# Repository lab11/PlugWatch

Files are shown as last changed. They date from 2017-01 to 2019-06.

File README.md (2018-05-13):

# PlugWatch



PlugWatch is part of the [GridWatch](http://grid.watch) project.

Unlike GridWatch, PlugWatch is not designed to run on everyday phones, rather it uses dedicated
smartphones as a sensor platform. PlugWatch is designed to be deployed as a semi-permanent installation,
with the phone constantly plugged into the power grid. PlugWatch also integrates with Bluetooth-enabled
commercial power meters, such as the [Wit Energy](http://www.wittech.net/WiTenergy.html), to collect
analytics such as line voltage not available to the phone alone.

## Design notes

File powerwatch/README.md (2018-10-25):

PowerWatch
==========

A custom PCB for identifying and distinguishing power outages. Acts as a source
of ground truth data for GridWatch.

Organized into different folders
./hardware - holds both board designs and case designs split by revision
./firmware - holds particle and nrf firmware split by revision
./cloud - holds the newest cloud backend infrastructure
./deployment-tools - holds all the software to support the deployment of physical devices and provision devices

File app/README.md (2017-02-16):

PlugWatch Application
=====================

This document describes the general behavoir of PlugWatch.

PlugWatch Operation
-------------------

PlugWatch runs the GridWatch service, which monitors the charging state of the phone and reports
a [GridWatch event](#gridwatch-event) whenever the charging state changes (note: unlike GridWatch,
PlugWatch reports every charge state event change, even if it was determined that this outage was
not due to a power outage).

PlugWatch also runs the WitCollect (**?? Name**) service, which connects to a nearby
[WiTenergy](http://www.wittech.net/WiTenergy.html) power meter to collect additional data. PlugWatch
samples Wit data every second (** DOUBLE CHECK **) and generates a [WitData](#witdata) entry for every sample (**and transmits every sample to the server in real time?? **).

**XXX is this right?**
GridWatch and Wit data are stored in a local database. PlugWatch creates a new database every 24
hours. Every 24 hours, PlugWatch performs a [BatchUpload](#batchupload) of yesterday's database.

In addition to its primary faculites, includes two diagnostics mechanism. First, every 24h the app
generates a [Heartbeat Ping](#heartbeat-ping) that simply sends a message to the server indicating
this phone is alive. Additionally, PlugWatch tracks [Internal Analytics](#internal-analytics),
which are used to diagnose the app and the deployment. These analytics leverage the Firebase tool
to automatically synchronize data **XXX often via an alaram / via FB on phone service?**

### GridWatch event

TODO: 

### WitData

TODO

### BatchUpload

TODO

### Heartbeat Ping

TODO

### Internal Analytics

These metrics are collected to diagnose the health of the PlugWatch app and deployment, and to help
diagnose issues that may arise.

Internal analytics are reported to Firebase via **XXX**, they are sent periodically via **XXX** or
on the following set of events **XXX (app restart, others?)**. **TODO:** Analytics reporting is throttled
to at most 1 report per hour.

**TODO: Update with actual names used in Firebase / data format**

_Reported as of 2017-02-14:_

  - All commands recevied
    - via SMS
    - via Firebase
  - Number of GridWatch events
  - App Version
  - IMEI
  - Phone Location
  - Phone Experimental ID
  - Phone Experimental Group ID
  - Number of databases
  - All crashes

_To add:_

  - Analytics ID counter
  - Packet counts
    - Bluetooth received
    - Cellular sent/received
  - Wakeup counts
    - Counter for each wakeup path in the app (each callback essentially)
  - Disk usage
  - App memory usage
  - Phone battery level
  - Current charging current
  - Estiamted app battery usage / imapact (w/e the OS gives)
  - Time phone last rebooted
  - Time app last rebooted
  - Time last analytics report sent (before this one)

Wishlist
--------

  - Nearby WiFi SSIDs
  - Compression for database sends. 
  - Periodic "Wit still not reachable" message transmissions - don't rely (solely) on watchdogs killing-and-restarting app to cause these to be generated only on re-start. As reliability increases may wish to have less aggressive watchdog that lets app running longer to increase chances of capturing exactly when power returns.
  - Option for "near" real-time bulk upload of Wit readings - e.g. N minutes worth at a time. Maybe only do bulk/trigger bulk send if voltage within a "normal" range.

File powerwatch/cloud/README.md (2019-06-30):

PowerWatch Cloud Services
=========================

The powerwatch cloud is a set of services that consume data from sensors,
store that data, visualize the data, manage the sensor deployment, send
feedback about performance to the field team, and pay our participants.

This is broken down in to a set of discrete services that run in K8s.

Some of these services (like timescale and grafana) are pre-existing and
we just write manifests for them. Some of them we write ourselves and 
build Docker containers for.

A picture of the current architecture is outlined below.



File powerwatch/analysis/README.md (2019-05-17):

Running PowerWatch Analysis
===========================

This folder is setup to execute pyspark scripts on a cloud dataproc cluster

These should work on any gcloud project with the dataproc enabled and billing enabled.

I usually use the powerwatch-backend gcloud project.

## Executing scripts

If you want to run one script you can simply 

```
$ ./execute.py my_analysis_folder/my_analysis_script.py
```

This script will in order
 - Check if a cluster exists, create a cluster if it does not. Cluster shuts down after 30 minutes of inactivity.
 - Setup the cluster environment to run the script (including drivers and such)
 - Execute the analysis script and pass in the results location
 - Copy the resulting csv(s) into the folder with the script
 - Hang until done and print output from the job

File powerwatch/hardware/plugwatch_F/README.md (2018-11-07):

# Plugwatch F
This sensor board is part of the [GridWatch](http://grid.watch) project.

Small fixes for at scale production of plugwatch.

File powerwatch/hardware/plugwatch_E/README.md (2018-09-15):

# Electron Sensor Board Rev 5
This sensor board is part of the [GridWatch](http://grid.watch) project.

Mostly a set of small fixes to the rev 4 board

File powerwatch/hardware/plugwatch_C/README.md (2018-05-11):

# Electron Sensor Board Rev 3
This sensor board is part of the [GridWatch](http://grid.watch) project.

The goal of this board is to test data collection in Accra. It contains 
an IMU with accel/mag and temp, two different microphones (one analog and
one digial), some memory, and a ultra-low power timer for future low-power 
optimizations. 

This directory will host development for all electron software and firmware.

Getting Started
---------------

Install the `particle-cli`, ideally just:

    npm install -g particle-cli

But I had to then also:

    npm i -g node-gyp
    ls ~/.particle     # note node version, mine was v5.4.1
    nvm use 5.4.1
    cd ~/.particle/node_modules/serialport
    node-gyp rebuild

Then blow out that terminal becase you don't really want that `nvm use` to persist.
If everything's hunky dory, you can now run `particle --version` or some such.

#### Installing dfu-util For Flashing Firmware

In order to use "particle flash" to locally re-flash the Electron firmware over USB, you will need dfu-util installed. On MacOS this should be sufficient:

    brew install dfu-util
    
Particle docs have more details for getting them on Windows or with MacPorts: https://docs.particle.io/faq/particle-tools/installing-dfu-util/core/

### Compiling

    particle compile electron
    
#### Using the Particle IDE

Particle has extended the Atom IDE to make a "Particle Dev" app: https://docs.particle.io/guide/tools-and-features/dev/

It's really not that different that the web IDE, including actually sending compilation to their cloud, but it allows you to work with local git-controlled files (like these!), and also importantly doesn't have the horrible mouse scrolling behavior of the web IDE that often leads to accidental "browser back" commands that lose your edits.

Install Particle Dev from the link above, run it, and:

* File->Open-> navigate to the `software/firmware/` directory of this code and select "open" (do not choose any individual file in it).
* Choose `Electron` as the target device in the bottom bar icon (may default to `Photon`). NOTE: you may have to do this regularly (e.g. every time you restart the IDE or re-open your project).
* Log in to your particle account if it doesn't show you already logged in (left side of bottom bar or Particle-> menu).
* Compile using the Cloud+Checkmark icon in the left bar.
    
If all goes well you should see `Compiling in the cloud...` in the bottom bar and then a `Success!` message, and the firmware binary should appear in the `firmware/` directory with a name that looks like `electron_0.7.0_firmware_XXXXXXXX.bin`.

Note: if you hit the compile button and it instantly reports `Success!` without delay, and doesn't actually produce a firmware image, it probably means that despite showing you aslogged in that you need to logout and re-login.

#### Compiling Locally

The paricle CLI and IDE will use the cloud still, which is annoyingly slow IMHO.
While there's theoretically a path to _actual_ local compilation, down that road
lies madness. Your best bet is their [Atom plugin](https://atom.io/packages/particle-dev-local-compiler).
You'll need to install and run Docker first, then in Particle Dev go to Settings->Install, search for 
"Particle Dev Local Compiler" and click install. Compiles are still slower than I'd like,
but only a few seconds at least. 

#### Cryptic error / error you didn't have before?

For example `error: 'LOW_BAT_UC' was not declared in this scope`

Make sure that you're building for the right device (an `electron`).
The IDE in particular tends to like to forget what you're building for,
especially across open/closing.

### Claim the particle (must do once)

  0. Plug in particle via USB
  1. Enter 'listening mode': Hold `MODE` button for three seconds, until the
     LED starts blinking blue.
  2. `particle identify`
  3. `particle device add <device id from last step>`

### Flashing

  1. Enter 'dfu mode': Reset and then hold `MODE` button for three seconds,
     until the LED starts blinking yellow.
  2. `particle flash --usb <filename>.bin`
  
#### Flashing made easier

`stty -f /dev/tty.usbmodem14321 14400 && particle flash --usb $(ls -t | grep firmware | head -1)`

The first part puts the particle into DFU mode. Note that you'll need to replace the `14321` in the above with whatever ID the USB Particle shows up on your machine (just use tab-completion).  The last part chooses the most
recent file based on filesystem timestamp.
  
### Listening to Serial

I recommend `particle serial monitor --follow`

Annoyingly, every time the particle resets, the modem disappears and reappears.
The `--follow` flag will automatically reconnect, but there's a bit of a delay,
so you're gonna lose the first few messages. I've never solved this puzzle.

### Listening to the Event Stream

The `Particle.publish()` command allows electron-initiated events to be published to the Particle Cloud; webhooks can then be used to do something with these events. However webhooks need to be specified per event name (or event name's starting prefix), which is somewhat obnoxious for development. 

Thankfully the entire event-stream for a Particle "product" is available as an HTML5 Server Side Event; the stream is accessible per-product via a URL like https://api.particle.io/v1/products/PRODUCT_SLUG/events?access_token=TOKENVALUE

where `PRODUCT_SLUG` (Particle terminology) is the short alpha-numeric name of the product (to get this click on a specific product in the Particle web console https://console.particle.io/products and pull the "slug" from the resulting URL, e.g. https://console.particle.io/PRODUCT_SLUG/devices).

#### Generating an API Token

As you see above the API requires an access token; this can be generated from the Web UI but the following code is useful for generating one with no expiration (which can be useful to avoid a situation like where your curl script for dumping the event stream doesn't check for API access errors and thus you get email from Particle complaining about hammering their API with failed authentication attempts):

`curl https://api.particle.io/oauth/token -u particle:particle -d grant_type=password -d 'username=YOUR_PARTICLE_ACCOUNT_EMAIL_ADDRESS' -d 'password=YOUR_PARTICLE_ACCOUNT_PASSWORD’ -d 'expires_in=0'`

The particle account should be one with access to the product(s) whose event streams you want to listen to. `particle:particle` is *NOT* a placeholder; it's ignored so you can leave it as is. The `-d 'expires_in=0'` is the key to creating the infinite-life token. If successful you should see curl return something like:

`{"token_type":"bearer","access_token":"0123456789abcdef0123456789abcdef01234567",
{"token":"0123456789abcdef0123456789abcdef01234567","expires_at":null,"client":"__PASSWORD_ONLY__"}`

You can then paste the `access_token` value into the `TOKENVALUE` part of the API URL above.

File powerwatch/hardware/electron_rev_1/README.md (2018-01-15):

# Electron Sensor Board Rev 1
This sensor board is part of the [GridWatch](http://grid.watch) project.

The goal of this board is to test data collection in Accra. It contains 
an IMU with accel/mag and temp, two different microphones (one analog and
one digial), some memory, and a ultra-low power timer for future low-power 
optimizations. 

The current version is built to be deployed inside. Eventually, this platform
will be both indoors and solar powered. Right now, the peripherals are not
selected for low power... Instead, they are selected because I've used them before. 

Eventually, there will only be a single type of microphone. I believe this will be
the digital mic, but I don't have the I2S driver written yet, so I'm including the 
analog mic as a backup. 

We will likely be building 10 of these and then redesigning.

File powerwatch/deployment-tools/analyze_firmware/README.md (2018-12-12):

Analyze Firmware
==========================

Prints product ID and version of firmware.

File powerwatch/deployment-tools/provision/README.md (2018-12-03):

Particle provisioning script
===========================

The script performs several functions:

1) Updates the core firmware on each particle to 0.7.0
2) Flashes the pre-deploy firmware which waits for a firmware update
3) Gets the device ID of the particle and appends it to a google spreadsheet for tracking
4) Gets the board ID of a particle to associate it with a specific plugwatch board
4) prints labels with the board ID and device ID for the plugwatch cases

## Usage

### Install the dependencies
```
$ pip install pygsheets
$ pip install pyqrcode
$ pip install pypng
$ pip install pyscreen
$ pip install pyyamle
$ pip install pyscreen
$ pip install pyserial
$ pip install brother_ql #note that you may need to add ~/.local/bin to your path
$
$ npm install -g particle-cli
```

You need to install dfu util - this is system dependent, but on mac
```
$ brew install dfu-util
```

Note that you may need to install brother_ql with sudo -H to be able to access
it when you run the claim script as sudo.

### Setup keys

https://pygsheets.readthedocs.io/en/latest/authorization.html

At a high level you need to enable the google drive and google sheets APIs,
the create a consent form and a client oauth crediential.

You must also put a valid particle auth token in the particle-config.json file

### Run the script

Connect the particle and the printer to run the script.

```
$ sudo ./claim.py -p PRODUCT_ID
```

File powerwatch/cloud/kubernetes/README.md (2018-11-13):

Deploying a Powerwatch Backend
==============================

## Requirements

To deploy a powerwatch backend instance you need to have google cloud installed
and logged into a google account which has been granted an admin role on the 
powerwatch-backend project.

To check:
```
gcloud config set project powerwatch-backend
```

## Start a new powerwatch backend

To startup a new powerwatch backend you should 
run the provisioning script with the deployment name and particle product IDs
```
$ ./powerwatch_provision.py --name venezuela --product 7300 --product 7301
```

This will perform the following steps

1) Create a default cluster in gcloud under the powerwatch-backend project
2) Generate, substitute and print passwords for the following individual services:
timescale (admin user, poster user, grafana user)
influxdb (admin user, poster user, grafana user)
grafana (admin user)
3) Generate and substitute a particle auth token for those products
4) Packages up all the deployment files and 
save them to a deployment folder
5) Deploy a new timescale, influx, grafana, and the powerwatch poster services
to the target cluster
6) Print the IP address of the grafana ingress so that you can configure a new
subdomain for this deployment's grafana

## Update a powerwatch backend
The powerwatch-data-poster and powerwatch-visualization pods are custom pods
running images hosted by the lab11 docker hub. They are currently set to pull
the production branch of this repository. To update these images:

1) Push your changes to the production branch (probably just merge production with master or test).
2) Wait for docker hub to build the images
3) Pull the images - copy down their sha256 hash
```
$ docker pull lab11/container-name:production
```
4) Point your kubectl at the cloud cluster you are updating (copy the 'connect' command text from the gcloud web UI)
5) Update the images to the sha256 hash. For instance to update the influx poster run the following command:
```
$ kubectl set image deployment powerwatch-data-poster powerwatch-influx-poster=lab11/powerwatch-influx-poster@sha256:HASH
```

You can also update multiple images at once. This will perform a no-downtime rolling update of the containers that you specified.

Pointing to a commit hash is better than a branch because it enables easier rollback and it is easier to identify exactly
which version of a container you are running (if you just pull the 'production' container 
docker hub's production tag will get out of sync with the tag running in the cluster as more commits are pushed).

## Future Work

There are several clear things that need updating moving forward:

 - The internal cluster communications should use SSL
 - We need to get the powerwatch visualization up and running and get its SSL working
 - Make a splash page for the each deployment
 - Potential hooks to lastpass for password storage for the group

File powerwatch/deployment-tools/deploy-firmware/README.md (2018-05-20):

Firmware Deployment Script
==========================

The firmware deployment script takes a product binary, uploads it,
releases it to a product, then locks all devices in that product
to the firmware release.

The locking step seems to help devices better upgrade. I don't really understand
why that is the case.

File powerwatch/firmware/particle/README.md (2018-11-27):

Plugwatch sensor firmware
=========================

This folder holds all firmware running on plugwatch sensors. Currently
the two active sub-folders are plugwatch_C and plugwatch_F. 
Other folders hold testing revisions.

Firmware versioning is a 6 digit decimal number. 
Plugwatch C firmware starts at 000000 and plugwatch F firmware starts at 000100.

##Revision list
 - 000026 - Currently deployed on Ghana and Venezuela
 - 0000100 - The most recent version of the new firmware. Still in development, not deployed.

##To deploy firmware

 1) Commit your changes with the new version number.
 2) Build the versions for all of the product IDs and APNs - a script to do this will be coming soon.
 3) Push your builds to the particle cloud using the firmware deployment script - soon to be modified to take a folder of builds
 4) Commit the most recent firmware build folder

Getting Started with Firmware Development
-----------------------------------------

Install the `particle-cli`, ideally just:

    npm install -g particle-cli

But I had to then also:

    npm i -g node-gyp
    ls ~/.particle     # note node version, mine was v5.4.1
    nvm use 5.4.1
    cd ~/.particle/node_modules/serialport
    node-gyp rebuild

Then blow out that terminal becase you don't really want that `nvm use` to persist.
If everything's hunky dory, you can now run `particle --version` or some such.

### Compiling

    particle compile electron
    
#### Compiling Locally

The paricle CLI will use the cloud still, which is annoyingly slow IMHO.
While there's theoretically a path to _actual_ local compilation, down that road
lies madness. Your best bet is their [Atom plugin](https://atom.io/packages/particle-dev-local-compiler).
You'll need to install Docker first. Compiles are still slower than I'd like,
but only a few seconds at least.

#### Cryptic error / error you didn't have before?

For example `error: 'LOW_BAT_UC' was not declared in this scope`

Make sure that you're building for the right device (an `electron`).
The IDE in particular tends to like to forget what you're building for,
especially across open/closing.

### Claim the particle (must do once)

  0. Plug in particle via USB
  1. Enter 'listening mode': Hold `MODE` button for three seconds, until the
     LED starts blinking blue.
  2. `particle identify`
  3. `particle device add <device id from last step>`

### Flashing

  1. Enter 'dfu mode': Reset and then hold `MODE` button for three seconds,
     until the LED starts blinking yellow.
  2. `particle flash --usb <filename>.bin`
  
#### Flashing made easier

`stty -f /dev/tty.usbmodem14321 14400 && particle flash --usb $(ls -t | grep firmware | head -1)`

The first part puts the particle into DFU mode. The last part chooses the most
recent file based on filesystem timestamp.
  
### Listening to Serial

I recommend `particle serial monitor --follow`

Annoyingly, every time the particle resets, the modem disappears and reappears.
The `--follow` flag will automatically reconnect, but there's a bit of a delay,
so you're gonna lose the first few messages. I've never solved this puzzle.

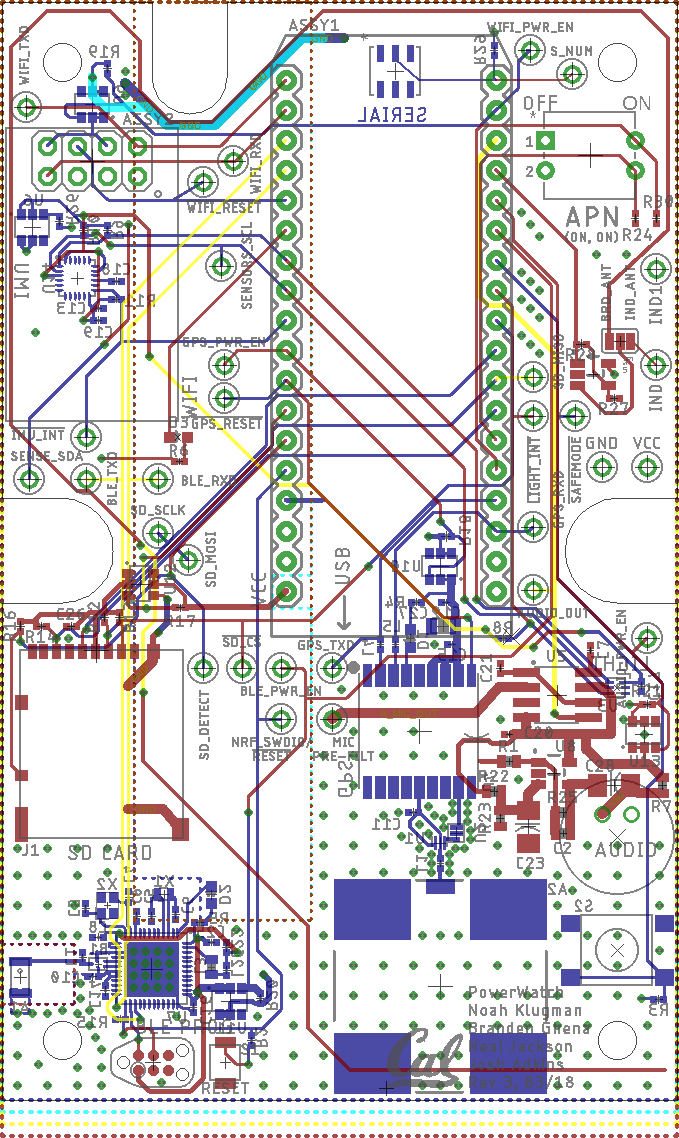
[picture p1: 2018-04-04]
powerwatch/hardware/plugwatch_C/board/plugwatch_pcb.png

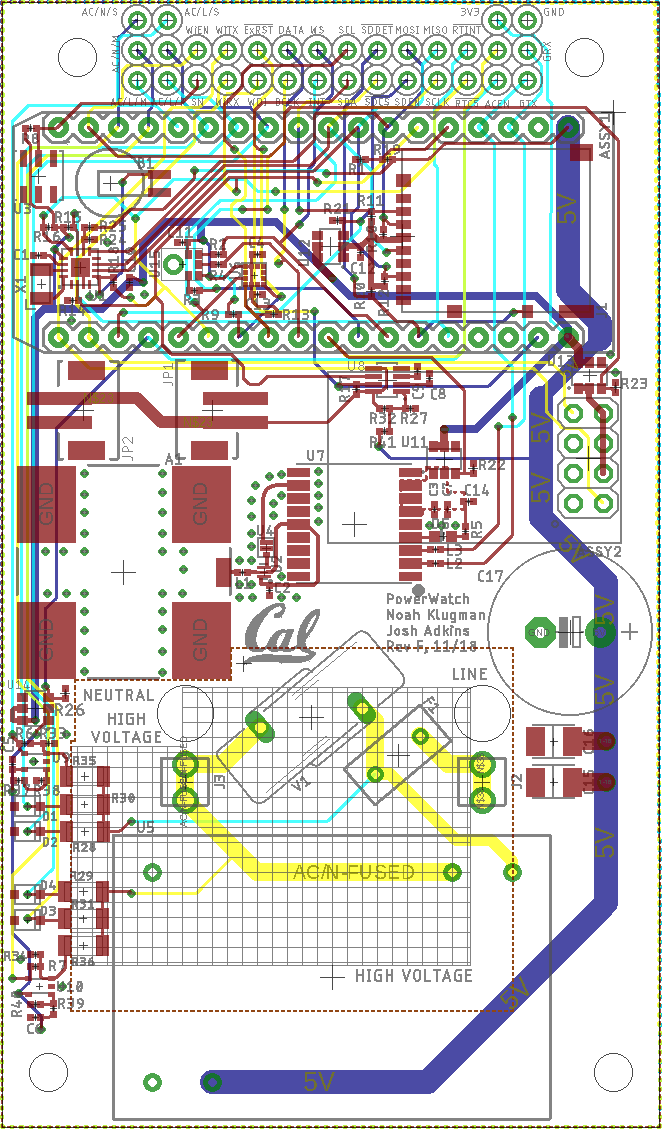
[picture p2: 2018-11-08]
powerwatch/hardware/plugwatch_F/board/plugwatch_pcb.png

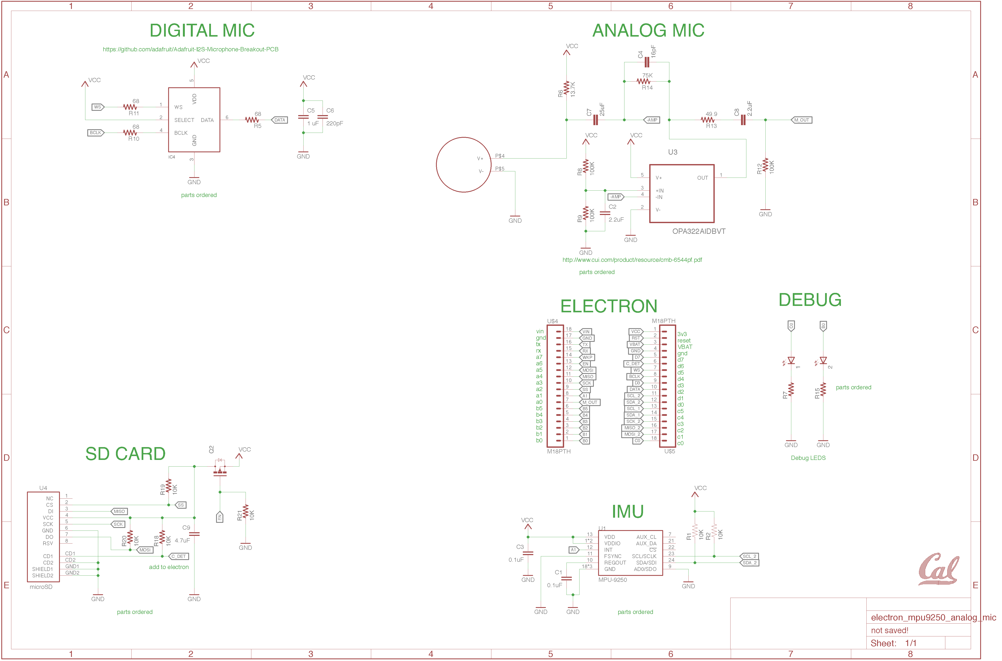
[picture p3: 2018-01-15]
powerwatch/hardware/electron_rev_1/schematic_image.png

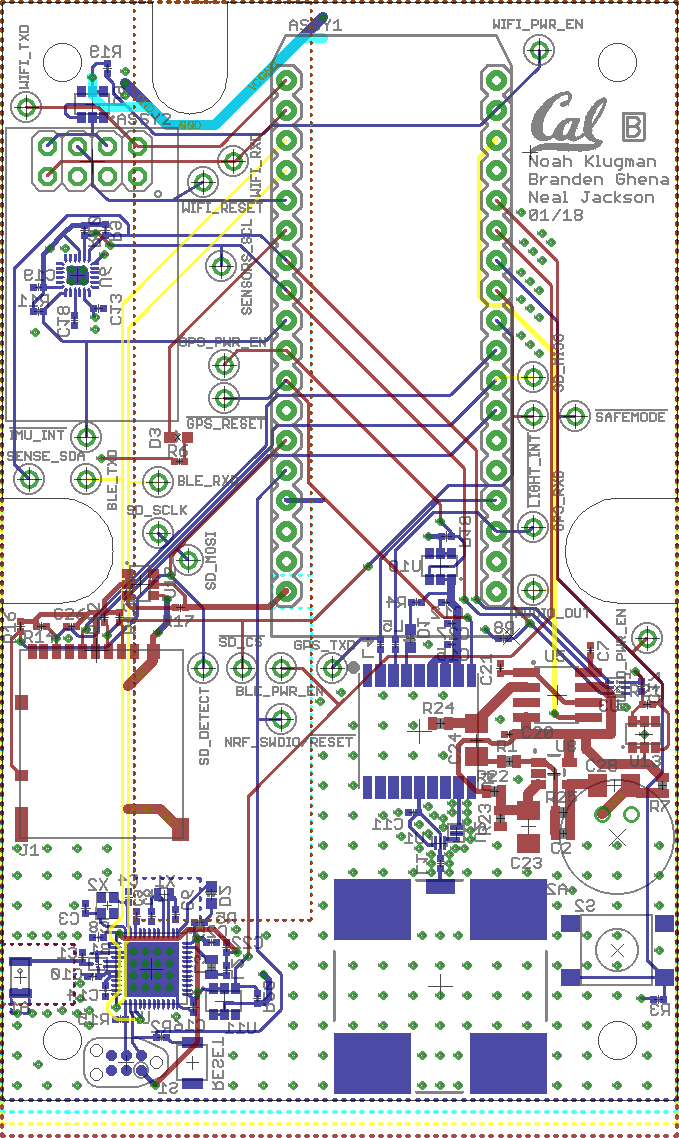
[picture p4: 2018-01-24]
powerwatch/hardware/plugwatch_B/board/plugwatch_pcb.png

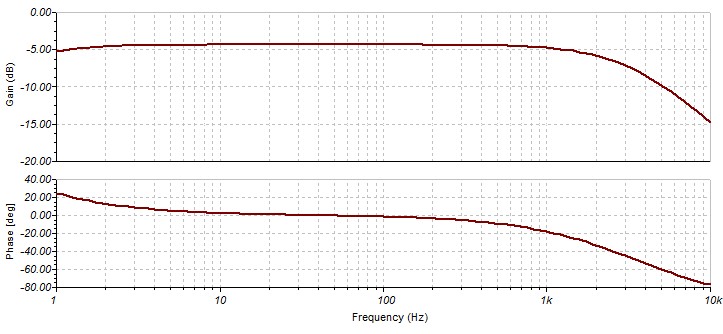
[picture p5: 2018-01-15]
powerwatch/hardware/plugwatch_B/board/simulation/transfer_function.jpg

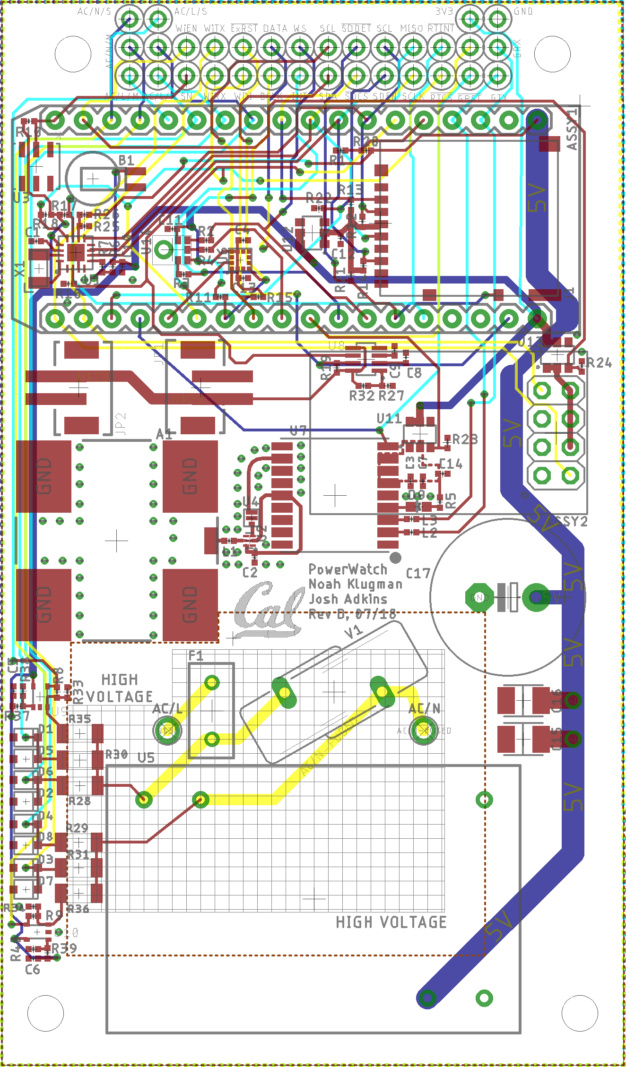
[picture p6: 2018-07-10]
powerwatch/hardware/plugwatch_D/board/plugwatch_pcb.png

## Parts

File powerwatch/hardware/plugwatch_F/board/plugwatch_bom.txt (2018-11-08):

# Bill of Materials
# Converted from plugwatch_bom.xlsx
# Generated by bom_to_text.py
#
# # Bill of Materials                                                                                                                                                                                                                                                                                                                                             
# # Converted from {}                                                                                                                                                                                                                                                                                                                                             
# # Generated by bom_to_text.py                                                                                                                                                                                                                                                                                                                                   
# #                                                                                                                                                                                                                                                                                                                                                               
#                                                                                                                                                                                                                                                                                                                                                                 
# Qty                            Value                  Device                           Package                  Parts                                   Description                                                      DESCRIPTION                       DIGIKEY                  MANUFACTURER                      MOUSER             MPN                    SPICEPREFIX
4                                                       DIODE_ZENERSOT323                SOD323                   D1,D2,D3,D4                                                                                              DIODE ZENER 3.3V 200MW SOD323F    MM3Z3V3BCT-ND            ON Semiconductor                                     MM3Z3V3B               
2                                                       M024UCON-15767                   JST-2-SMD-VERT           JP1,JP2                                 Header 2                                                         CONN HEADER PH TOP 2POS 2MM SMD   455-1734-1-ND            JST Sales America Inc.                               B2B-PH-SM4-TB(LF)(SN)  
1                                                       MS518SE                          MS518SE-FL35E            B1                                      A small, low leakage rechargeable battery for RTC backup                                           728-1054-ND              Seiko                                                MS518SE-FL35E          
1                                                       SPH0645LM4H-B                    SPH0465                  U15                                     An I2S microphone down to 20hz                                                                     423-1405-1-ND            Knowles                           721-SPH0645LM4H-B  SPH0645LM4H-B          
4                                0.1uF                  CAPACITOR0402_CAP                0402_CAP                 C4,C5,C6,C7                             SMD Capacitor                                                    CAP CER 0.1UF 10V X5R 0402        311-1336-1-ND            Yageo                                                CC0402KRX5R6BB104      
1                                0.82uF                 CAPACITOR0402_CAP                0402_CAP                 C9                                      SMD Capacitor                                                                                      490-10440-1-ND           Murata Electronics North America                     GRM155C80J824KE15D     
7                                100k                   RESISTOR0402_RES                 0402_RES                 R20,R21,R22,R23,R24,R25,R26             Resistor                                                         RES SMD 100K OHM 1% 1/16W 0402    311-100KLRCT-ND          Yageo                                                RC0402FR-07100KL       
2                                100uF                  CAPACITOR1210_CAP                1210_CAP                 C15,C16                                 SMD Capacitor                                                    CAP CER 100UF 10V X5R 1210        490-9969-6-ND            Murata Electronics North America                     GRM32ER61A107ME20L     
10                               10k                    RESISTOR0402_RES                 0402_RES                 R9,R10,R11,R12,R13,R14,R15,R16,R17,R18  Resistor                                                         RES SMD 10K OHM 1% 1/16W 0402     311-10.0KLRCT-ND         Yageo                                                RC0402FR-0710KL        
2                                10nF                   CAPACITOR0402_CAP                0402_CAP                 C2,C3                                   SMD Capacitor                                                    CAP CER 10000PF 16V X7R 0402      490-4762-1-ND            Murata Electronics North America                     GCM155R71H103KA55D     
2                                10uF                   CAPACITOR0402_CAP                0402_CAP                 C13,C14                                 SMD Capacitor                                                    CAP CER 10UF 6.3V X5R 0402        490-13211-1-ND           Murata Electronics North America                     GRJ155R60J106ME11D     
4                                1M                     RESISTOR0402_RES                 0402_RES                 R37,R38,R39,R40, R41                    Resistor                                                         RES 1M OHM 1% 1/16W 0402          311-1.00MLRCT-ND         Yageo                                                RC0402FR-071ML         
2                                1k                     FERRITE_BEAD0402                 0402_CAP                 L2,L3                                                                                                    FERRITE BEAD 1 KOHM 0402 1LN      490-4003-1-ND            Murata                                               BLM15HD102SN1D         
1                                1k                     RESISTOR0402_RES                 0402_RES                 R5                                      Resistor                                                         RES SMD 1K OHM 1% 1/16W 0402      311-1.00KLRCT-ND         Yageo                                                RC0402FR-071KL         
2                                1uF                    CAPACITOR0402_CAP                0402_CAP                 C10,C11                                 SMD Capacitor                                                    CAP CER 1UF 10V X7S 0402          490-13409-1-ND           Murata Electronics North America                     GCM155C71A105KE38D     
1                                2.2uF                  CAPACITOR0402_CAP                0402_CAP                 C8                                      SMD Capacitor                                                                                      490-10448-1-ND           Murata Electronics North America                     GRM155D71A225ME15D     
1                                2000uF                 CPOL-USE5-13                     E5-13                    C17                                     POLARIZED CAPACITOR, American symbol                             CAP ALUM 2000UF 20% 6.3V T/H      P122284TB-ND             Panasonic Electronic Components                      EEU-FS0J202B           C
1                                300VAC - 500ma         MICRO_FUSE500MA_350VAC           MIRCRO_FUSE_5MM          F1                                      A 5mm AC micro fuse package                                      FUSE BRD MNT 500MA 350VAC 100VDC  507-1903-ND              Bel Fuse Inc                                         0697H0500-01           
1                                34k                    RESISTOR0402_RES                 0402_RES                 R19                                     Resistor                                                         RES SMD 34K OHM 1% 1/10W 0402     P34.0KLCT-ND             Panasonic Electronic Components                      ERJ-2RKF3402X          
1                                4.7uF                  CAPACITOR0402_CAP                0402_CAP                 C12                                     SMD Capacitor                                                    CAP CER 4.7UF 6.3V X5R 0402       490-5408-1-ND            Murata Electronics North America                     GRM155R60J475ME87D     
2                                4.99k                  RESISTOR0402_RES                 0402_RES                 R6,R7                                   Resistor                                                         RES SMD 4.99K OHM 1% 1/10W 0402   P4.99KLCT-ND             Panasonic Electronic Components                      ERJ-2RKF4991X          
1                                47pF                   CAPACITOR0402_CAP                0402_CAP                 C1                                      SMD Capacitor                                                    CAP CER 47PF 100V C0G/NP0 0402    490-7307-1-ND            Murata Electronics North America                     GRM1555C2A470JA01D     
1                                499k                   RESISTOR0402_RES                 0402_RES                 R27                                     Resistor                                                         RES SMD 499K OHM 1% 1/10W 0402    P499KLCT-ND              Panasonic Electronic Components                      ERJ-2RKF4993X          
1                                5.1k                   RESISTOR0402_RES                 0402_RES                 R8                                      Resistor                                                         RES SMD 5.1K OHM 1% 1/10W 0402    P5.10KLCT-ND             Panasonic Electronic Components                      ERJ-2RKF5101X          
1                                5.6nH                  INDUCTOR0402                     0402_CAP                 L1                                      A very specific inductor                                         FIXED IND 5.6NH 1.77A 40 MOHM     490-11766-1-ND           Murata                                               LQW15AN5N6B80D         
1                                66.5                   RESISTOR0402_RES                 0402_RES                 R1                                      Resistor                                                         RES SMD 66.5 OHM 1% 1/16W 0402    YAG3210CT-ND             Yageo                                                RC0402FR-0766R5L       
3                                68                     RESISTOR0402_RES                 0402_RES                 R2,R3,R4                                Resistor                                                         RES SMD 68 OHM 1% 1/16W 0402      P68.0LCT-ND              Panasonic Electronic Components                      ERJ-2RKF68R0X          
4                                750k                   RESISTOR1206_RES_HIGH_CLEARANCE  1206_RES_HIGH_CLEARANCE  R28,R29,R30,R31                         Resistor                                                         RES SMD 750K OHM 1% 1/4W 1206     311-750KFRCT-ND          Yageo                                                RC1206FR-07750KL       
1                                825k                   RESISTOR0402_RES                 0402_RES                 R32                                     Resistor                                                         RES SMD 825K OHM 1% 1/10W 0402    P825KLCT-ND              Panasonic Electronic Components                      ERJ-2RKF8253X          
2                                953k                   RESISTOR0402_RES                 0402_RES                 R33,R34                                 Resistor                                                         RES SMD 953K OHM 1% 1/16W 0402    YAG3262CT-ND             Yageo                                                RC0402FR-07953KL       
2                                953k                   RESISTOR1206_RES_HIGH_CLEARANCE  1206_RES_HIGH_CLEARANCE  R35,R36                                 Resistor                                                                                           P953KBCCT-ND             Panasonic Electronic Components                      ERA-8AEB9533V          
1                                AB1815-T3              AB1815-T3                        QFN-16-3MM               U1                                      Ultra-low current RTC. 55nA quiescent @ 3V. 1.5-3.6V input.                                        535-11936-1-ND           Abracon                                              AB1815-T3              
1                                ABS07-32.768KHZ-7-T    ABS07-32.768KHZ-7-T              2-SMD                    X1                                      32.768kHz Crystal                                                                                  535-9543-1-ND            ABRACON                                              ABS07-32.768KHZ-7-T    
1                                BGA725L6-ALT           BGA725L6-ALT                     LNA-TSLP-6-2-ALT         U2                                                                                                       IC AMP MMIC RF LNA 20DB TSLP-6    BGA725L6E6327FTSA1CT-ND  Infineon                                             BGA725L6E6327FTSA1     
1                                BLUE                   LED0603                          LED-0603                 D5                                      LED                                                              LED BLUE CLEAR SMD                160-1837-6-ND            Lite-On Inc.                                         LTST-C194TBKT          
1                                DM3AT-SF-PEJM5         DM3AT-SF-PEJM5                   DM3AT-SF-PEJM5           J1                                      CONN MICRO SD R/A PUSH-PUSH SMD                                  CONN MICRO SD CARD PUSH-PUSH R/A  HR1964CT-ND              Hirose Electric Co Ltd                               DM3AT-SF-PEJM5         
1                                DS2401P+               DS2401P+                         21-0382                  U3                                      A one wire serial number chip.                                                                     DS2401P+-ND              Maxim Integrated                                     DS2401P+               X
1                                ELECTRON               ELECTRON                         ELECTRON_SINGLE-ROW      ASSY1                                                                                                    18 Position header                S7051-ND,S7051-ND        Sullins                                              PPPC181LFBN-RC         
1                                GPS-ANTENNA            GPS-ANTENNA                      ANT1818B00BT1516S        A1                                                                                                       PATCH ANT GPS/GLO CP SMD          311-1531-ND              Yageo                                                ANT1818B00BT1516S      
1                                IRM-03-5V              IRM-03-5V                        IRM-03                   U5                                      A 5V 3W board mount power supply                                                                   1866-3020-ND             Mean Well USA                                        IRM-03-5               
1                                LIS2DH12               LIS2DW12                         LGA-12                   U6                                      ultra low power 3 axis accelerometer                                                               497-14851-1-ND           STMicroelectronics                511-LIS2DH12TR     LIS2DH12TR             
1                                MAX-M8                 MAX-M8                           MAX-M8                   U7                                                                                                       IC RECEIVER GPS/GNSS 18LCC        672-1003-1-ND            u-blox                                               MAX-M8Q-0              
1                                MAX67XXMAX6749MAX67XX  MAX67XXMAX6749MAX67XX            SOT-23-8                 U8                                      A simple watchdog timer with adjustable timeouts and reset time                                    MAX6749KA+TCT-ND         Maxim Integrated                                     MAX6749KA+T            
2                                OPA369                 OPA369                           SC70-5                   U9,U10                                                                                                                                     296-25252-1-ND           Texas Instruments                                    OPA369AIDCKR           
1                                S14K385                S14K385                          S14K385                  V1                                      VARISTOR                                                         VARISTOR 620V 5KA DISC 14MM       495-5945-ND              EPCOS (TDK)                                          B72214S2381K101        
1                                SAFFB1G56KB0F0A        FILTERS                          QCS5I                    U4                                                                                                       FILTER SAW 1.582GHZ 5SMD          587-3990-1-ND            Taiyo Yuden                                          F6QA1G582H2JM-J        
2                                SCREW_TERMNIAL_1       SCREW_TERMNIAL_1                 360272-TERMINAL-BLOCK    J2,J3                                   A small, single terminal block                                                                     1849-1246-ND             METZ CONNECT USA Inc.                                360272                 
4                                SIP32510               SIP32510                         TSOT23-6                 U11,U12,U13,U14                         Load switch, slew rate controlled. By Vishay                                                       SIP32510DT-T1-GE3CT-ND   Vishay                                               SIP32510DT-T1-GE3      
1                                WRL-13678              WRL-13678                        WRL-13678                ASSY2                                   ESP8266 WiFi Module                                                                                1568-1235-ND

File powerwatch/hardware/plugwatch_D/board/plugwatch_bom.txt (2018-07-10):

# Bill of Materials
# Converted from plugwatch_bom.xlsx
# Generated by bom_to_text.py
#
# # Bill of Materials                                                                                                                                                                                                                                                                                                                                                                                                                                                             
# # Converted from {}                                                                                                                                                                                                                                                                                                                                                                                                                                                             
# # Generated by bom_to_text.py                                                                                                                                                                                                                                                                                                                                                                                                                                                   
# #                                                                                                                                                                                                                                                                                                                                                                                                                                                                               
#                                                                                                                                                                                                                                                                                                                                                                                                                                                                                 
# Qty                            Value                  Device                           Package                  Parts                                                                                                                                                   Description                                                      DESCRIPTION                       DIGIKEY                  MANUFACTURER                      MOUSER             MPN                    SPICEPREFIX
4                                                       DIODE_SCHOTTKYSOD323             SOD323                   D1,D2,D3,D4                                                                                                                                                                                                                                                CUS10S30H3FCT-ND         toshiba                                              CUS10S30,H3F           
4                                                       DIODE_ZENERSOT323                SOD323                   D5,D6,D7,D8                                                                                                                                                                                                              DIODE ZENER 3.3V 200MW SOD323F    MM3Z3V3BCT-ND            ON Semiconductor                                     MM3Z3V3B               
2                                                       M024UCON-15767                   JST-2-SMD-VERT           JP1,JP2                                                                                                                                                 Header 2                                                         CONN HEADER PH TOP 2POS 2MM SMD   455-1734-1-ND            JST Sales America Inc.                               B2B-PH-SM4-TB(LF)(SN)  
1                                                       MS518SE                          MS518SE-FL35E            B1                                                                                                                                                      A small, low leakage rechargeable battery for RTC backup                                           728-1054-ND              Seiko                                                MS518SE-FL35E          
1                                                       SPH0645LM4H-B                    SPH0465                  U14                                                                                                                                                     An I2S microphone down to 20hz                                                                                              Knowles                           721-SPH0645LM4H-B  SPH0645LM4H-B          
4                                0.1uF                  CAPACITOR0402_CAP                0402_CAP                 C4,C5,C6,C7                                                                                                                                             SMD Capacitor                                                    CAP CER 0.1UF 10V X5R 0402        311-1336-1-ND            Yageo                                                CC0402KRX5R6BB104      
1                                0.82uF                 CAPACITOR0402_CAP                0402_CAP                 C9                                                                                                                                                      SMD Capacitor                                                                                      490-10440-1-ND           Murata Electronics North America                     GRM155C80J824KE15D     
2                                1.5k                   RESISTOR0402_RES                 0402_RES                 R6,R7                                                                                                                                                   Resistor                                                         RES SMD 1.5K OHM 0.1% 1/16W 0402  P1.5KDCCT-ND             Panasonic Electronic Components                      ERA-2AEB152X           
6                                100k                   RESISTOR0402_RES                 0402_RES                 R21,R22,R23,R24,R25,R26                                                                                                                                 Resistor                                                         RES SMD 100K OHM 1% 1/16W 0402    541-100KLCT-ND           Vishay Dale                                          CRCW0402100KFKED       
2                                100uF                  CAPACITOR1210_CAP                1210_CAP                 C15,C16                                                                                                                                                 SMD Capacitor                                                    CAP CER 100UF 6.3V X7S 1210       490-10530-1-ND           Murata Electronics North America                     GRM32EC70J107ME15L     
9                                10k                    RESISTOR0402_RES                 0402_RES                 R11,R12,R13,R14,R15,R16,R17,R18,R19                                                                                                                     Resistor                                                         RES SMD 10K OHM 1% 1/16W 0402     RMCF0402FT10K0CT-ND      Stackpole Electronics Inc.                           RMCF0402FT10K0         
2                                10nF                   CAPACITOR0402_CAP                0402_CAP                 C2,C3                                                                                                                                                   SMD Capacitor                                                    CAP CER 10000PF 16V X7R 0402      490-1313-1-ND            Murata Electronics North America                     GRM155R71C103KA01D     
2                                10uF                   CAPACITOR0402_CAP                0402_CAP                 C13,C14                                                                                                                                                 SMD Capacitor                                                    CAP CER 10UF 6.3V X5R 0402        490-13211-1-ND           Murata Electronics North America                     GRJ155R60J106ME11D     
4                                1M                     RESISTOR0402_RES                 0402_RES                 R37,R38,R39,R40                                                                                                                                         Resistor                                                         RES 1M OHM 1% 1/16W 0402          RMCF0402FT1M00CT-ND      Stackpole Electronics Inc.                           RMCF0402FT1M00         
2                                1k                     FERRITE_BEAD0402                 0402_CAP                 L2,L3                                                                                                                                                                                                                    FERRITE BEAD 1 KOHM 0402 1LN      490-4003-1-ND            Murata                                               BLM15HD102SN1D         
1                                1k                     RESISTOR0402_RES                 0402_RES                 R5                                                                                                                                                      Resistor                                                         RES SMD 1K OHM 1% 1/16W 0402      RMCF0402FT1K00CT-ND      Stackpole Electronics                                RMCF0402FT1K00         
2                                1uF                    CAPACITOR0402_CAP                0402_CAP                 C10,C11                                                                                                                                                 SMD Capacitor                                                    CAP CER 1UF 10V X7S 0402          490-13409-1-ND           Murata Electronics North America                     GCM155C71A105KE38D     
1                                2.2uF                  CAPACITOR0402_CAP                0402_CAP                 C8                                                                                                                                                      SMD Capacitor                                                                                      490-12696-1-ND           Murata Electronics North America                     GRM155C70J225KE11D     
1                                2000uF                 CPOL-USE5-13                     E5-13                    C17                                                                                                                                                     POLARIZED CAPACITOR, American symbol                             CAP ALUM 2000UF 20% 6.3V T/H      P122284TB-ND             Panasonic Electronic Components                      EEU-FS0J202B           C
1                                300VAC - 500ma         MICRO_FUSE500MA_350VAC           MIRCRO_FUSE_5MM          F1                                                                                                                                                      A 5mm AC micro fuse package                                      FUSE BRD MNT 500MA 350VAC 100VDC  507-1903-ND              Bel Fuse Inc                                         0697H0500-01           
1                                34k                    RESISTOR0402_RES                 0402_RES                 R20                                                                                                                                                     Resistor                                                         RES SMD 34K OHM 1% 1/10W 0402     P34.0KLCT-ND             Panasonic Electronic Components                      ERJ-2RKF3402X          
1                                4.7uF                  CAPACITOR0402_CAP                0402_CAP                 C12                                                                                                                                                     SMD Capacitor                                                    CAP CER 4.7UF 6.3V X5R 0402       445-5947-1-ND            TDK                                                  C1005X5R0J475K050BC    
2                                4.99k                  RESISTOR0402_RES                 0402_RES                 R8,R9                                                                                                                                                   Resistor                                                         RES SMD 4.99K OHM 1% 1/10W 0402   P4.99KLCT-ND             Panasonic Electronic Components                      ERJ-2RKF4991X          
1                                47pF                   CAPACITOR0402_CAP                0402_CAP                 C1                                                                                                                                                      SMD Capacitor                                                    CAP CER 47PF 100V C0G/NP0 0402    490-7307-1-ND            Murata Electronics North America                     GRM1555C2A470JA01D     
1                                499k                   RESISTOR0402_RES                 0402_RES                 R27                                                                                                                                                     Resistor                                                         RES SMD 499K OHM 1% 1/10W 0402    P499KLCT-ND              Panasonic Electronic Components                      ERJ-2RKF4993X          
1                                5.1k                   RESISTOR0402_RES                 0402_RES                 R10                                                                                                                                                     Resistor                                                         RES SMD 5.1K OHM 1% 1/10W 0402    P5.10KLCT-ND             Panasonic Electronic Components                      ERJ-2RKF5101X          
1                                5.6nH                  INDUCTOR0402                     0402_CAP                 L1                                                                                                                                                      A very specific inductor                                         FIXED IND 5.6NH 1.77A 40 MOHM     490-11766-1-ND           Murata                                               LQW15AN5N6B80D         
1                                66.5                   RESISTOR0402_RES                 0402_RES                 R1                                                                                                                                                      Resistor                                                         RES SMD 66.5 OHM 1% 1/16W 0402    YAG3210CT-ND             Yageo                                                RC0402FR-0766R5L       
3                                68                     RESISTOR0402_RES                 0402_RES                 R2,R3,R4                                                                                                                                                Resistor                                                         RES SMD 68 OHM 1% 1/16W 0402      311-68.0LRCT-ND          Yageo                                                RC0402FR-0768RL        
4                                750k                   RESISTOR1206_RES_HIGH_CLEARANCE  1206_RES_HIGH_CLEARANCE  R28,R29,R30,R31                                                                                                                                         Resistor                                                         RES SMD 750K OHM 1% 1/4W 1206     311-750KFRCT-ND          Yageo                                                RC1206FR-07750KL       
1                                825k                   RESISTOR0402_RES                 0402_RES                 R32                                                                                                                                                     Resistor                                                         RES SMD 825K OHM 1% 1/10W 0402    P825KLCT-ND              Panasonic Electronic Components                      ERJ-2RKF8253X          
2                                953k                   RESISTOR0402_RES                 0402_RES                 R33,R34                                                                                                                                                 Resistor                                                         RES SMD 953K OHM 1% 1/16W 0402    YAG3262CT-ND             Yageo                                                RC0402FR-07953KL       
2                                953k                   RESISTOR1206_RES_HIGH_CLEARANCE  1206_RES_HIGH_CLEARANCE  R35,R36                                                                                                                                                 Resistor                                                                                           P953KBCCT-ND             Panasonic Electronic Components                      ERA-8AEB9533V          
1                                AB1815-T3              AB1815-T3                        QFN-16-3MM               U1                                                                                                                                                      Ultra-low current RTC. 55nA quiescent @ 3V. 1.5-3.6V input.                                        535-11936-1-ND           Abracon                                              AB1815-T3              
1                                ABS07-32.768KHZ-7-T    ABS07-32.768KHZ-7-T              2-SMD                    X1                                                                                                                                                      32.768kHz Crystal                                                                                  535-9543-1-ND            ABRACON                                              ABS07-32.768KHZ-7-T    
1                                BGA725L6-ALT           BGA725L6-ALT                     LNA-TSLP-6-2-ALT         U2                                                                                                                                                                                                                       IC AMP MMIC RF LNA 20DB TSLP-6    BGA725L6E6327FTSA1CT-ND  Infineon                                             BGA725L6E6327FTSA1     
1                                BLUE                   LED0603                          LED-0603                 D9                                                                                                                                                      LED                                                              LED BLUE CLEAR SMD                160-1837-6-ND            Lite-On Inc.                                         LTST-C194TBKT          
1                                DM3AT-SF-PEJM5         DM3AT-SF-PEJM5                   DM3AT-SF-PEJM5           J1                                                                                                                                                      CONN MICRO SD R/A PUSH-PUSH SMD                                  CONN MICRO SD CARD PUSH-PUSH R/A  HR1964CT-ND              Hirose Electric Co Ltd                               DM3AT-SF-PEJM5         
1                                DS2401P+               DS2401P+                         21-0382                  U3                                                                                                                                                      A one wire serial number chip.                                                                     DS2401P+-ND              Maxim Integrated                                     DS2401P+               X
1                                ELECTRON               ELECTRON                         ELECTRON_SINGLE-ROW      ASSY1                                                                                                                                                                                                                    18 Position header                S7051-ND,S7051-ND        Sullins                                              PPPC181LFBN-RC         
1                                GPS-ANTENNA            GPS-ANTENNA                      ANT1818B00BT1516S        A1                                                                                                                                                                                                                       PATCH ANT GPS/GLO CP SMD          311-1531-ND              Yageo                                                ANT1818B00BT1516S      
1                                IRM-03-5V              IRM-03-5V                        IRM-03                   U5                                                                                                                                                      A 5V 3W board mount power supply                                                                   1866-3020-ND             Mean Well USA                                        IRM-03-5               
1                                LIS2DW12               LIS2DW12                         LGA-12                   U6                                                                                                                                                      ultra low power 3 axis accelerometer                                                               497-17718-6-ND           STMicroelectronics                511-LIS2DW12TR     LIS2DW12TR             
1                                MAX-M8                 MAX-M8                           MAX-M8                   U7                                                                                                                                                                                                                       IC RECEIVER GPS/GNSS 18LCC        672-1003-1-ND            u-blox                                               MAX-M8Q-0              
1                                MAX67XXMAX6749MAX67XX  MAX67XXMAX6749MAX67XX            SOT-23-8                 U8                                                                                                                                                      A simple watchdog timer with adjustable timeouts and reset time                                    MAX6749KA                Maxim Integrated                                     MAX6749KA+T            
2                                OPA369                 OPA369                           SC70-5                   U9,U10                                                                                                                                                                                                                                                     296-25252-1-ND           Texas Instruments                                    OPA369AIDCKR           
1                                S14K385                S14K385                          S14K385                  V1                                                                                                                                                      VARISTOR                                                         VARISTOR 620V 5KA DISC 14MM       495-5945-ND              EPCOS (TDK)                                          B72214S2381K101        
1                                SAFFB1G56KB0F0A        FILTERS                          QCS5I                    U4                                                                                                                                                                                                                       FILTER SAW 1.582GHZ 5SMD          587-3990-1-ND            Taiyo Yuden                                          F6QA1G582H2JM-J        
3                                SIP32510               SIP32510                         TSOT23-6                 U11,U12,U13                                                                                                                                             Load switch, slew rate controlled. By Vishay                                                       SIP32510DT-T1-GE3CT-ND   Vishay                                               SIP32510DT-T1-GE3      
32                               TEST_POINT_0.040IN     TEST_POINT_0.040IN               TESTPOINT_0.040IN        TP1,TP2,TP3,TP4,TP5,TP6,TP7,TP8,TP9,TP10,TP11,TP12,TP13,TP14,TP15,TP16,TP17,TP18,TP19,TP20,TP21,TP22,TP23,TP24,TP25,TP26,TP27,TP28,TP29,TP30,TP31,TP32  0.040in Test Point                                                                                 5001K-ND                                                                                             
2                                TEST_POINT_0.060IN     TEST_POINT_0.060IN               TESTPOINT_0.060IN        AC/L,AC/N                                                                                                                                               A 60mil Testpoint                                                                                                                                                                                       
1                                WRL-13678              WRL-13678                        WRL-13678                ASSY2                                                                                                                                                   ESP8266 WiFi Module                                                                                1568-1235-ND

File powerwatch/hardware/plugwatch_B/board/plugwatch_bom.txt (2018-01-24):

# Bill of Materials
# Converted from plugwatch_bom.xlsx
# Generated by bom_to_text.py
#
# # Bill of Materials                                                                                                                                                                                                                                                                                                                                                                                                                            
# # Converted from {}
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

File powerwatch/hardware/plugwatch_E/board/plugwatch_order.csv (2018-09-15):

Qty | Order_QTY | Value | Device | Package | Parts | Description | DESCRIPTION | DIGIKEY | MANUFACTURER | MOUSER | MPN | SPICEPREFIX
4 | 80 |  | DIODE_SCHOTTKYSOD323 | SOD323 | D1,D2,D3,D4 |  |  | CUS10S30H3FCT-ND | toshiba |  | CUS10S30,H3F
4 | 80 |  | DIODE_ZENERSOT323 | SOD323 | D5,D6,D7,D8 |  | DIODE ZENER 3.3V 200MW SOD323F | MM3Z3V3BCT-ND | ON Semiconductor |  | MM3Z3V3B
2 | 40 |  | M024UCON-15767 | JST-2-SMD-VERT | JP1,JP2 | Header 2 | CONN HEADER PH TOP 2POS 2MM SMD | 455-1734-1-ND | JST Sales America Inc. |  | B2B-PH-SM4-TB(LF)(SN)
1 | 10 |  | MS518SE | MS518SE-FL35E | B1 | A small, low leakage rechargeable battery for RTC backup |  | 728-1054-ND | Seiko |  | MS518SE-FL35E
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

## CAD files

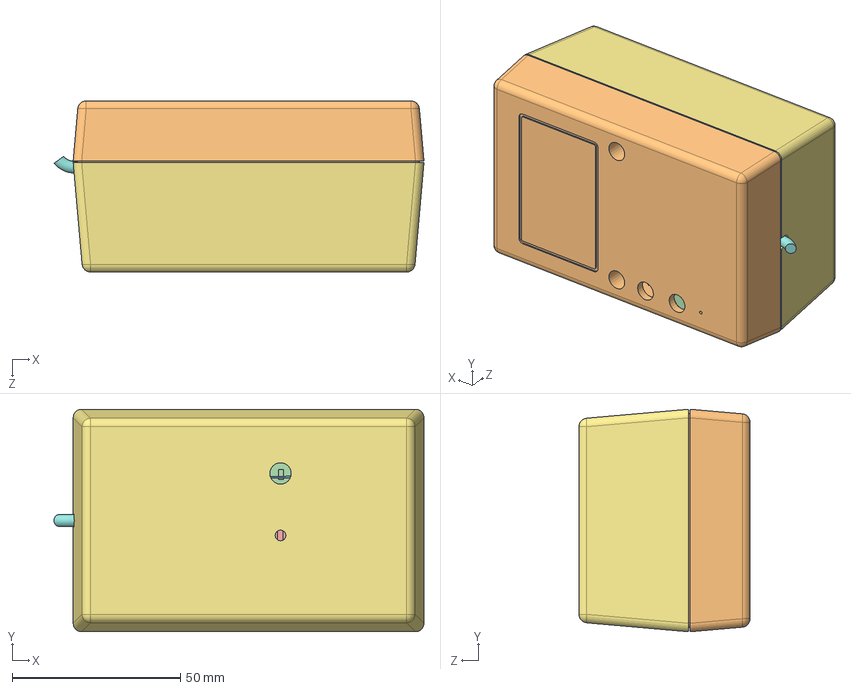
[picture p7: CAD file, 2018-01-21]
powerwatch/hardware/plugwatch_B/case/case_assembly.SLDASM
109.8 x 66.0 x 50.8 mm
6013-6005_Pan head tapping screw_4(6005-SCREW) x 2
s-series-02-12(12)
antenna
sensor_board
particle base
battery
S-series-2X-Top(2-2)-1
usb_cable

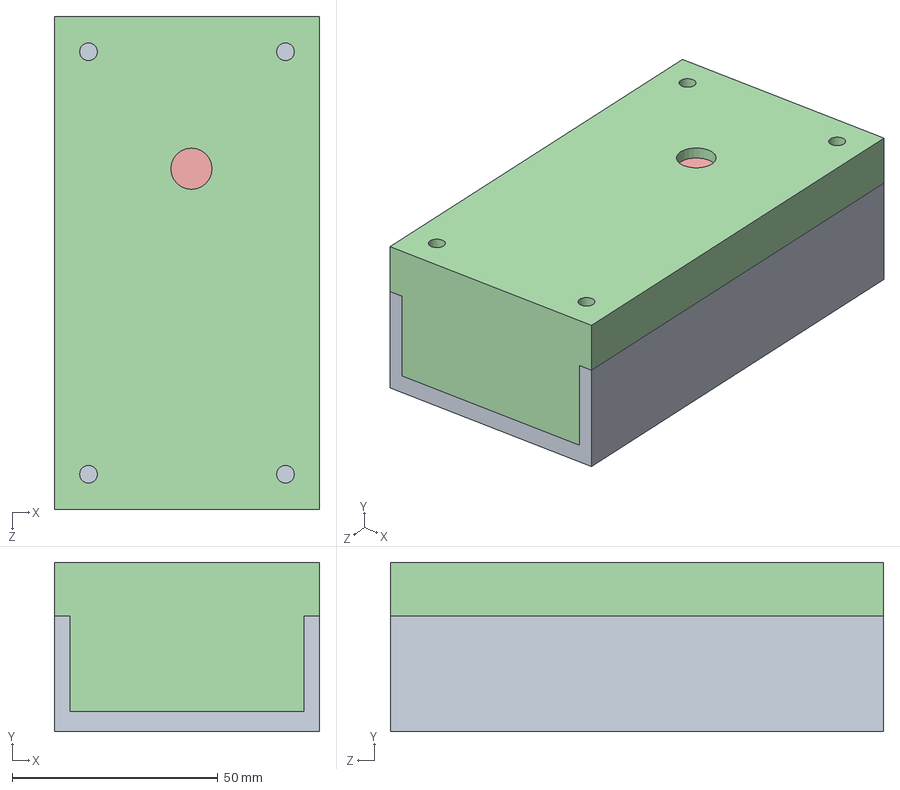
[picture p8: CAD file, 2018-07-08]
powerwatch/hardware/plugwatch_D/case/case_assembly.SLDASM
64.5 x 41.1 x 119.9 mm
top_case
antenna
battery
bottom_case
pcb
power_supply
particle_base

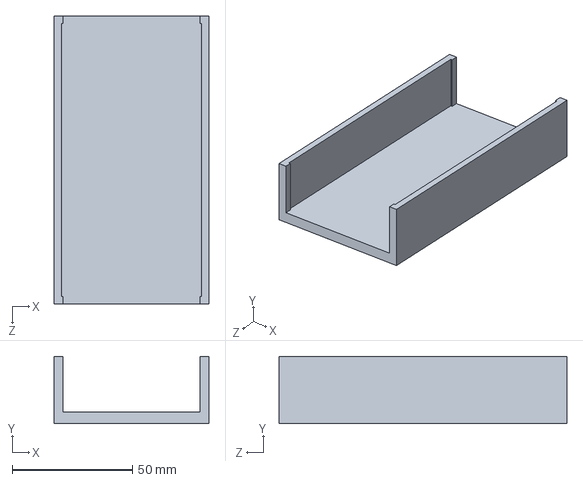
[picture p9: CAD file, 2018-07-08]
powerwatch/hardware/plugwatch_E/case/top_case.SLDPRT
64.5 x 28.1 x 119.9 mm

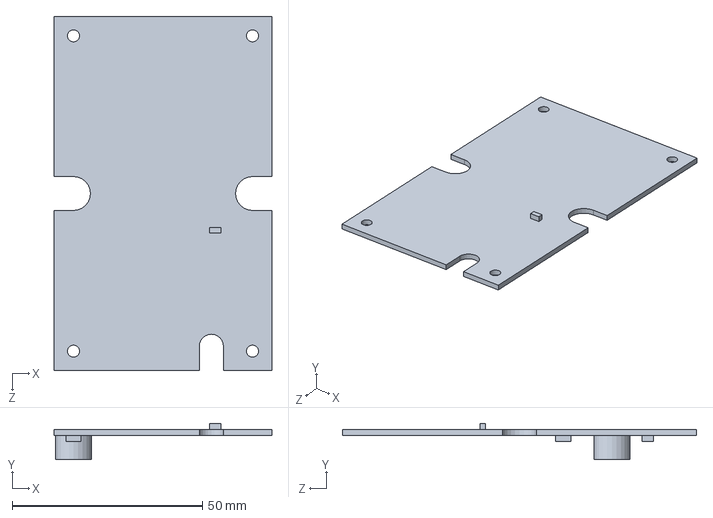
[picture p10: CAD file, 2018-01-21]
powerwatch/hardware/plugwatch_B/case/sensor_board.SLDPRT
57.1 x 9.52 x 93.0 mm

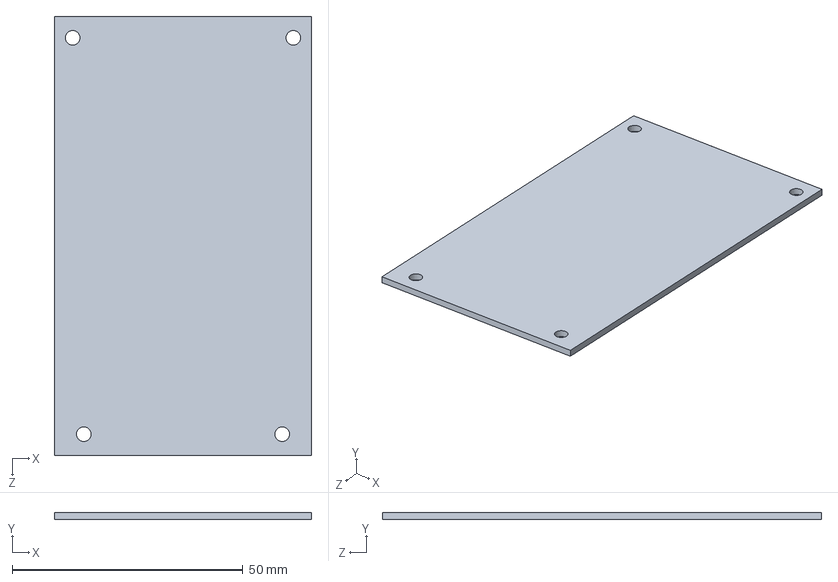
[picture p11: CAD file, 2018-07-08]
powerwatch/hardware/plugwatch_D/case/pcb.SLDPRT
55.7 x 1.59 x 95.2 mm

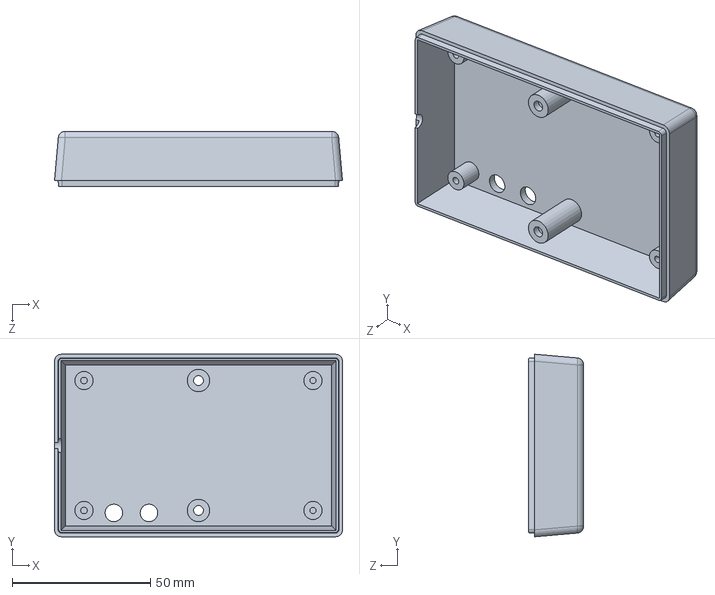
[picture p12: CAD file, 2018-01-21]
powerwatch/hardware/plugwatch_B/case/s-series-02-12(12).sldprt
104.1 x 66.0 x 20.1 mm

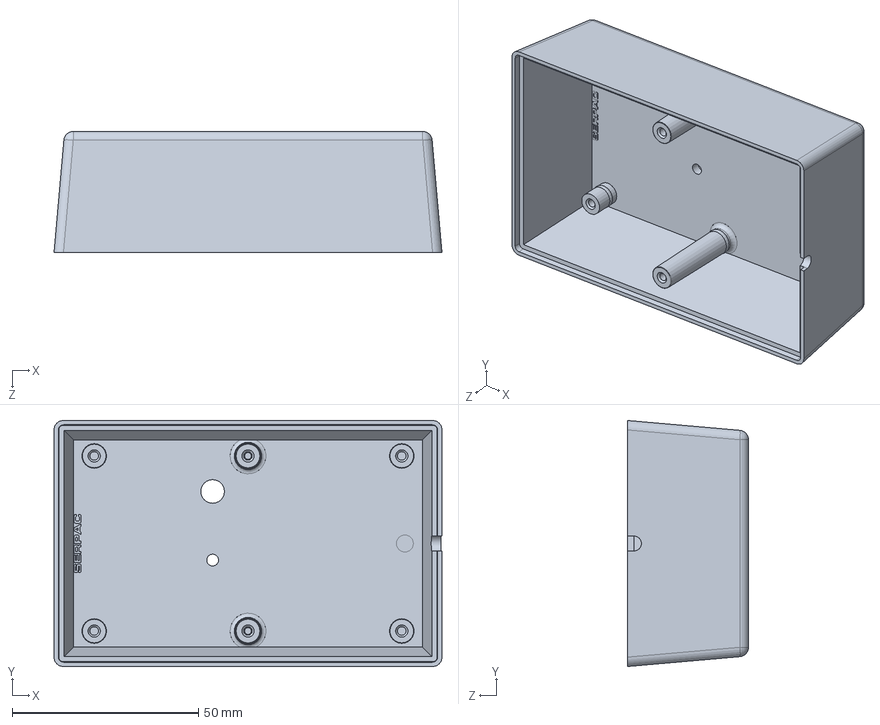
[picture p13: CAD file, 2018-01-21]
powerwatch/hardware/plugwatch_B/case/S-series-2X-Top(2-2)-1.SLDPRT
104.1 x 66.0 x 32.5 mm

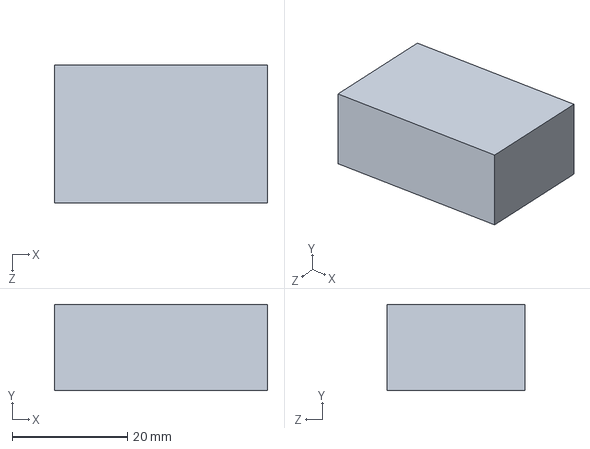
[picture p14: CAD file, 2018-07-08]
powerwatch/hardware/plugwatch_D/case/power_supply.SLDPRT
37.0 x 15.0 x 24.0 mm

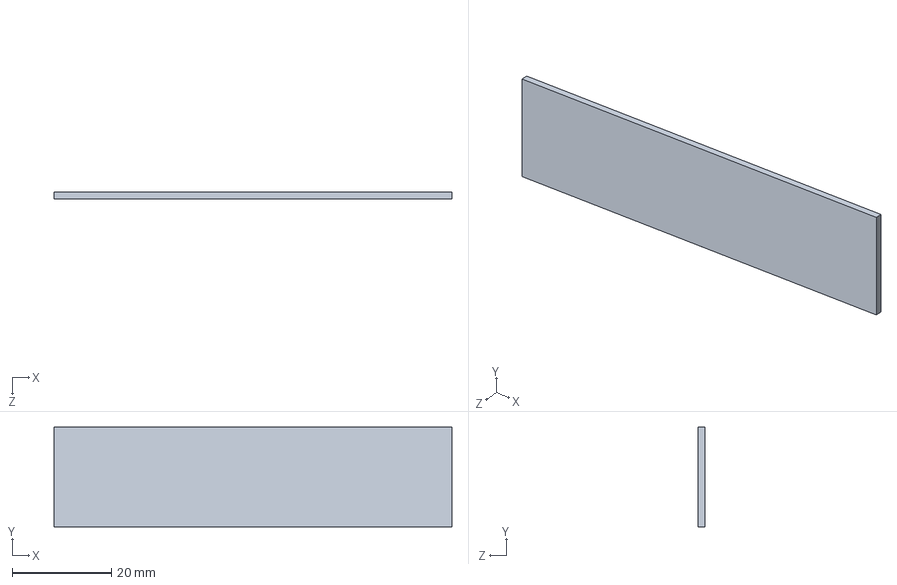
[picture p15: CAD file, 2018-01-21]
powerwatch/hardware/plugwatch_B/case/antenna.SLDPRT
80.1 x 20.1 x 1.35 mm

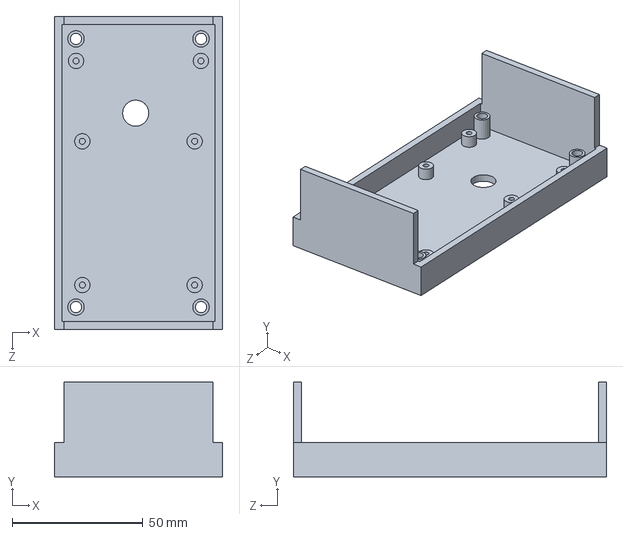
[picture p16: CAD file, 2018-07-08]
powerwatch/hardware/plugwatch_D/case/bottom_case.SLDPRT
64.5 x 36.3 x 119.9 mm

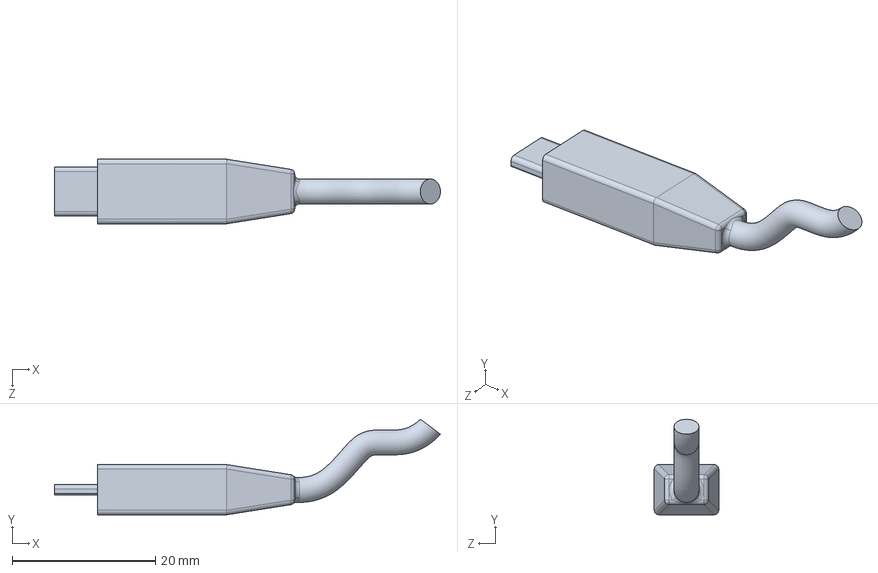
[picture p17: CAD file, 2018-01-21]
powerwatch/hardware/plugwatch_B/case/usb_cable.SLDPRT
53.8 x 13.3 x 9.00 mm

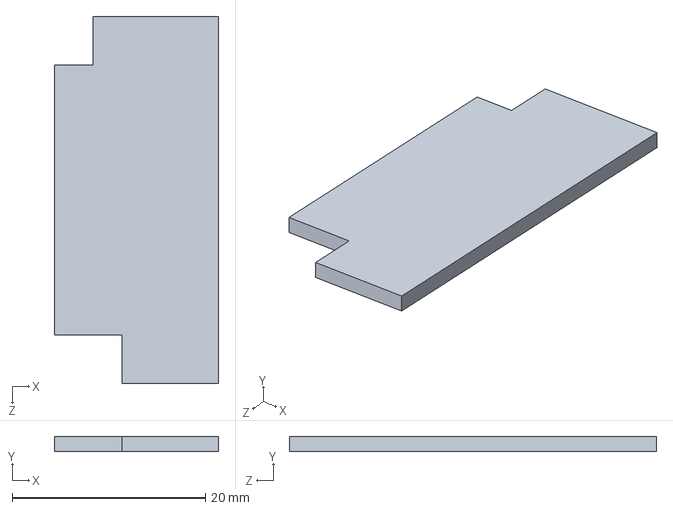
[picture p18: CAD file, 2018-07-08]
powerwatch/hardware/plugwatch_D/case/antenna.SLDPRT
17.0 x 1.59 x 38.0 mm

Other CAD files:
powerwatch/hardware/plugwatch_B/case/S-series-2X-Top(2-2)-1.SLDDRW
powerwatch/hardware/plugwatch_B/case/battery.SLDPRT
powerwatch/hardware/plugwatch_B/case/particle_base.SLDPRT
powerwatch/hardware/plugwatch_B/case/s-series-02-12(12).SLDDRW

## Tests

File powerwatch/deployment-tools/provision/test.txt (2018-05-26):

48001a000951343334363138,BDB59F1A0000,03:11PM on May 25, 2018

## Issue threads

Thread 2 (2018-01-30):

Rev A Issues

brghena, 2018-01-30:
- [ ] U6 doesn't have a pin 1 indicator

brghena, 2018-01-30:
- [ ] C27 is either the wrong part or the wrong pads
- [ ] Some silkscreen reference designators are the wrong direction by the nRF

brghena, 2018-01-30:
- [ ] C23, C24, and C28 need orientation markers on the PCB

brghena, 2018-01-30:
- [ ] Need to purchase headers for the Electron too (should be added as an attribute for the part)

brghena, 2018-01-30:
- [ ] Need power and ground probe points on the board
- [ ] It would be nice to label the individual sensing types on the silkscreen (i.e. the Audio, Light Sensor, BLE, etc.)

nealjack, 2018-01-31:
- [ ] SD_MOSI, SD_SCLK testpoints need to be flipped onto back of board. (their silk circles are on the wrong side)

nealjack, 2018-01-31:
- [ ] Testpoints/labels for 3v3 and GND

brghena, 2018-01-31:
- [ ] Think about moving most of the passives to a single side of the board

adkinsjd, 2018-02-15:
- [ ] Connect SD_ENABLE signal to the electron

nklugman, 2018-02-15:
breakout remaining gpios

nklugman, 2018-02-15:
if possible route prefilter audio to a free adc pin

nklugman, 2018-02-15:
if possible make gps fix led visible after box is closed

nklugman, 2018-02-15:
add prefilter audio test point

nklugman, 2018-02-15:
add at least some electron pin labels for orientation

nklugman, 2018-02-15:
make sure that temp is included in the mpu driver

brghena, 2018-02-16:
- [ ] 60 Hz antenna with non-inverting amplifier

brghena, 2018-02-16:
- [ ] Power cutoff on sensors

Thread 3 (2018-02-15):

Software Issues

brghena, 2018-02-15:
- [ ] Use main LED to indicate GPS status
- [ ] Make sure that temperature is included in the MPU driver

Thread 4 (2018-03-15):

Rev B Issues

nklugman, 2018-03-15:

nklugman, 2018-03-15:
flip jtag to top and move so that bottom left screw does not obstruct

nklugman, 2018-03-15:
sign off on audio front end

nklugman, 2018-03-15:
inductor and inductor lead placement... right now the leads are hard to keep from shorting and the inductor is free floating.

nklugman, 2018-03-15:
add serial number chip

nklugman, 2018-03-15:
purchase paper clips that fit reset hole to include with pw unit

nklugman, 2018-03-22:
remove the rc filter post amp pre filter

nklugman, 2018-03-29:
add apn switch on bottom of board

nklugman, 2018-03-29:
**done** remove RC filter from audio

ppannuto, 2018-04-04:
Add headers that break out particle signals for debugging

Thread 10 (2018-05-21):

Rev 3 Changes

adkinsjd, 2018-05-21:
- [ ] Battery backed RTC on the shield
 - [ ] Route VIN directly to an external interrupt pin (with some kind of voltage step/protection)

nklugman, 2018-05-28:
- [ ] potentially TPL5000 or some other external wakeup timer to WKP pin
- [ ] make it more difficult to plug in particles offset on the headers
- [ ] add temp sensor
- [ ] low voltage interrupt? something to tell the particle to stay asleep that is more of a hardware trigger?
- [ ] new sd card sockets
- [ ] ye-sheng 60hz detector (likely for rev 5 or something)
- [ ] lower cost imu?

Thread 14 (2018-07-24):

Plugwatch_Rev_4 Changes

adkinsjd, 2018-07-24:
- [ ] Fix the direction of the AC/DC converter block
 - [ ] The JST connectors are hard to use - try a different part

adkinsjd, 2018-09-15:
- [ ] Fix the battery holder part
 - [ ] Fix the interaction between voltage sensing and perturb/observe timing

adkinsjd, 2018-09-15:
- [ ] change solder wires to screw terminals

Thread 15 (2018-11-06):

Powerwatch Rev E Changes

adkinsjd, 2018-11-06:
- [ ] Make screw terminal parts hole slightly larger
 - [ ] Make it so that when 5V is present the voltage monitor doesn't put particle into reset (simple resistor divider should do - will test)

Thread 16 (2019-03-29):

PowerWatch Rev F changes

adkinsjd, 2019-03-29:
- [ ] Fix R1 to be 66.5K
 - [ ] Fix voltage monitor/watchdog resistor divider

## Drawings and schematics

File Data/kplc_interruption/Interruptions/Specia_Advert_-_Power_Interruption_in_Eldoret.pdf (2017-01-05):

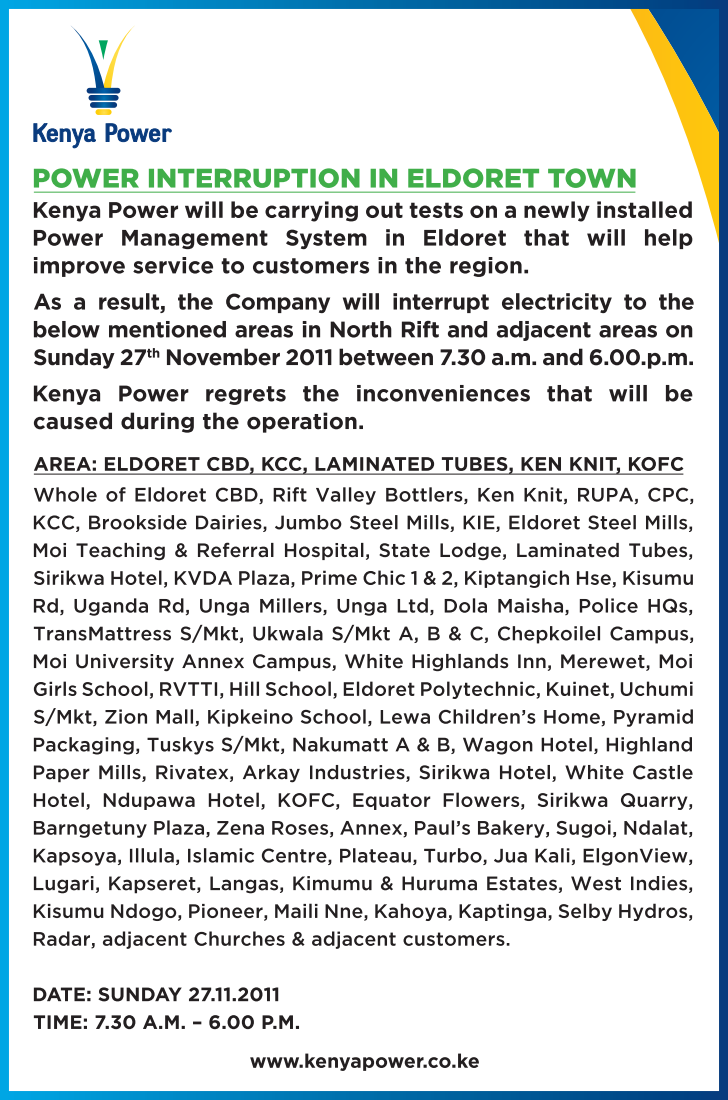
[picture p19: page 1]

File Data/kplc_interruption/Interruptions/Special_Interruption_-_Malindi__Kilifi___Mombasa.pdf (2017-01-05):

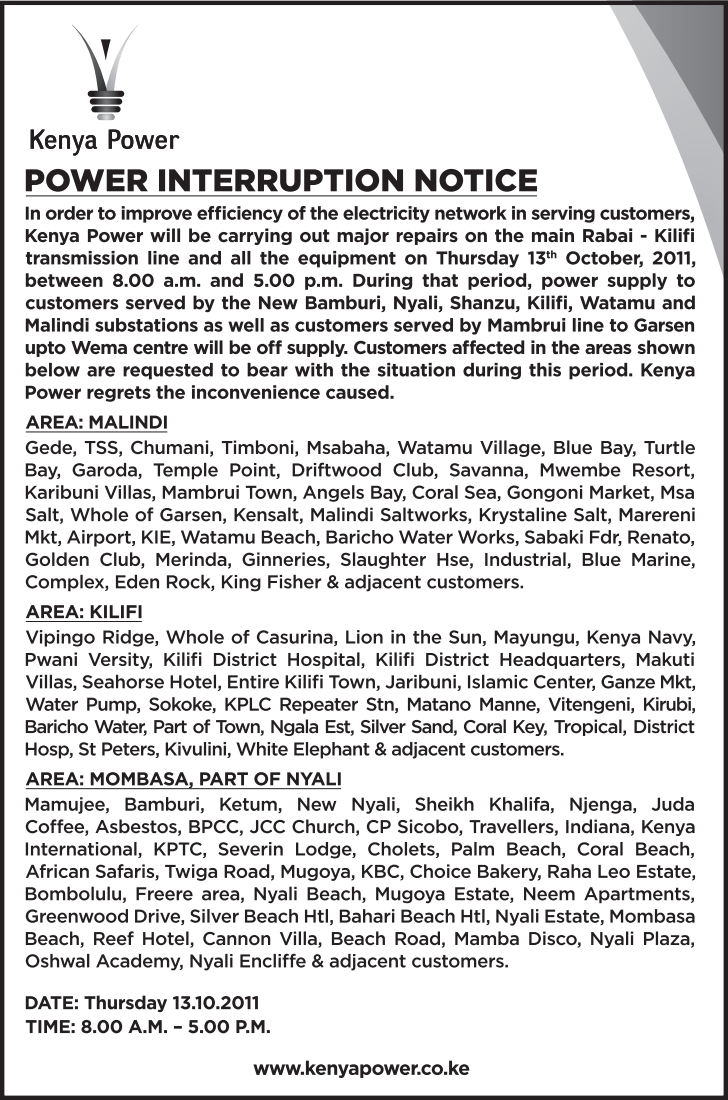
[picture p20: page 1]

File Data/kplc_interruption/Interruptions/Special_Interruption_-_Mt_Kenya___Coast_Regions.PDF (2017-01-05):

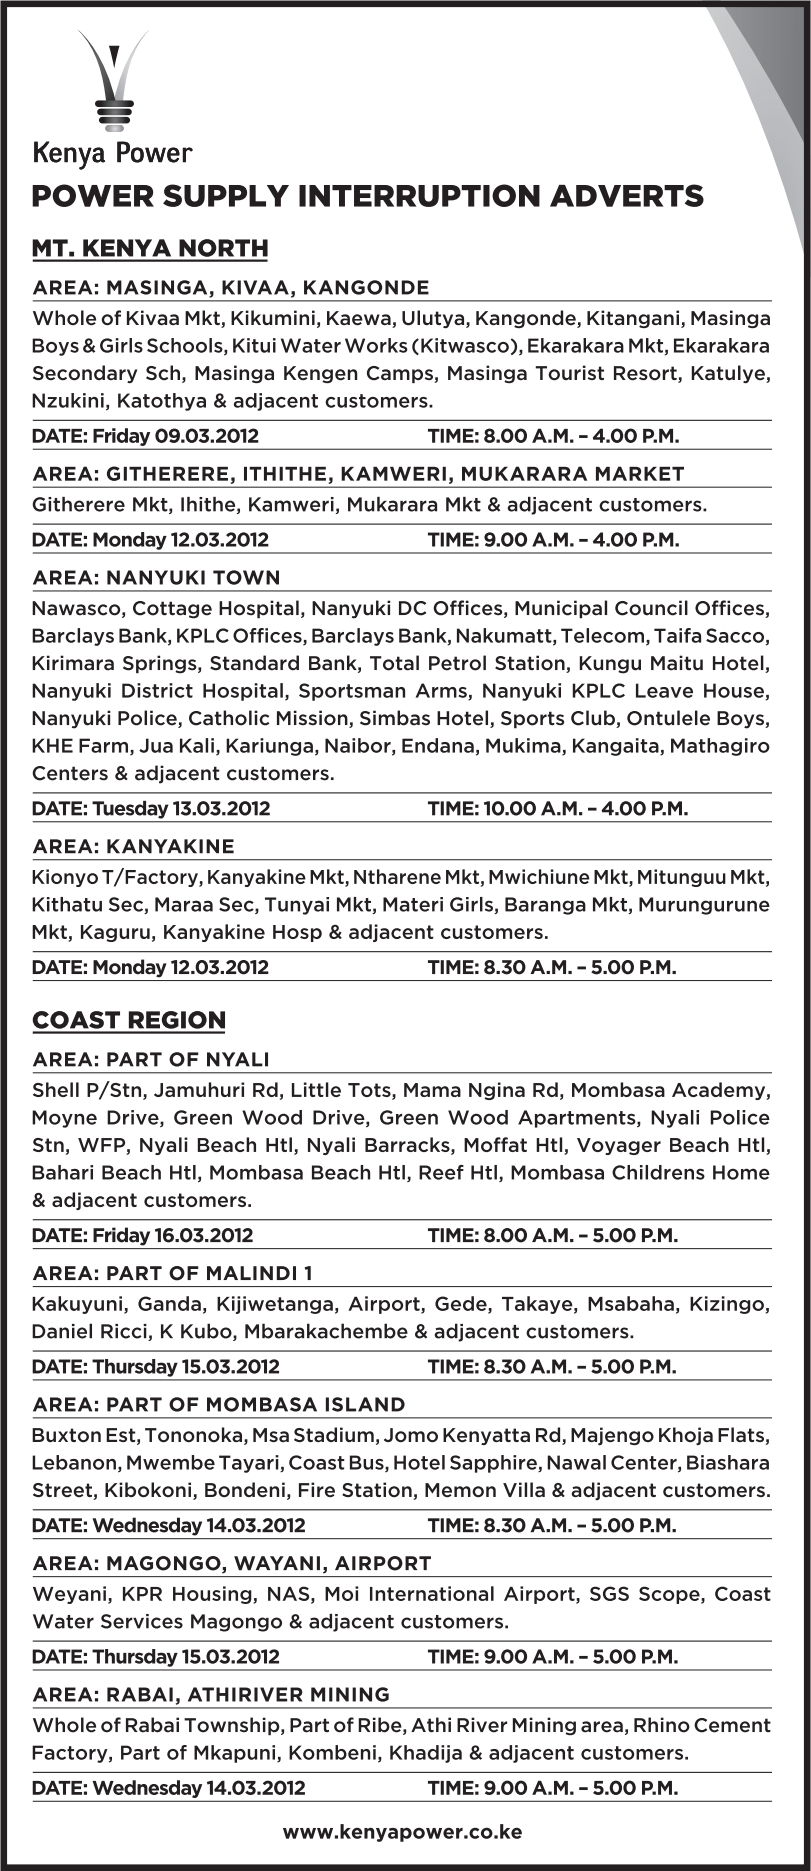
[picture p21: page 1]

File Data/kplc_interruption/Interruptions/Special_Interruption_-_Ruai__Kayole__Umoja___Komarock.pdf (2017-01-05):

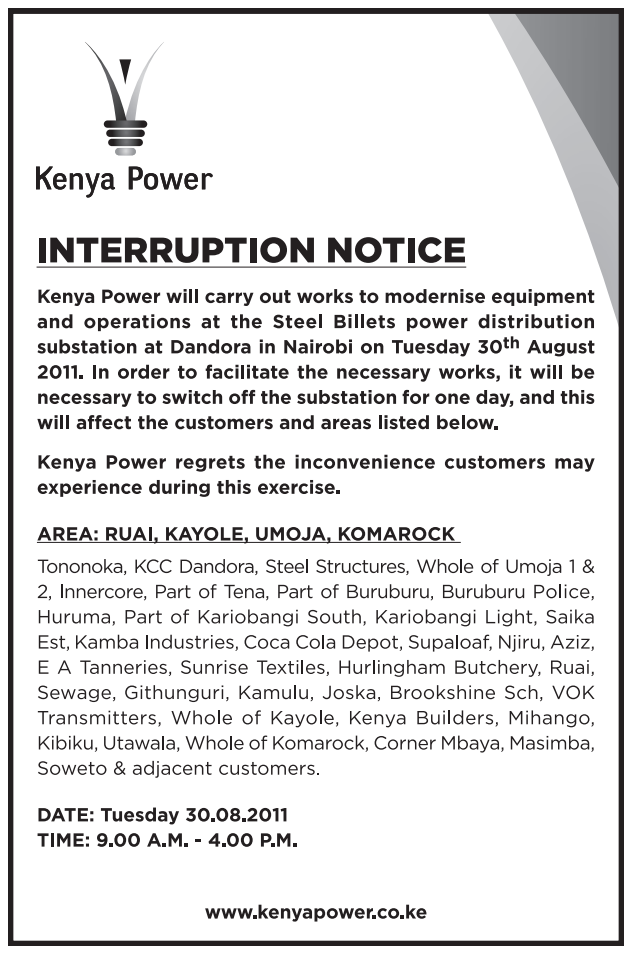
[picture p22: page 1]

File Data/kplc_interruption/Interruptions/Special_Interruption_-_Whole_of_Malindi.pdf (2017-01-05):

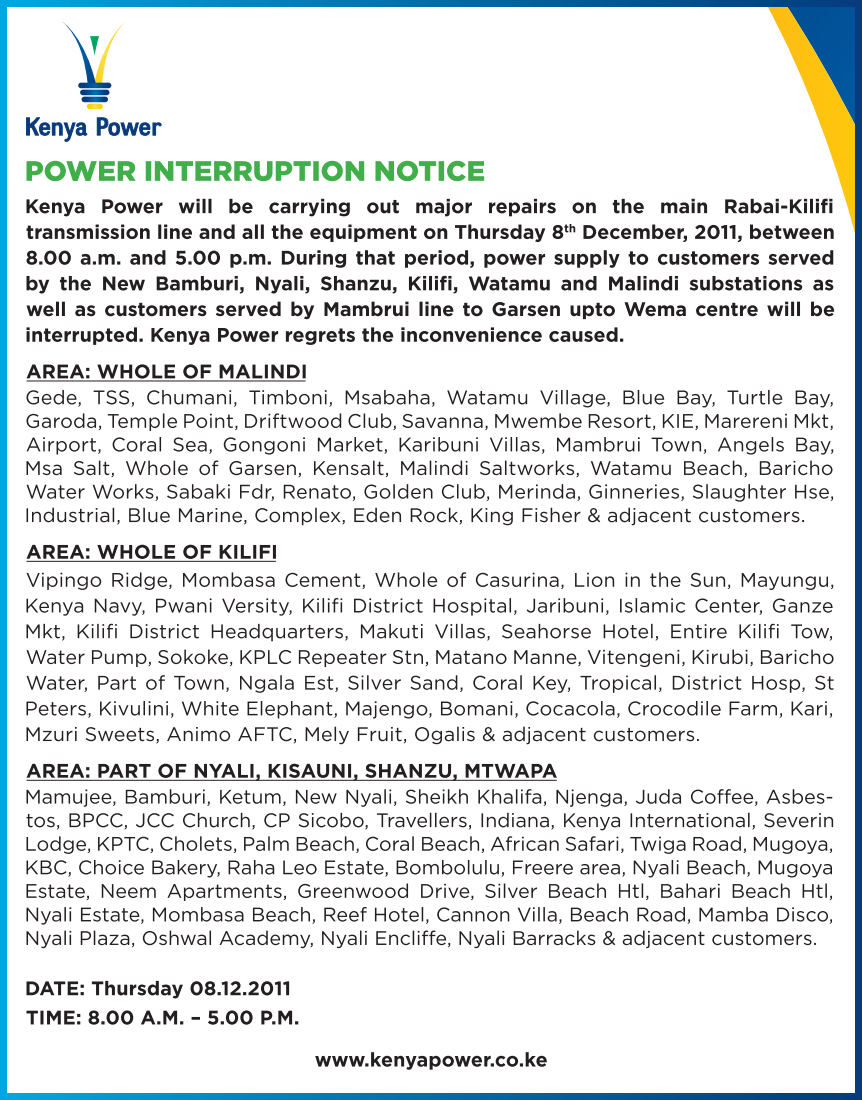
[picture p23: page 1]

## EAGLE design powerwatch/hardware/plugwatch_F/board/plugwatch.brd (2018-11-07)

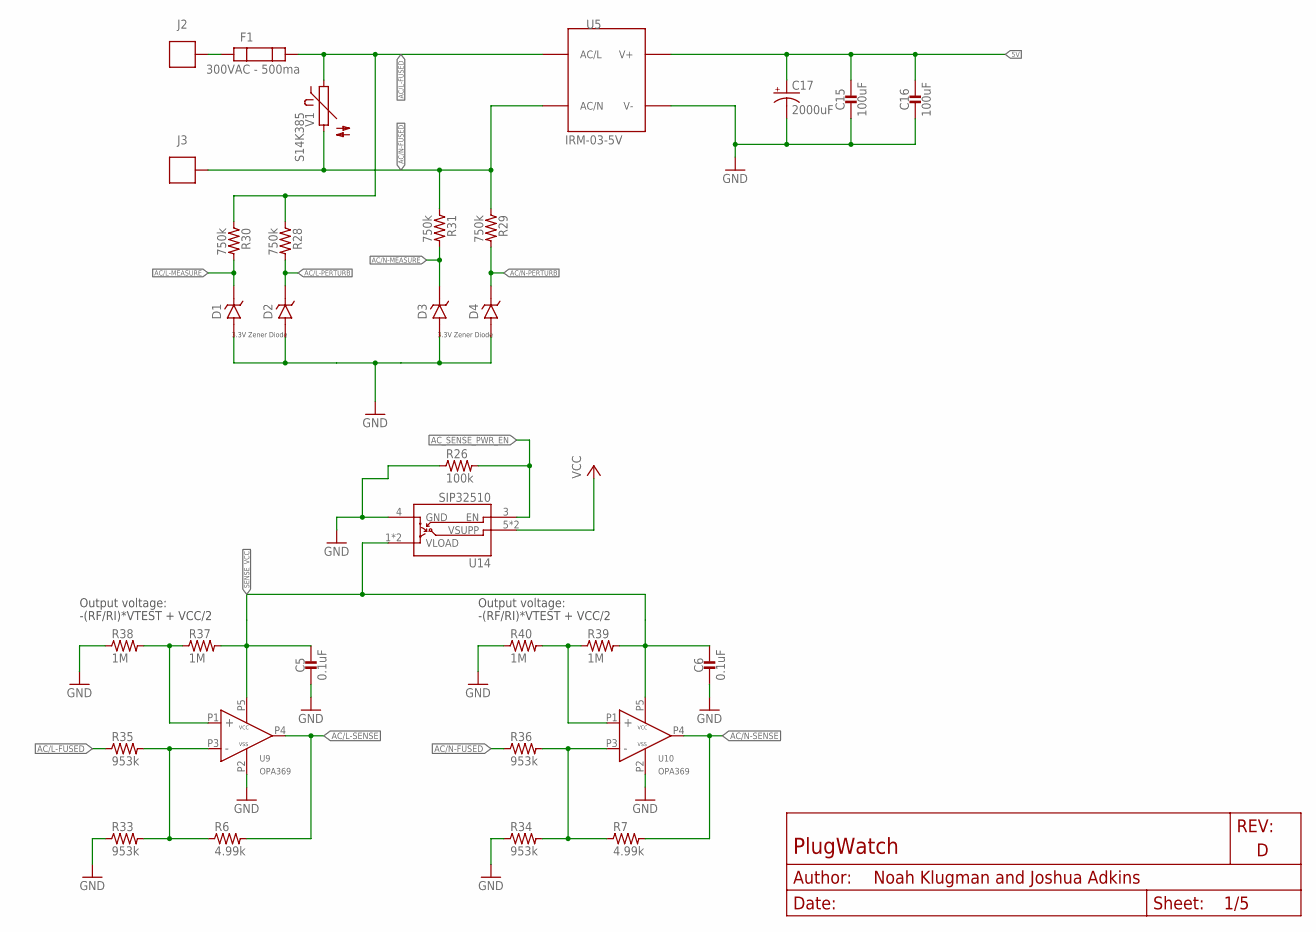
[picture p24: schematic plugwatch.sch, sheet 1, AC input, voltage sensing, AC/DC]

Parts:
C5, C6: 0.1uF; 0402_CAP; MPN CC0402KRX5R6BB104; DIGIKEY 311-1336-1-ND
C15, C16: 100uF; 1210_CAP; MPN GRM32EC70J107ME15L; DIGIKEY 490-10530-1-ND
C17: 2000uF; E5-13; MPN EEU-FS0J202B; DIGIKEY P122284TB-ND
D1, D2, D3, D4: DIODE_ZENERSOT323; SOD323; MPN MM3Z3V3B; DIGIKEY MM3Z3V3BCT-ND
F1: 300VAC - 500ma; MIRCRO_FUSE_5MM
J2, J3: SCREW_TERMNIAL_1; 360272-TERMINAL-BLOCK
R6, R7: 4.99k; 0402_RES; MPN ERJ-2RKF4991X; DIGIKEY P4.99KLCT-ND
R26: 100k; 0402_RES; MPN CRCW0402100KFKED; DIGIKEY 541-100KLCT-ND
R28, R29, R30, R31: 750k; 1206_RES_HIGH_CLEARANCE; MPN RC1206FR-07750KL; DIGIKEY 311-750KFRCT-ND
R33, R34: 953k; 0402_RES; MPN RC0402FR-07953KL; DIGIKEY YAG3262CT-ND
R35, R36: 953k; 1206_RES_HIGH_CLEARANCE; MPN ERA-8AEB9533V; DIGIKEY P953KBCCT-ND
R37, R38, R39, R40: 1M; 0402_RES; MPN RMCF0402FT1M00; DIGIKEY RMCF0402FT1M00CT-ND
U5: IRM-03-5V; IRM-03
U9, U10: OPA369; SC70-5; DIGIKEY 296-25252-1-ND
U14: SIP32510; TSOT23-6
V1: S14K385; MPN B72214S2381K101; DIGIKEY 495-5945-ND

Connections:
5V: C15.1, C16.1, C17.+, U5.V+; also elsewhere on the board
AC/L-FUSED: F1.P$2, R28.1, R30.1, R35.1, U5.AC/L, V1.1
AC/L-MEASURE: D1.P$1 (CATHODE), R30.2; also elsewhere on the board
AC/L-PERTURB: D2.P$1 (CATHODE), R28.2; also elsewhere on the board
AC/L-SENSE: R6.2, U9.P4 (OUT); also elsewhere on the board
AC/N-FUSED: J3.P$1, J3.P$2, R29.1, R31.1, R36.1, U5.AC/N, V1.2
AC/N-MEASURE: D3.P$1 (CATHODE), R31.2; also elsewhere on the board
AC/N-PERTURB: D4.P$1 (CATHODE), R29.2; also elsewhere on the board
AC/N-SENSE: R7.2, U10.P4 (OUT); also elsewhere on the board
AC_SENSE_PWR_EN: R26.2, U14.3 (EN); also elsewhere on the board
GND: C5.2, C6.2, C15.2, C16.2, C17.-, D1.P$2 (ANODE), D2.P$2 (ANODE), D3.P$2 (ANODE), D4.P$2 (ANODE), R26.1, R33.1, R34.1, R38.1, R40.1, U5.V-, U9.P2 (VSS), U10.P2 (VSS), U14.4 (GND); also elsewhere on the board
unnamed: F1.P$1, J2.P$1, J2.P$2
unnamed: R37.1, R38.2, U9.P1 (IN+)
unnamed: R6.1, R33.2, R35.2, U9.P3 (IN-)
unnamed: R39.1, R40.2, U10.P1 (IN+)
unnamed: R7.1, R34.2, R36.2, U10.P3 (IN-)
SENSE_VCC: C5.1, C6.1, R37.2, R39.2, U9.P5 (VCC), U10.P5 (VCC), U14.1 (VLOAD), U14.2 (VLOAD)
VCC: U14.5 (VSUPP), U14.6 (VSUPP); also elsewhere on the board

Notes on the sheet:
Output voltage:
-(RF/RI)*VTEST + VCC/2
3.3V Zener Diode

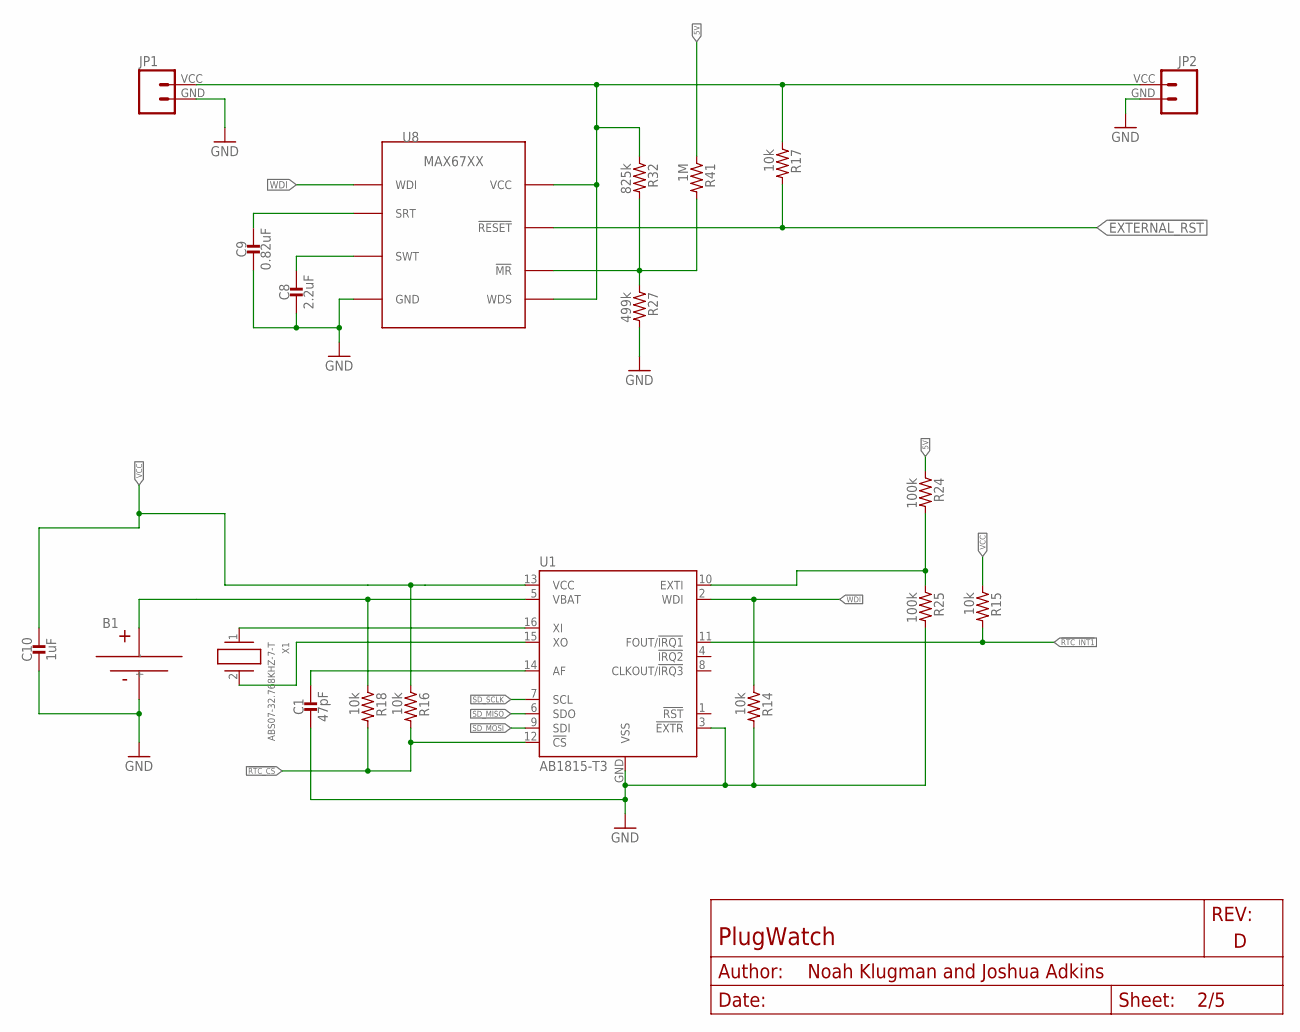
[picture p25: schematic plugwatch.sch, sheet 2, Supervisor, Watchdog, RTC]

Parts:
B1: MS518SE; MS518SE-FL35E
C1: 47pF; 0402_CAP; MPN GRM1555C2A470JA01D; DIGIKEY 490-7307-1-ND
C8: 2.2uF; 0402_CAP; MPN GRM155C70J225KE11D; DIGIKEY 490-12696-1-ND
C9: 0.82uF; 0402_CAP; MPN GRM155C80J824KE15D; DIGIKEY 490-10440-1-ND
C10: 1uF; 0402_CAP; MPN GCM155C71A105KE38D; DIGIKEY 490-13409-1-ND
JP1, JP2: M024UCON-15767; JST-2-SMD-VERT; MPN B2B-PH-SM4-TB(LF)(SN); DIGIKEY 455-1734-1-ND
R14, R15, R16, R17, R18: 10k; 0402_RES; MPN RMCF0402FT10K0; DIGIKEY RMCF0402FT10K0CT-ND
R24, R25: 100k; 0402_RES; MPN CRCW0402100KFKED; DIGIKEY 541-100KLCT-ND
R27: 499k; 0402_RES; MPN ERJ-2RKF4993X; DIGIKEY P499KLCT-ND
R32: 825k; 0402_RES; MPN ERJ-2RKF8253X; DIGIKEY P825KLCT-ND
R41: 1M; 0402_RES; MPN RMCF0402FT1M00; DIGIKEY RMCF0402FT1M00CT-ND
U1: AB1815-T3; QFN-16-3MM
U8: MAX67XXMAX6749MAX67XX; SOT-23-8
X1: ABS07-32.768KHZ-7-T; 2-SMD

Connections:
5V: R24.1, R41.1; also elsewhere on the board
!EXTERNAL_RST: R17.2, U8.7 (!RESET); also elsewhere on the board
!RTC_CS: R16.2, R18.2, U1.12 (!CS); also elsewhere on the board
!RTC_INT1: R15.2, U1.11 (FOUT/!IRQ1); also elsewhere on the board
GND: B1.-, C1.2, C8.2, C9.2, C10.2, JP1.GND (1), JP2.GND (1), R14.2, R25.2, R27.2, U1.3 (!EXTR), U1.GND (VSS), U8.4 (GND); also elsewhere on the board
unnamed: B1.+, R18.1, U1.5 (VBAT)
unnamed: C1.1, U1.14 (AF)
unnamed: U1.15 (XO), X1.2
unnamed: U1.16 (XI), X1.1
unnamed: JP1.VCC (2), JP2.VCC (2), R17.1, R32.1, U8.5 (WDS), U8.8 (VCC)
unnamed: R24.2, R25.1, U1.10 (EXTI)
unnamed: R27.1, R32.2, R41.2, U8.1 (!MR)
unnamed: C9.1, U8.3 (SRT)
unnamed: C8.1, U8.2 (SWT)
SD_MISO: U1.6 (SDO); also elsewhere on the board
SD_MOSI: U1.9 (SDI); also elsewhere on the board
SD_SCLK: U1.7 (SCL); also elsewhere on the board
VCC: C10.1, R15.1, R16.1, U1.13 (VCC); also elsewhere on the board
WDI: R14.1, U1.2 (WDI), U8.6 (WDI); also elsewhere on the board

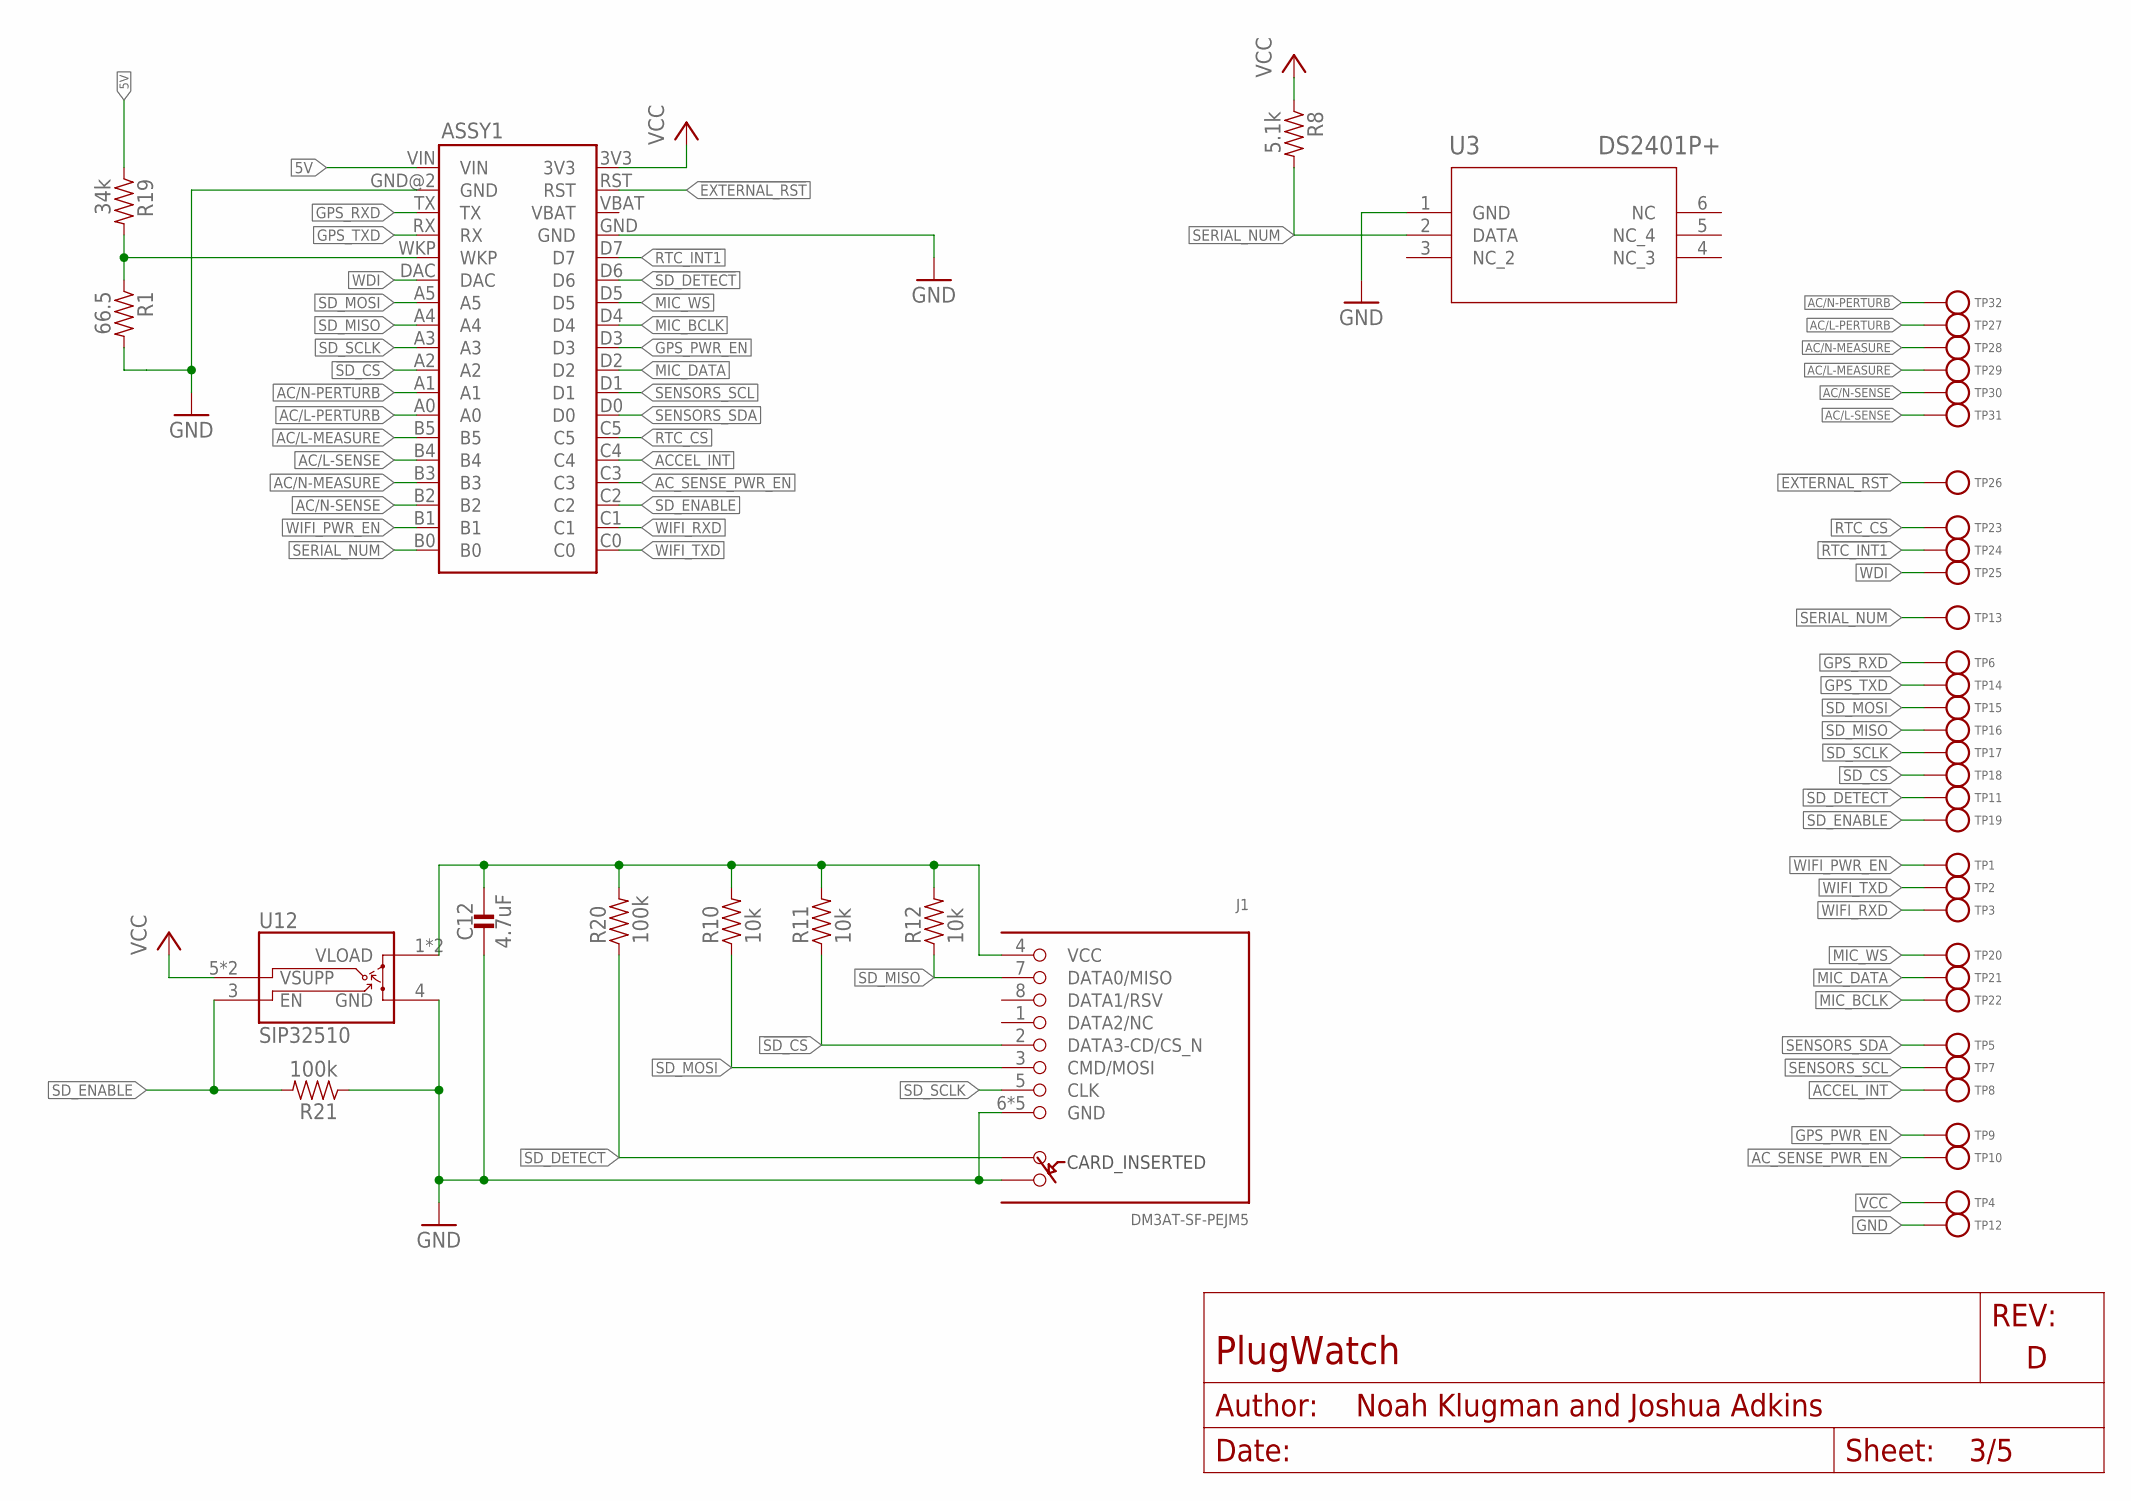
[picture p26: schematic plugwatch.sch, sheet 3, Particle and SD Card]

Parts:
ASSY1: ELECTRON; ELECTRON_SINGLE-ROW; MPN PPPC181LFBN-RC; DIGIKEY S7051-ND,S7051-ND
C12: 4.7uF; 0402_CAP; MPN C1005X5R0J475K050BC; DIGIKEY 445-5947-1-ND
J1: DM3AT-SF-PEJM5
R1: 66.5; 0402_RES; MPN RC0402FR-0766R5L; DIGIKEY YAG3210CT-ND
R8: 5.1k; 0402_RES; MPN ERJ-2RKF5101X; DIGIKEY P5.10KLCT-ND
R10, R11, R12: 10k; 0402_RES; MPN RMCF0402FT10K0; DIGIKEY RMCF0402FT10K0CT-ND
R19: 34k; 0402_RES; MPN ERJ-2RKF3402X; DIGIKEY P34.0KLCT-ND
R20, R21: 100k; 0402_RES; MPN CRCW0402100KFKED; DIGIKEY 541-100KLCT-ND
TP1, TP2, TP3, TP4, TP5, TP6, TP7, TP8, TP9, TP10, TP11, TP12, TP13, TP14, TP15, TP16, TP17, TP18, TP19, TP20, TP21, TP22, TP23, TP24, TP25, TP26, TP27, TP28, TP29, TP30, TP31, TP32: TEST_POINT_0.040IN; TESTPOINT_0.040IN
U3: DS2401P+; 21-0382
U12: SIP32510; TSOT23-6

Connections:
5V: ASSY1.VIN, R19.1; also elsewhere on the board
!EXTERNAL_RST: ASSY1.RST, TP26.TESTPOINT; also elsewhere on the board
!RTC_CS: ASSY1.C5, TP23.TESTPOINT; also elsewhere on the board
!RTC_INT1: ASSY1.D7, TP24.TESTPOINT; also elsewhere on the board
!SD_CS: ASSY1.A2, J1.2 (DATA3-CD/CS_N), R11.1, TP18.TESTPOINT
!SD_DETECT: ASSY1.D6, J1.A, R20.1, TP11.TESTPOINT
AC/L-MEASURE: ASSY1.B5, TP29.TESTPOINT; also elsewhere on the board
AC/L-PERTURB: ASSY1.A0, TP27.TESTPOINT; also elsewhere on the board
AC/L-SENSE: ASSY1.B4, TP31.TESTPOINT; also elsewhere on the board
AC/N-MEASURE: ASSY1.B3, TP28.TESTPOINT; also elsewhere on the board
AC/N-PERTURB: ASSY1.A1, TP32.TESTPOINT; also elsewhere on the board
AC/N-SENSE: ASSY1.B2, TP30.TESTPOINT; also elsewhere on the board
ACCEL_INT: ASSY1.C4, TP8.TESTPOINT; also elsewhere on the board
AC_SENSE_PWR_EN: ASSY1.C3, TP10.TESTPOINT; also elsewhere on the board
GND: ASSY1.GND, ASSY1.GND@2 (GND), C12.2, J1.6 (GND), J1.B, J1.MOUNT0 (GND), J1.MOUNT1 (GND), J1.MOUNT2 (GND), J1.MOUNT3 (GND), R1.2, R21.1, TP12.TESTPOINT, U3.1 (GND), U12.4 (GND); also elsewhere on the board
GPS_PWR_EN: ASSY1.D3, TP9.TESTPOINT; also elsewhere on the board
GPS_RXD: ASSY1.TX, TP6.TESTPOINT; also elsewhere on the board
GPS_TXD: ASSY1.RX, TP14.TESTPOINT; also elsewhere on the board
MIC_BCLK: ASSY1.D4, TP22.TESTPOINT; also elsewhere on the board
MIC_DATA: ASSY1.D2, TP21.TESTPOINT; also elsewhere on the board
MIC_WS: ASSY1.D5, TP20.TESTPOINT; also elsewhere on the board
unnamed: ASSY1.WKP, R1.1, R19.2
unnamed: C12.1, J1.4 (VCC), R10.2, R11.2, R12.2, R20.2, U12.1 (VLOAD), U12.2 (VLOAD)
SD_ENABLE: ASSY1.C2, R21.2, TP19.TESTPOINT, U12.3 (EN)
SD_MISO: ASSY1.A4, J1.7 (DATA0/MISO), R12.1, TP16.TESTPOINT; also elsewhere on the board
SD_MOSI: ASSY1.A5, J1.3 (CMD/MOSI), R10.1, TP15.TESTPOINT; also elsewhere on the board
SD_SCLK: ASSY1.A3, J1.5 (CLK), TP17.TESTPOINT; also elsewhere on the board
SENSORS_SCL: ASSY1.D1, TP7.TESTPOINT; also elsewhere on the board
SENSORS_SDA: ASSY1.D0, TP5.TESTPOINT; also elsewhere on the board
SERIAL_NUM: ASSY1.B0, R8.2, TP13.TESTPOINT, U3.2 (DATA)
VCC: ASSY1.3V3, R8.1, TP4.TESTPOINT, U12.5 (VSUPP), U12.6 (VSUPP); also elsewhere on the board
WDI: ASSY1.DAC, TP25.TESTPOINT; also elsewhere on the board
WIFI_PWR_EN: ASSY1.B1, TP1.TESTPOINT; also elsewhere on the board
WIFI_RXD: ASSY1.C1, TP3.TESTPOINT; also elsewhere on the board
WIFI_TXD: ASSY1.C0, TP2.TESTPOINT; also elsewhere on the board

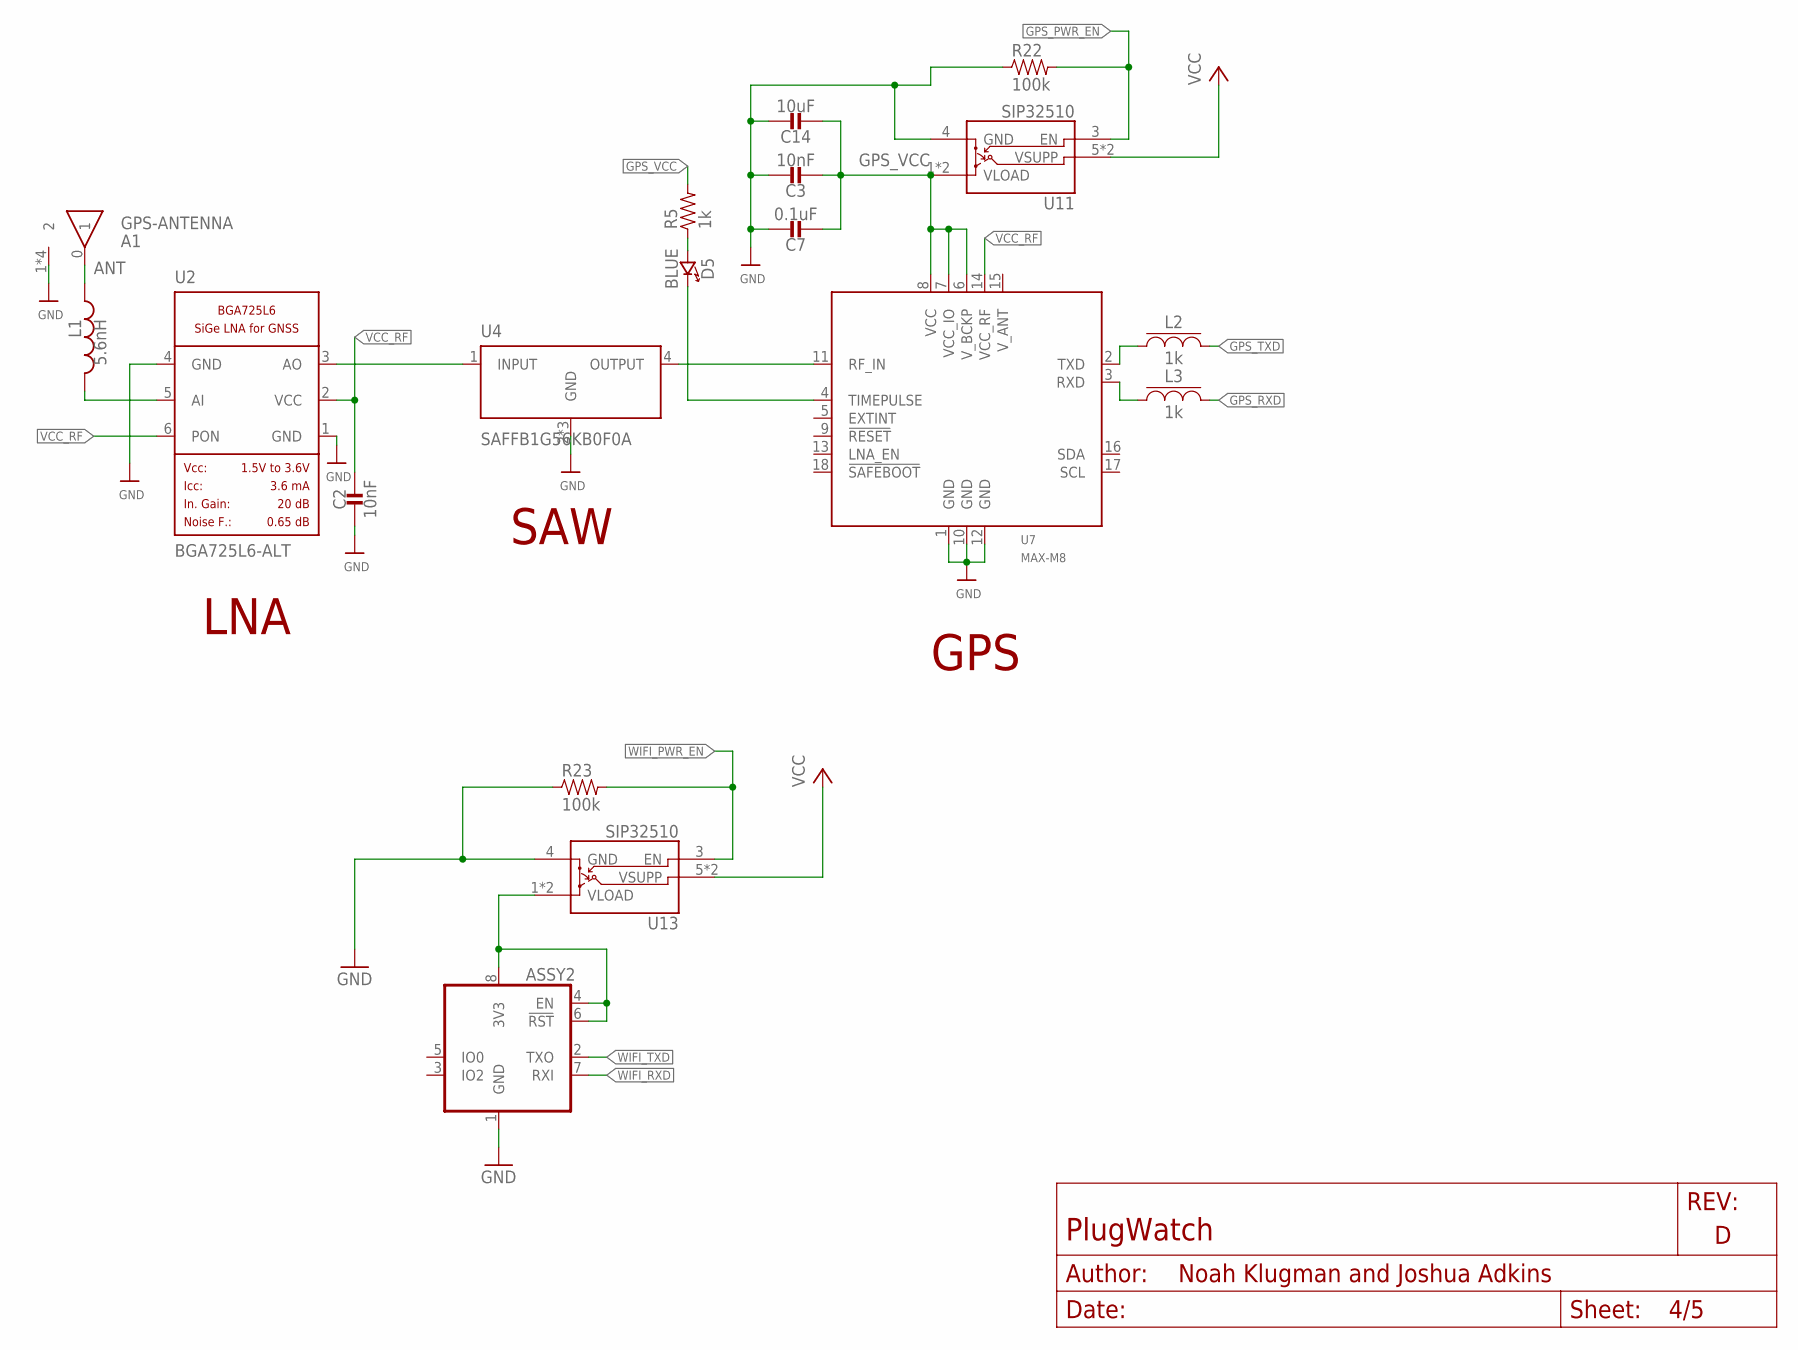
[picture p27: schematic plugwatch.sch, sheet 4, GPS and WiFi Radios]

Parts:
A1: GPS-ANTENNA; ANT1818B00BT1516S; MPN ANT1818B00BT1516S; DIGIKEY 311-1531-ND
ASSY2: WRL-13678
C2, C3: 10nF; 0402_CAP; MPN GRM155R71C103KA01D; DIGIKEY 490-1313-1-ND
C7: 0.1uF; 0402_CAP; MPN CC0402KRX5R6BB104; DIGIKEY 311-1336-1-ND
C14: 10uF; 0402_CAP; MPN GRJ155R60J106ME11D; DIGIKEY 490-13211-1-ND
D5: BLUE; LED-0603; MPN LTST-C194TBKT; DIGIKEY 160-1837-6-ND
L1: 5.6nH; 0402_CAP; MPN LQW15AN5N6B80D; DIGIKEY 490-11766-1-ND
L2, L3: 1k; 0402_CAP; MPN BLM15HD102SN1D; DIGIKEY 490-4003-1-ND
R5: 1k; 0402_RES; MPN RMCF0402FT1K00; DIGIKEY RMCF0402FT1K00CT-ND
R22, R23: 100k; 0402_RES; MPN CRCW0402100KFKED; DIGIKEY 541-100KLCT-ND
U2: BGA725L6-ALT; LNA-TSLP-6-2-ALT; MPN BGA725L6E6327FTSA1; DIGIKEY BGA725L6E6327FTSA1CT-ND
U4: SAFFB1G56KB0F0A; QCS5I; MPN F6QA1G582H2JM-J; DIGIKEY 587-3990-1-ND
U7: MAX-M8; MPN MAX-M8Q-0; DIGIKEY 672-1003-1-ND
U11, U13: SIP32510; TSOT23-6

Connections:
ANT: A1.0 (1), L1.2
GND: A1.1 (2), A1.2, A1.3 (2), A1.4 (2), ASSY2.1 (GND), C2.1, C3.1, C7.1, C14.1, R22.1, R23.1, U2.1 (GND), U2.4 (GND), U4.2 (GND), U4.3 (GND), U4.5 (GND), U7.1 (GND), U7.10 (GND), U7.12 (GND), U11.4 (GND), U13.4 (GND); also elsewhere on the board
GPS_PWR_EN: R22.2, U11.3 (EN); also elsewhere on the board
GPS_RF_IN: U4.4 (OUTPUT), U7.11 (RF_IN)
GPS_RXD: L3.2; also elsewhere on the board
GPS_TXD: L2.2; also elsewhere on the board
GPS_VCC: C3.2, C7.2, C14.2, R5.2, U7.6 (V_BCKP), U7.7 (VCC_IO), U7.8 (VCC), U11.1 (VLOAD), U11.2 (VLOAD)
LNA_IN: L1.1, U2.5 (AI)
LNA_OUT: U2.3 (AO), U4.1 (INPUT)
unnamed: D5.A (ANODE), R5.1
unnamed: D5.C (CATHODE), U7.4 (TIMEPULSE)
unnamed: ASSY2.4 (EN), ASSY2.6 (!RST), ASSY2.8 (3V3), U13.1 (VLOAD), U13.2 (VLOAD)
unnamed: L2.1, U7.2 (TXD)
unnamed: L3.1, U7.3 (RXD)
VCC: U11.5 (VSUPP), U11.6 (VSUPP), U13.5 (VSUPP), U13.6 (VSUPP); also elsewhere on the board
VCC_RF: C2.2, U2.2 (VCC), U2.6 (PON), U7.14 (VCC_RF)
WIFI_PWR_EN: R23.2, U13.3 (EN); also elsewhere on the board
WIFI_RXD: ASSY2.7 (RXI); also elsewhere on the board
WIFI_TXD: ASSY2.2 (TXO); also elsewhere on the board

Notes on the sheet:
GPS
LNA
SAW

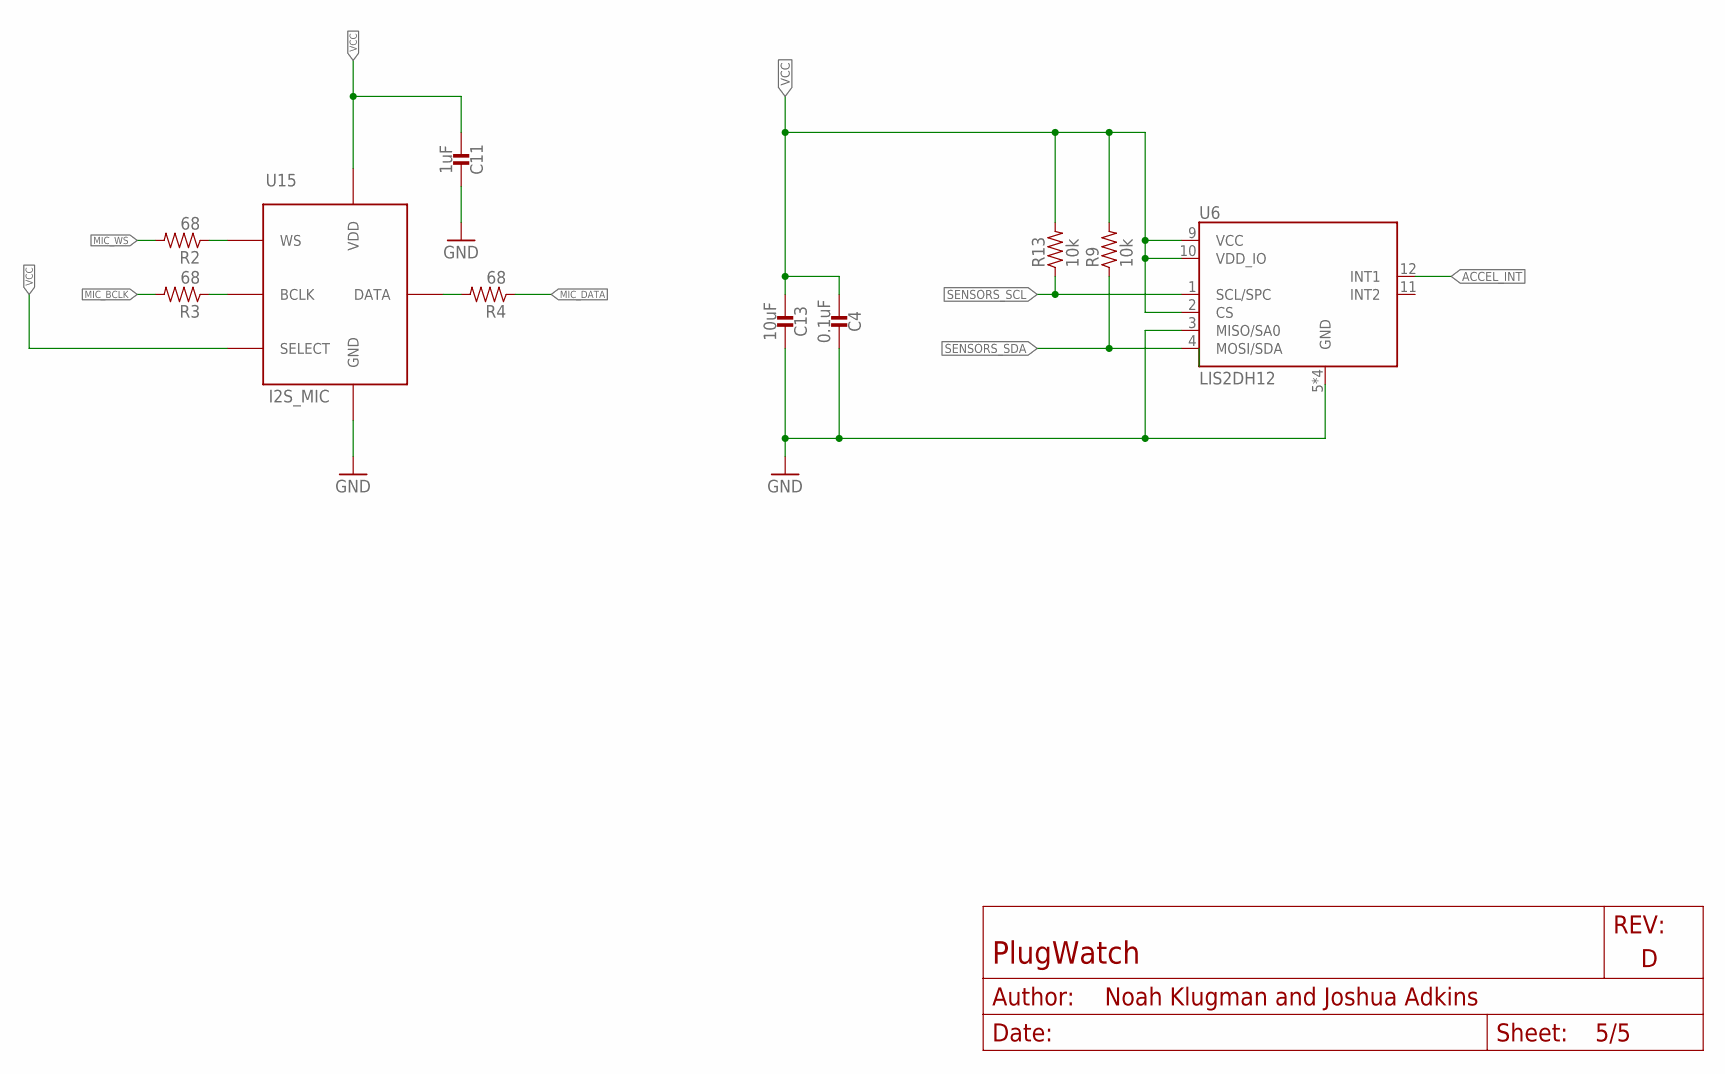
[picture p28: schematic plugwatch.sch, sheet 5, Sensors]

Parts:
C4: 0.1uF; 0402_CAP; MPN CC0402KRX5R6BB104; DIGIKEY 311-1336-1-ND
C11: 1uF; 0402_CAP; MPN GCM155C71A105KE38D; DIGIKEY 490-13409-1-ND
C13: 10uF; 0402_CAP; MPN GRJ155R60J106ME11D; DIGIKEY 490-13211-1-ND
R2, R3, R4: 68; 0402_RES; MPN RC0402FR-0768RL; DIGIKEY 311-68.0LRCT-ND
R9, R13: 10k; 0402_RES; MPN RMCF0402FT10K0; DIGIKEY RMCF0402FT10K0CT-ND
U6: LIS2DH12; LGA-12; MPN LIS2DH12TR; DIGIKEY 497-14851-1-ND
U15: SPH0645LM4H-B; SPH0465; DIGIKEY 423-1405-1-ND

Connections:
ACCEL_INT: U6.12 (INT1); also elsewhere on the board
GND: C4.2, C11.2, C13.2, U6.3 (MISO/SA0), U6.5 (GND), U6.6 (GND), U6.7 (GND), U6.8 (GND), U15.3 (GND); also elsewhere on the board
MIC_BCLK: R3.2; also elsewhere on the board
MIC_DATA: R4.1; also elsewhere on the board
MIC_WS: R2.2; also elsewhere on the board
unnamed: R2.1, U15.1 (WS)
unnamed: R3.1, U15.4 (BCLK)
unnamed: R4.2, U15.6 (DATA)
SENSORS_SCL: R13.1, U6.1 (SCL/SPC); also elsewhere on the board
SENSORS_SDA: R9.1, U6.4 (MOSI/SDA); also elsewhere on the board
VCC: C4.1, C11.1, C13.1, R9.2, R13.2, U6.2 (CS), U6.9 (VCC), U6.10 (VDD_IO), U15.2 (SELECT), U15.5 (VDD); also elsewhere on the board

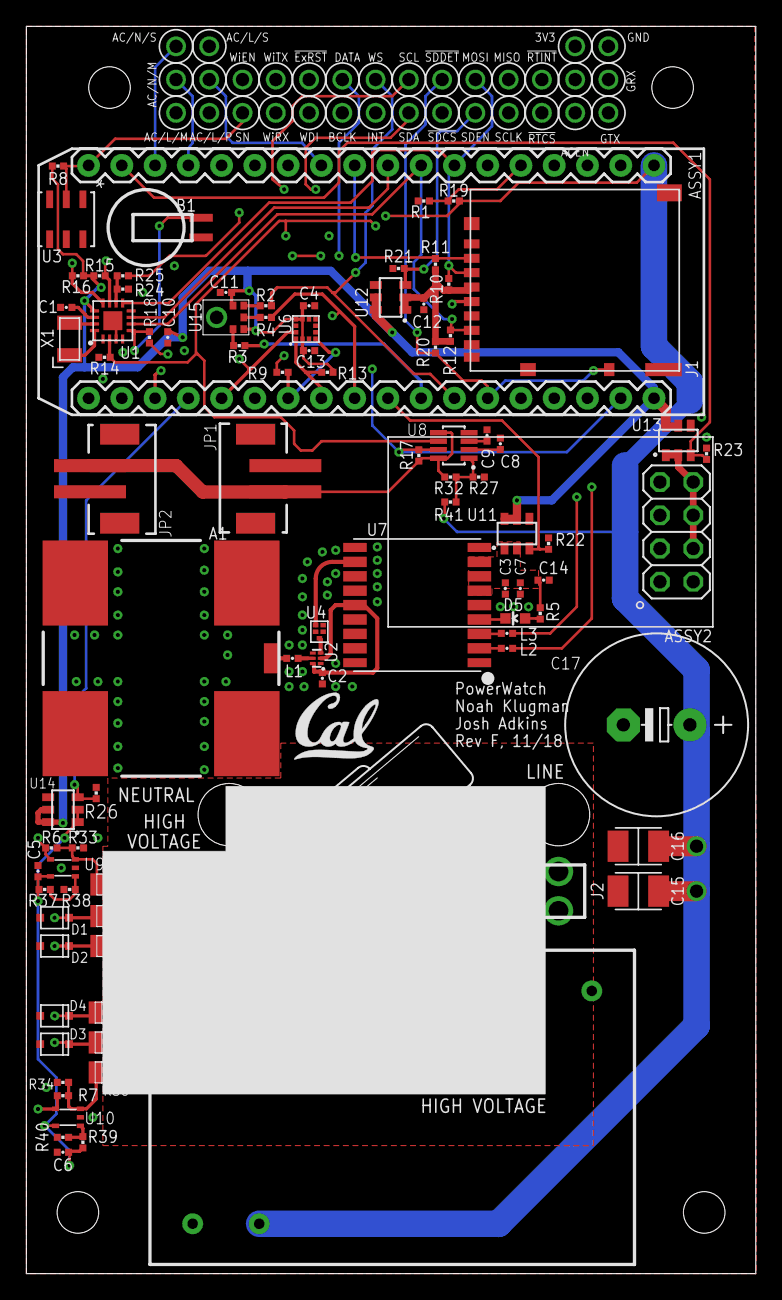
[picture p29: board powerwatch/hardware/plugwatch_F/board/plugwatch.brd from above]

Board: 4 copper layers, 55.7 x 95.2 mm, 126 parts (0 on the bottom side), 66 nets.

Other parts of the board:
U$3: UCB_CAL_200MIL

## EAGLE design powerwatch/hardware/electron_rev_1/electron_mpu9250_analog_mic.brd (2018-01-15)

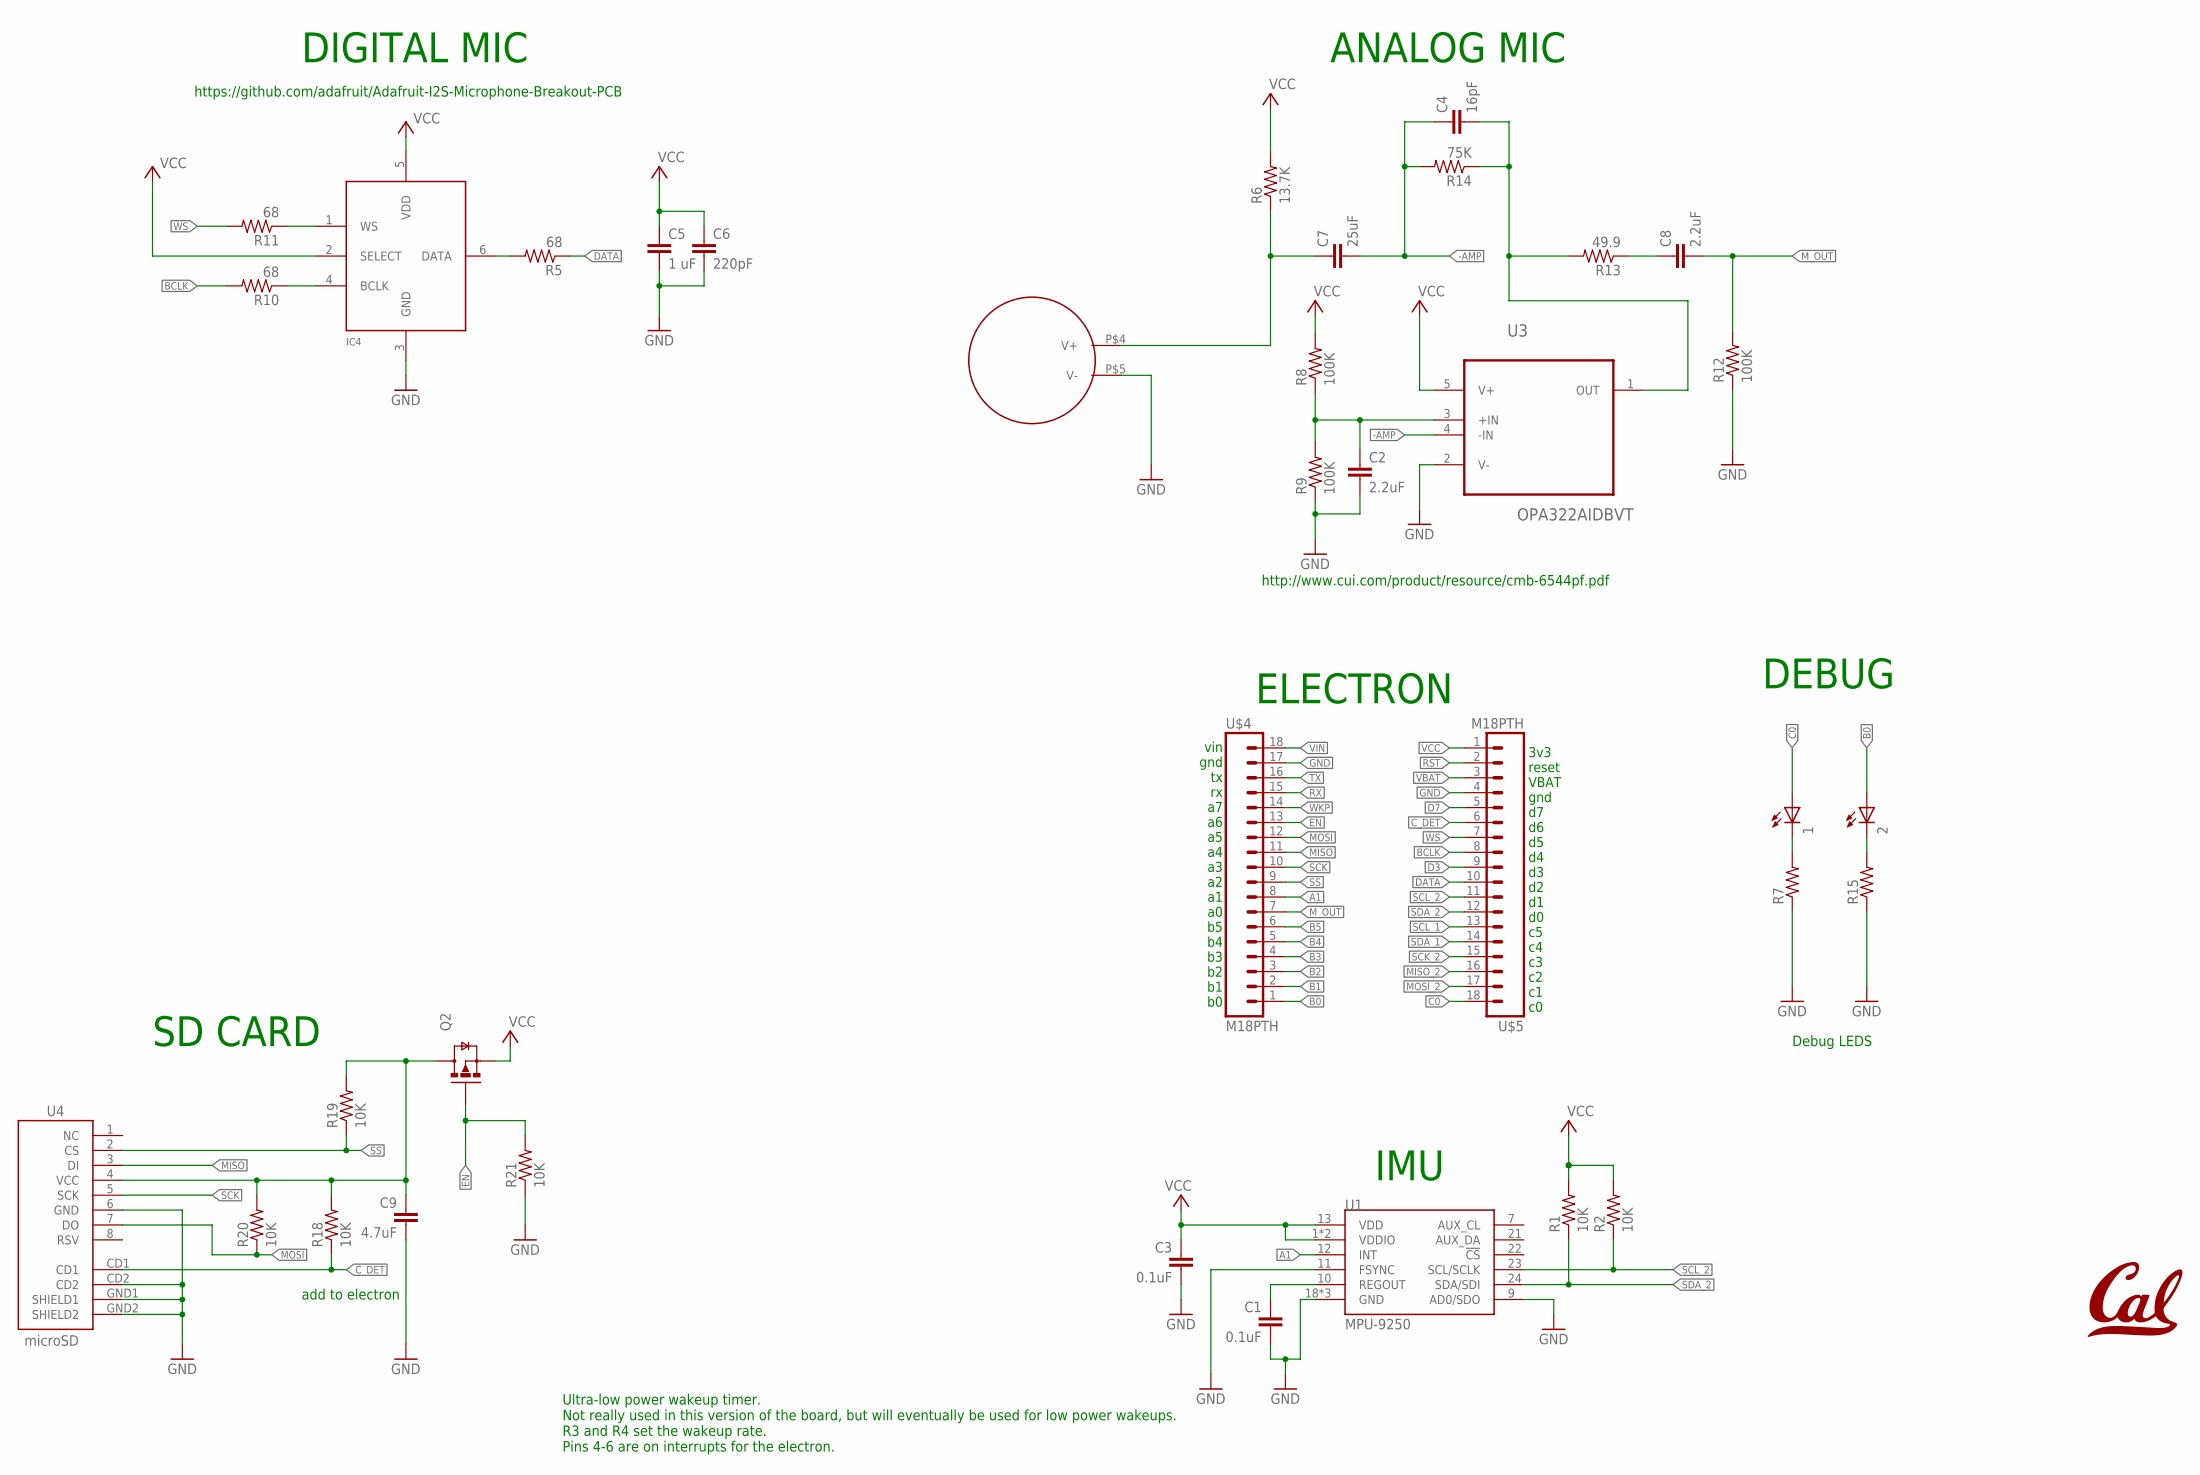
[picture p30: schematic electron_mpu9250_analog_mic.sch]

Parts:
1, 2: LEDCHIP-LED0603; CHIP-LED0603
C1, C3: 0.1uF; 0603-CAP
C2, C8: 2.2uF; C0603
C4: 16pF; C0603
C5: 1 uF; C0603
C6: 220pF; C0603
C7: 25uF; C0603
C9: 4.7uF; 0603-CAP
IC4: MIC_I2S_SPH0645; SPH0645LM4H
L1: UCB_CAL100MIL; UCB_CAL_100MIL
Q2: NX3008PBK; SOT23-3
R1, R2: 10K; 0603-RES
R5, R10, R11: 68; R0603
R6: 13.7K; R0603
R7, R15: R-US_R0603; R0603
R8, R9, R12: 100K; R0603
R13: 49.9; R0603
R14: 75K; R0603
R18, R19, R20, R21: 10K; R0603
U1: MPU-9250; QFN24_PAD
U3: OPA322AIDBVT; SOT95P280X145-5N
U4: microSD; MICRO-SD-SOCKET-PP
U$1: CMB-6544PF
U$4, U$5: M18PTH; 1X18-SMALL-PADS

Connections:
-AMP: C4.1, C7.2, R14.2, U3.4 (-IN)
A1: U1.12 (INT), U$4.8
B0: 2.A, U$4.1
B1: U$4.2
B2: U$4.3
B3: U$4.4
B4: U$4.5
B5: U$4.6
BCLK: R10.2, U$5.8
C0: 1.A, U$5.18
C_DET: R18.1, U4.CD1, U$5.6
D3: U$5.9
D7: U$5.5
DATA: R5.1, U$5.10
EN: Q2.1 (G), R21.2, U$4.13
GND: C1.2, C2.2, C3.2, C5.2, C6.2, C9.2, IC4.3 (GND), R7.1, R9.1, R12.1, R15.1, R21.1, U1.9 (AD0/SDO), U1.11 (FSYNC), U1.18 (GND), U1.20 (GND), U1.CENTER (GND), U3.2 (V-), U4.6 (GND), U4.CD2, U4.GND1 (SHIELD1), U4.GND2 (SHIELD2), U$1.P$5 (V-), U$4.17, U$5.4
MISO: U4.3 (DI), U$4.11
MISO_2: U$5.16
MOSI: R20.1, U4.7 (DO), U$4.12
MOSI_2: U$5.17
M_OUT: C8.2, R12.2, U$4.7
unnamed: C7.1, R6.1, U$1.P$4 (V+)
unnamed: IC4.1 (WS), R11.1
unnamed: C4.2, R13.2, R14.1, U3.1 (OUT)
unnamed: IC4.4 (BCLK), R10.1
unnamed: 1.C, R7.2
unnamed: IC4.6 (DATA), R5.2
unnamed: C8.1, R13.1
unnamed: 2.C, R15.2
unnamed: C2.1, R8.1, R9.2, U3.3 (+IN)
unnamed: C9.1, Q2.3 (D), R18.2, R19.2, R20.2, U4.4 (VCC)
REGOUT: C1.1, U1.10 (REGOUT)
RST: U$5.2
RX: U$4.15
SCK: U4.5 (SCK), U$4.10
SCK_2: U$5.15
SCL_1: U$5.13
SCL_2: R2.1, U1.23 (SCL/SCLK), U$5.11
SDA_1: U$5.14
SDA_2: R1.1, U1.24 (SDA/SDI), U$5.12
SS: R19.1, U4.2 (CS), U$4.9
TX: U$4.16
VBAT: U$5.3
VCC: C3.1, C5.1, C6.1, IC4.2 (SELECT), IC4.5 (VDD), Q2.2 (S), R1.2, R2.2, R6.2, R8.2, U1.1 (VDDIO), U1.8 (VDDIO), U1.13 (VDD), U3.5 (V+), U$5.1
VIN: U$4.18
WKP: U$4.14
WS: R11.2, U$5.7

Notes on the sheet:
https://github.com/adafruit/Adafruit-I2S-Microphone-Breakout-PCB
http://www.cui.com/product/resource/cmb-6544pf.pdf
Ultra-low power wakeup timer. Not really used in this version of the board, but will eventually be used for low power wakeups. R3 and R4 set the wakeup rate. Pins 4-6 are on interrupts for the electron.
Debug LEDS
ANALOG MIC
DIGITAL MIC
SD CARD
IMU
ELECTRON
DEBUG
add to electron
3v3 reset VBAT gnd d7 d6 d5 d4 d3 d2 d1 d0 c5 c4 c3 c2 c1 c0
vin gnd tx rx a7 a6 a5 a4 a3 a2 a1 a0 b5 b4 b3 b2 b1 b0

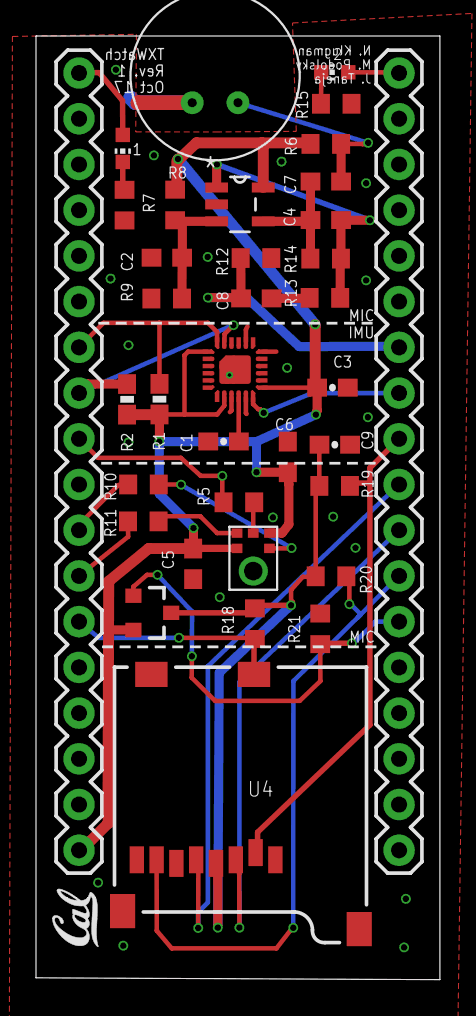
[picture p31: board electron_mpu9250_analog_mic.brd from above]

Board: 2 copper layers, 22.4 x 52.4 mm, 37 parts (0 on the bottom side), 29 nets.

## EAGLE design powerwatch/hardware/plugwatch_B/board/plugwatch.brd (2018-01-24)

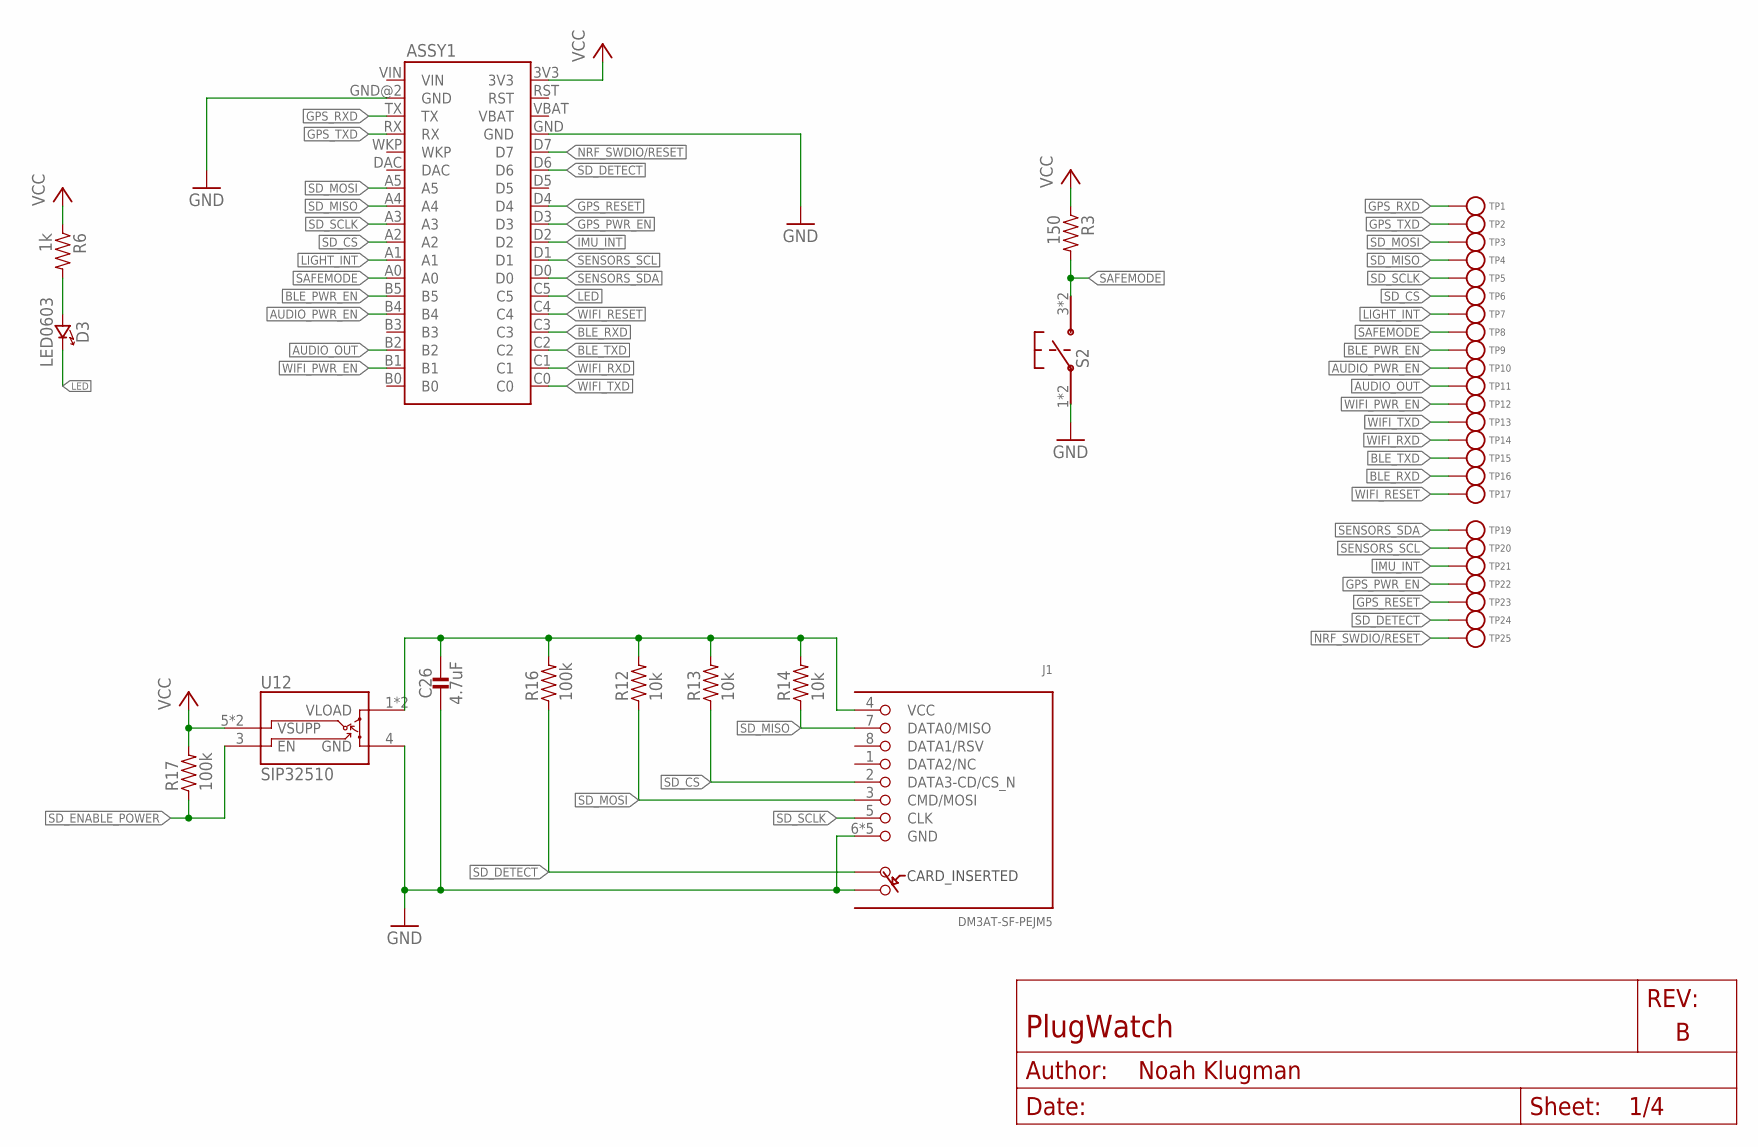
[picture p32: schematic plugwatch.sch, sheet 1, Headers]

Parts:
ASSY1: ELECTRON; ELECTRON_SINGLE-ROW; DIGIKEY S7051-ND,S7051-ND
C26: 4.7uF; 0402_CAP; DIGIKEY 445-5947-1-ND
D3: LED0603; LED-0603; DIGIKEY 160-1837-6-ND
J1: DM3AT-SF-PEJM5
R3: 150; 0402_RES; DIGIKEY RMCF0402FT150RCT-ND
R6: 1k; 0402_RES; DIGIKEY RMCF0402FT1K00CT-ND
R12, R13, R14: 10k; 0402_RES; DIGIKEY RMCF0402FT10K0CT-ND
R16, R17: 100k; 0402_RES; DIGIKEY 1276-3432-1-ND
S2: PTS645SM43SMTR92; PTS645
TP1, TP2, TP3, TP4, TP5, TP6, TP7, TP8, TP9, TP10, TP11, TP12, TP13, TP14, TP15, TP16, TP17, TP19, TP20, TP21, TP22, TP23, TP24, TP25: TEST_POINT_0.040IN; TESTPOINT_0.040IN
U12: SIP32510; TSOT23-6

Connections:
!GPS_RESET: ASSY1.D4, TP23.TESTPOINT; also elsewhere on the board
!IMU_INT: ASSY1.D2, TP21.TESTPOINT; also elsewhere on the board
!LIGHT_INT: ASSY1.A1, TP7.TESTPOINT; also elsewhere on the board
!SAFEMODE: ASSY1.A0, R3.2, S2.3, S2.4, TP8.TESTPOINT
!SD_CS: ASSY1.A2, J1.2 (DATA3-CD/CS_N), R13.1, TP6.TESTPOINT
!SD_DETECT: ASSY1.D6, J1.A, R16.1, TP24.TESTPOINT
!WIFI_RESET: ASSY1.C4, TP17.TESTPOINT; also elsewhere on the board
AUDIO_OUT: ASSY1.B2, TP11.TESTPOINT; also elsewhere on the board
AUDIO_PWR_EN: ASSY1.B4, TP10.TESTPOINT; also elsewhere on the board
BLE_PWR_EN: ASSY1.B5, TP9.TESTPOINT; also elsewhere on the board
BLE_RXD: ASSY1.C3, TP16.TESTPOINT; also elsewhere on the board
BLE_TXD: ASSY1.C2, TP15.TESTPOINT; also elsewhere on the board
GND: ASSY1.GND, ASSY1.GND@2 (GND), C26.2, J1.6 (GND), J1.B, J1.MOUNT0 (GND), J1.MOUNT1 (GND), J1.MOUNT2 (GND), J1.MOUNT3 (GND), S2.1, S2.2, U12.4 (GND); also elsewhere on the board
GPS_PWR_EN: ASSY1.D3, TP22.TESTPOINT; also elsewhere on the board
GPS_RXD: ASSY1.TX, TP1.TESTPOINT; also elsewhere on the board
GPS_TXD: ASSY1.RX, TP2.TESTPOINT; also elsewhere on the board
LED: ASSY1.C5, D3.C (CATHODE)
unnamed: D3.A (ANODE), R6.2
unnamed: C26.1, J1.4 (VCC), R12.2, R13.2, R14.2, R16.2, U12.1 (VLOAD), U12.2 (VLOAD)
NRF_SWDIO/!RESET: ASSY1.D7, TP25.TESTPOINT; also elsewhere on the board
SD_ENABLE_POWER: R17.1, U12.3 (EN)
SD_MISO: ASSY1.A4, J1.7 (DATA0/MISO), R14.1, TP4.TESTPOINT
SD_MOSI: ASSY1.A5, J1.3 (CMD/MOSI), R12.1, TP3.TESTPOINT
SD_SCLK: ASSY1.A3, J1.5 (CLK), TP5.TESTPOINT
SENSORS_SCL: ASSY1.D1, TP20.TESTPOINT; also elsewhere on the board
SENSORS_SDA: ASSY1.D0, TP19.TESTPOINT; also elsewhere on the board
VCC: ASSY1.3V3, R3.1, R6.1, R17.2, U12.5 (VSUPP), U12.6 (VSUPP); also elsewhere on the board
VIN: ASSY1.VIN
WIFI_PWR_EN: ASSY1.B1, TP12.TESTPOINT; also elsewhere on the board
WIFI_RXD: ASSY1.C1, TP14.TESTPOINT; also elsewhere on the board
WIFI_TXD: ASSY1.C0, TP13.TESTPOINT; also elsewhere on the board

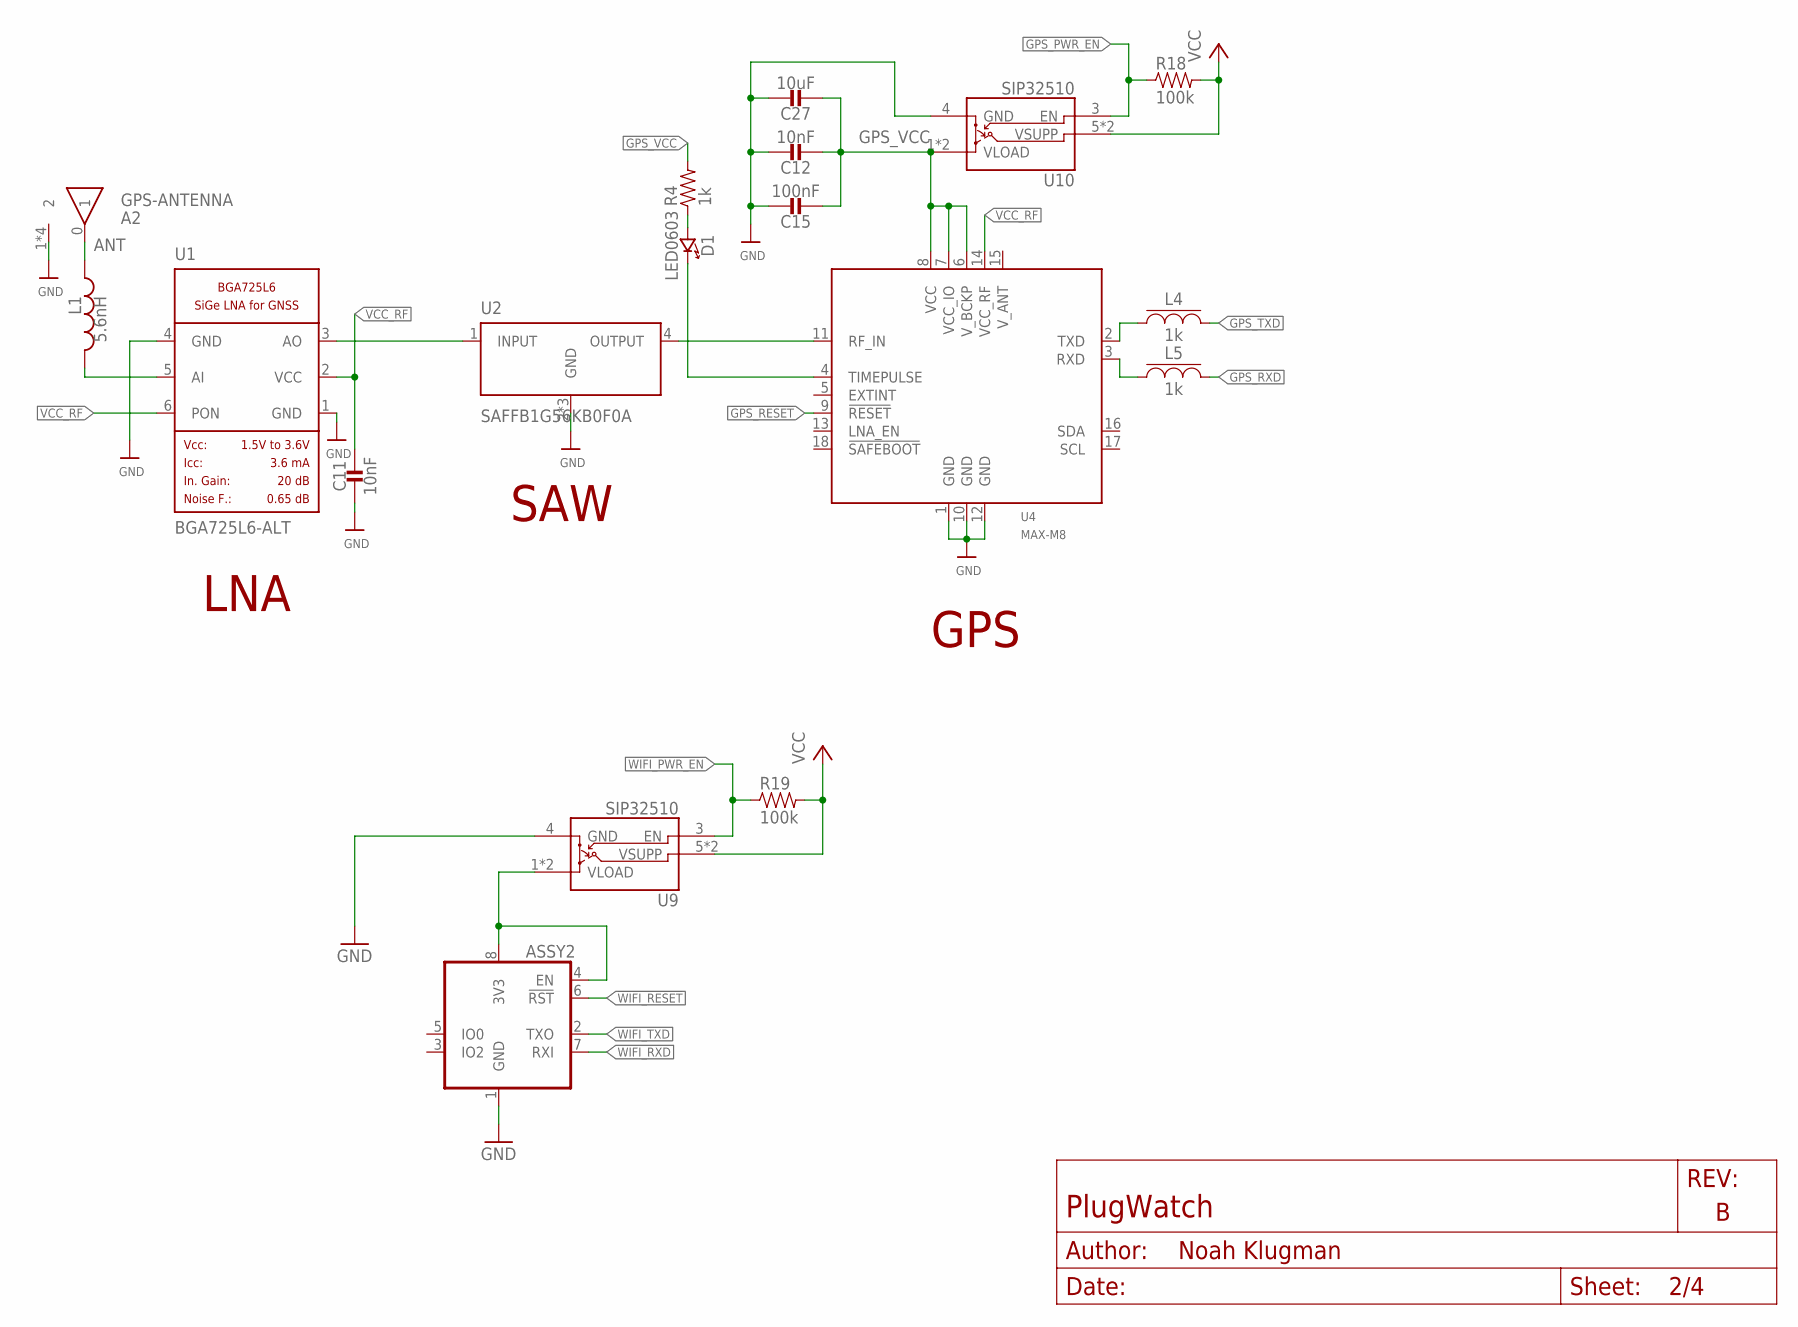
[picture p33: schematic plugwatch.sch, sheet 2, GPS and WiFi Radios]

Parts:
A2: GPS-ANTENNA; ANT1818B00BT1516S; DIGIKEY 311-1531-ND
ASSY2: WRL-13678
C11, C12: 10nF; 0402_CAP; DIGIKEY 490-7763-1-ND
C15: 100nF; 0402_CAP; DIGIKEY 490-10777-1-ND
C27: 10uF; 0402_CAP; DIGIKEY 490-8316-1-ND
D1: LED0603; LED-0603; DIGIKEY 160-1837-6-ND
L1: 5.6nH; 0402_CAP; DIGIKEY 490-11766-1-ND
L4, L5: 1k; 0402_CAP; DIGIKEY 490-4003-1-ND
R4: 1k; 0402_RES; DIGIKEY RMCF0402FT1K00CT-ND
R18, R19: 100k; 0402_RES; DIGIKEY 1276-3432-1-ND
U1: BGA725L6-ALT; LNA-TSLP-6-2-ALT; DIGIKEY BGA725L6E6327FTSA1CT-ND
U2: SAFFB1G56KB0F0A; QCS5I
U4: MAX-M8; DIGIKEY 672-1003-1-ND
U9, U10: SIP32510; TSOT23-6

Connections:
!GPS_RESET: U4.9 (!RESET); also elsewhere on the board
!WIFI_RESET: ASSY2.6 (!RST); also elsewhere on the board
ANT: A2.0 (1), L1.2
GND: A2.1 (2), A2.2, A2.3 (2), A2.4 (2), ASSY2.1 (GND), C11.1, C12.1, C15.1, C27.1, U1.1 (GND), U1.4 (GND), U2.2 (GND), U2.3 (GND), U2.5 (GND), U4.1 (GND), U4.10 (GND), U4.12 (GND), U9.4 (GND), U10.4 (GND); also elsewhere on the board
GPS_PWR_EN: R18.1, U10.3 (EN); also elsewhere on the board
GPS_RF_IN: U2.4 (OUTPUT), U4.11 (RF_IN)
GPS_RXD: L5.2; also elsewhere on the board
GPS_TXD: L4.2; also elsewhere on the board
GPS_VCC: C12.2, C15.2, C27.2, R4.2, U4.6 (V_BCKP), U4.7 (VCC_IO), U4.8 (VCC), U10.1 (VLOAD), U10.2 (VLOAD)
LNA_IN: L1.1, U1.5 (AI)
LNA_OUT: U1.3 (AO), U2.1 (INPUT)
unnamed: D1.A (ANODE), R4.1
unnamed: D1.C (CATHODE), U4.4 (TIMEPULSE)
unnamed: ASSY2.4 (EN), ASSY2.8 (3V3), U9.1 (VLOAD), U9.2 (VLOAD)
unnamed: L4.1, U4.2 (TXD)
unnamed: L5.1, U4.3 (RXD)
VCC: R18.2, R19.2, U9.5 (VSUPP), U9.6 (VSUPP), U10.5 (VSUPP), U10.6 (VSUPP); also elsewhere on the board
VCC_RF: C11.2, U1.2 (VCC), U1.6 (PON), U4.14 (VCC_RF)
WIFI_PWR_EN: R19.1, U9.3 (EN); also elsewhere on the board
WIFI_RXD: ASSY2.7 (RXI); also elsewhere on the board
WIFI_TXD: ASSY2.2 (TXO); also elsewhere on the board

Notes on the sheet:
LNA
SAW
GPS

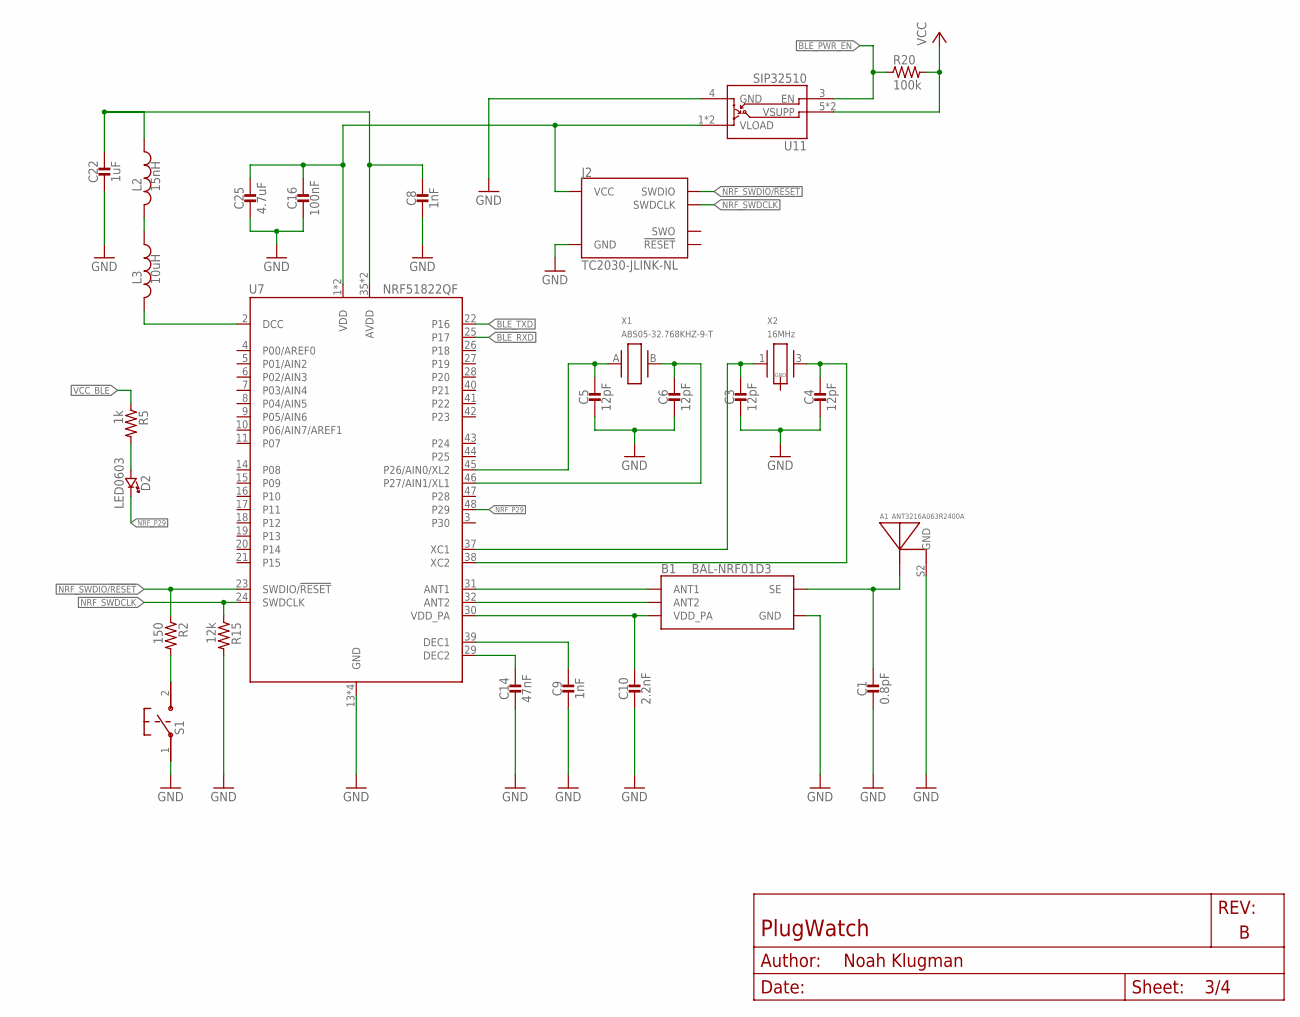
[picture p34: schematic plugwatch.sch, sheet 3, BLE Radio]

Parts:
A1: ANT3216A063R2400A
B1: BAL-NRF01D3
C1: 0.8pF; 0402_CAP; DIGIKEY 490-6269-1-ND
C3, C4, C5, C6: 12pF; 0402_CAP; DIGIKEY 490-6197-1-ND
C8, C9: 1nF; 0402_CAP; DIGIKEY 490-6366-1-ND
C10: 2.2nF; 0402_CAP; DIGIKEY 490-5419-1-ND
C14: 47nF; 0402_CAP; DIGIKEY 490-11420-1-ND
C16: 100nF; 0402_CAP; DIGIKEY 490-10777-1-ND
C22: 1uF; 0402_CAP; DIGIKEY 490-14457-1-ND
C25: 4.7uF; 0402_CAP; DIGIKEY 445-5947-1-ND
D2: LED0603; LED-0603; DIGIKEY 160-1837-6-ND
J2: TC2030-JLINK-NL; TC2030-IDC-NL
L2: 15nH; 0402_CAP; DIGIKEY 587-1521-1-ND
L3: 10uH; 0603_CAP; DIGIKEY 490-4025-1-ND
R2: 150; 0402_RES; DIGIKEY RMCF0402FT150RCT-ND
R5: 1k; 0402_RES; DIGIKEY RMCF0402FT1K00CT-ND
R15: 12k; 0402_RES; DIGIKEY RMCF0402FT12K0CT-ND
R20: 100k; 0402_RES; DIGIKEY 1276-3432-1-ND
S1: B3U-1000P
U7: NRF51822QF; QFN-48-6MM
U11: SIP32510; TSOT23-6
X1: ABS05-32.768KHZ-9-T; ABS05
X2: 16MHz; TXC-8Y; DIGIKEY 887-2003-1-ND

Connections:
AVDD1: C8.1, C22.1, L2.1, U7.35 (AVDD), U7.36 (AVDD)
BLE_PWR_EN: R20.1, U11.3 (EN); also elsewhere on the board
BLE_RXD: U7.25 (P17); also elsewhere on the board
BLE_TXD: U7.22 (P16); also elsewhere on the board
DCC1: L3.2, U7.2 (DCC)
GND: A1.S2 (GND), B1.GND, C1.2, C3.2, C4.2, C5.2, C6.2, C8.2, C9.2, C10.2, C14.2, C16.2, C22.2, C25.2, J2.5 (GND), R15.2, S1.1, U7.13 (GND), U7.33 (GND), U7.34 (GND), U7.GND, U11.4 (GND); also elsewhere on the board
unnamed: B1.ANT1, U7.31 (ANT1)
unnamed: B1.ANT2, U7.32 (ANT2)
unnamed: A1.S1 (ANTENNA), B1.SE, C1.1
unnamed: L2.2, L3.1
unnamed: C3.1, U7.37 (XC1), X2.1
unnamed: C4.1, U7.38 (XC2), X2.3 (2)
unnamed: C9.1, U7.39 (DEC1)
unnamed: C14.1, U7.29 (DEC2)
unnamed: D2.A (ANODE), R5.2
unnamed: R2.2, S1.2
NRF_A2: C6.1, U7.46 (P27/AIN1/XL1), X1.B (2)
NRF_A3: C5.1, U7.45 (P26/AIN0/XL2), X1.A (1)
NRF_P29: D2.C (CATHODE), U7.48 (P29)
NRF_SWDCLK: J2.4 (SWDCLK), R15.1, U7.24 (SWDCLK)
NRF_SWDIO/!RESET: J2.2 (SWDIO), R2.1, U7.23 (SWDIO/!RESET); also elsewhere on the board
VCC: R20.2, U11.5 (VSUPP), U11.6 (VSUPP); also elsewhere on the board
VCC_BLE: C16.1, C25.1, J2.1 (VCC), R5.1, U7.1 (VDD), U7.12 (VDD), U11.1 (VLOAD), U11.2 (VLOAD)
VDD_PA1: B1.VCC (VDD_PA), C10.1, U7.30 (VDD_PA)

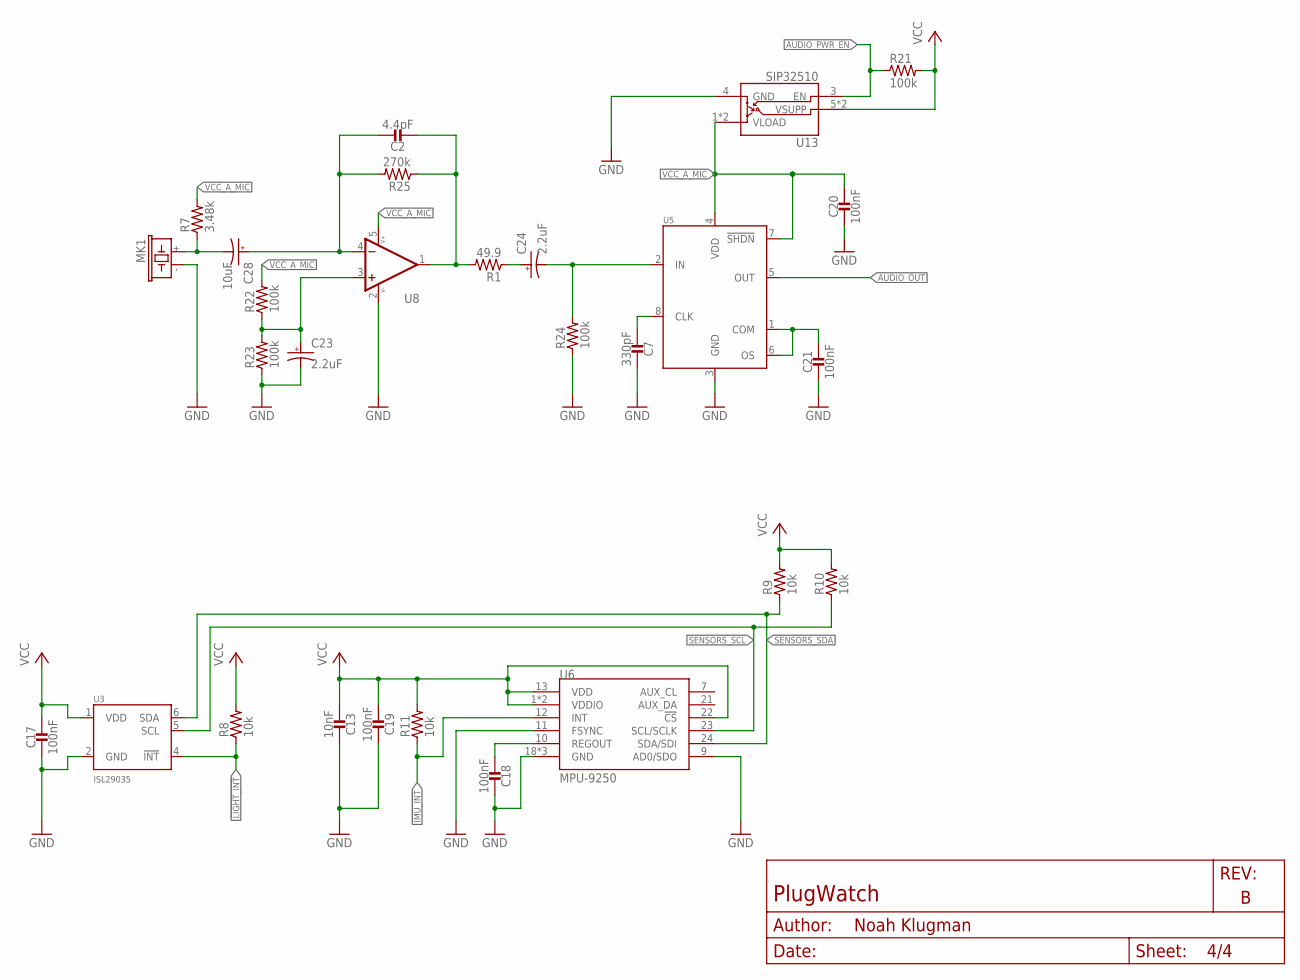
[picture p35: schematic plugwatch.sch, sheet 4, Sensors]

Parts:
C2: 4.4pF; 0603_CAP; DIGIKEY 399-16187-1-ND
C7: 330pF; 0402_CAP; DIGIKEY 490-6233-1-ND
C13: 10nF; 0402_CAP; DIGIKEY 490-7763-1-ND
C17, C18, C19, C20, C21: 100nF; 0402_CAP; DIGIKEY 490-10777-1-ND
C23, C24: 2.2uF; 1206; DIGIKEY 718-1131-1-ND
C28: 10uF; 1206; DIGIKEY 478-8481-1-ND
MK1: AOM-4546P-R; MIC_AOM-4546P-R
R1: 49.9; 0603-RES; DIGIKEY 541-3003-1-ND
R7: 3.48k; 0603-RES; DIGIKEY 541-3.48KHCT-ND
R8, R9, R10, R11: 10k; 0402_RES; DIGIKEY RMCF0402FT10K0CT-ND
R21: 100k; 0402_RES; DIGIKEY 1276-3432-1-ND
R22, R23, R24: 100k; 0603-RES; DIGIKEY 541-2972-1-ND
R25: 270k; 0603-RES; DIGIKEY 541-270KHCT-ND
U3: ISL29035; ODFN-6-1.5MMX1.6MM
U5: MAX740XESA; SOIC-8
U6: MPU-9250; QFN24_PAD; DIGIKEY 1428-1019-1-ND
U8: OPA322AIDBVT; SOT23-5
U13: SIP32510; TSOT23-6

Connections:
!IMU_INT: R11.1, U6.12 (INT); also elsewhere on the board
!LIGHT_INT: R8.1, U3.4 (!INT); also elsewhere on the board
-AMP: C2.1, C28.2 (CATHODE), R25.2, U8.4 (-IN)
AUDIO_OUT: U5.5 (OUT); also elsewhere on the board
AUDIO_PWR_EN: R21.1, U13.3 (EN); also elsewhere on the board
A_MIC_OUT: C24.1 (ANODE), R24.2, U5.2 (IN)
GND: C7.1, C13.2, C17.2, C18.2, C19.2, C20.2, C21.2, C23.1 (ANODE), MK1.TERM- (2), R23.1, R24.1, U3.2 (GND), U5.3 (GND), U6.9 (AD0/SDO), U6.11 (FSYNC), U6.18 (GND), U6.20 (GND), U6.CENTER (GND), U8.2 (V-), U13.4 (GND); also elsewhere on the board
unnamed: C28.1 (ANODE), MK1.TERM+ (1), R7.1
unnamed: C2.2, R1.2, R25.1, U8.1 (OUT)
unnamed: C7.2, U5.8 (CLK)
unnamed: C24.2 (CATHODE), R1.1
unnamed: C23.2 (CATHODE), R22.1, R23.2, U8.3 (+IN)
unnamed: C21.1, U5.1 (COM), U5.6 (OS)
REGOUT: C18.1, U6.10 (REGOUT)
SENSORS_SCL: R10.1, U3.5 (SCL), U6.23 (SCL/SCLK); also elsewhere on the board
SENSORS_SDA: R9.1, U3.6 (SDA), U6.24 (SDA/SDI); also elsewhere on the board
VCC: C13.1, C17.1, C19.1, R8.2, R9.2, R10.2, R11.2, R21.2, U3.1 (VDD), U6.1 (VDDIO), U6.8 (VDDIO), U6.13 (VDD), U6.22 (!CS), U13.5 (VSUPP), U13.6 (VSUPP); also elsewhere on the board
VCC_A_MIC: C20.1, R7.2, R22.2, U5.4 (VDD), U5.7 (!SHDN), U8.5 (V+), U13.1 (VLOAD), U13.2 (VLOAD)



Board: 4 copper layers, 57.1 x 93.0 mm, 111 parts (59 on the bottom side), 69 nets.

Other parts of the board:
U$3: UCB_CAL_200MIL

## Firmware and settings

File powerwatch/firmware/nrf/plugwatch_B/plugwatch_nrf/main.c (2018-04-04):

/*
 * Copyright (c) 2014 Nordic Semiconductor. All Rights Reserved.
 *
 * The information contained herein is confidential property of Nordic Semiconductor. The use,
 * copying, transfer or disclosure of such information is prohibited except by express written
 * agreement with Nordic Semiconductor.
 *
 */

/**
 * @brief BLE LED Button Service central and client application main file.
 *
 * This file contains the source code for a sample client application using the LED Button service.
 */

#include <stdint.h>
#include <stdio.h>
#include <string.h>
#include "nordic_common.h"
#include "softdevice_handler.h"
#include "app_timer.h"
#include "ble.h"
#include "app_uart.h"
#include "ble_advdata.h"
#include "ble_advertising.h"
#include "ble_conn_params.h"
#include "ble_db_discovery.h"
#include "ble_lbs_c.h"
#include "nrf_delay.h"

#include "led.h"

#define CENTRAL_LINK_COUNT        1                                        /**< Number of central links used by the application. When changing this number remember to adjust the RAM settings*/
#define PERIPHERAL_LINK_COUNT     0                                        /**< Number of peripheral links used by the application. When changing this number remember to adjust the RAM settings*/

#define UART_TX_BUF_SIZE          256                                      /**< Size of the UART TX buffer, in bytes. Must be a power of two. */
#define UART_RX_BUF_SIZE          256                                      /**< Size of the UART RX buffer, in bytes. Must be a power of two. */

#define CENTRAL_SCANNING_LED      29                                       /**< Scanning LED will be on when the device is scanning. */
//#define CENTRAL_CONNECTED_LED     13                                       /**< Connected LED will be on when the device is connected. */
#define APP_TIMER_PRESCALER       0                                        /**< Value of the RTC1 PRESCALER register. */
#define APP_TIMER_MAX_TIMERS      (2+BSP_APP_TIMERS_NUMBER)                /**< Maximum number of timers used by the application. */
#define APP_TIMER_OP_QUEUE_SIZE   2                                        /**< Size of timer operation queues. */

#define SEC_PARAM_BOND            1                                        /**< Perform bonding. */
#define SEC_PARAM_MITM            0                                        /**< Man In The Middle protection not required. */
#define SEC_PARAM_IO_CAPABILITIES BLE_GAP_IO_CAPS_NONE                     /**< No I/O capabilities. */
#define SEC_PARAM_OOB             0                                        /**< Out Of Band data not available. */
#define SEC_PARAM_MIN_KEY_SIZE    7                                        /**< Minimum encryption key size in octets. */
#define SEC_PARAM_MAX_KEY_SIZE    16                                       /**< Maximum encryption key size in octets. */

#define SCAN_INTERVAL             0x00A0                                   /**< Determines scan interval in units of 0.625 millisecond. */
#define SCAN_WINDOW               0x0050                                   /**< Determines scan window in units of 0.625 millisecond. */
#define SCAN_TIMEOUT              0x0010                                   /**< Timout when scanning. 0x0000 disables timeout. */
#define SCAN_REQUEST              0                                        /**< Active scanning is not set. */
#define SCAN_WHITELIST_ONLY       0                                        /**< We will not ignore unknown devices. */

#define MIN_CONNECTION_INTERVAL   MSEC_TO_UNITS(7.5, UNIT_1_25_MS)         /**< Determines minimum connection interval in milliseconds. */
#define MAX_CONNECTION_INTERVAL   MSEC_TO_UNITS(30, UNIT_1_25_MS)          /**< Determines maximum connection interval in milliseconds. */
#define SLAVE_LATENCY             0                                        /**< Determines slave latency in terms of connection events. */
#define SUPERVISION_TIMEOUT       MSEC_TO_UNITS(4000, UNIT_10_MS)          /**< Determines supervision time-out in units of 10 milliseconds. */

#define UUID16_SIZE               2                                        /**< Size of a UUID, in bytes. */

#define MAX_TEST_DATA_BYTES     (15U)                /**< max number of test bytes to be used for tx and rx. */

#define SCAN_LIST_MAX_LEN 20

static const char m_target_periph_name[] = "WIT";                         /**< Name of the device we try to connect to. This name is searched in the scan report data*/

static const uint8_t plugwatch_service_uuid[] = {0x00, 0x00, 0x48, 0x43,
  0x45, 0x54, 0x43, 0x49, 0x47, 0x4f, 0x4c, 0x49, 0xe0, 0xfe, 0x00, 0x00};

static const uint8_t plugwatch_wit_ffe1_uuid[] = {0x00, 0x00, 0x48, 0x43,
  0x45, 0x54, 0x43, 0x49, 0x47, 0x4f, 0x4c, 0x49, 0xe1, 0xfe, 0x00, 0x00};

static const uint8_t plugwatch_wit_ffe3_uuid[] = {0x00, 0x00, 0x48, 0x43,
  0x45, 0x54, 0x43, 0x49, 0x47, 0x4f, 0x4c, 0x49, 0xe3, 0xfe, 0x00, 0x00};

static size_t scan_name_list_len = 0;
static char* scan_name_list[SCAN_LIST_MAX_LEN];

/**@brief Variable length data encapsulation in terms of length and pointer to data. */
typedef struct
{
    uint8_t * p_data;   /**< Pointer to data. */
    uint16_t  data_len; /**< Length of data. */
} data_t;

/** @brief Scan parameters requested for scanning and connection. */
static const ble_gap_scan_params_t m_scan_param =
{
    SCAN_REQUEST,
    SCAN_WHITELIST_ONLY,
    NULL,
    (uint16_t)SCAN_INTERVAL,
    (uint16_t)SCAN_WINDOW,
    (uint16_t)SCAN_TIMEOUT
};

/**@brief Connection parameters requested for connection. */
static const ble_gap_conn_params_t m_connection_param =
{
    (uint16_t)MIN_CONNECTION_INTERVAL,
    (uint16_t)MAX_CONNECTION_INTERVAL,
    0,
    (uint16_t)SUPERVISION_TIMEOUT
};

static ble_db_discovery_t m_ble_db_discovery; /**< DB structure used by the database discovery module. */

/**@brief Function to handle asserts in the SoftDevice.
 *
 * @details This function will be called in case of an assert in the SoftDevice.
 *
 * @warning This handler is an example only and does not fit a final product. You need to analyze
 *          how your product is supposed to react in case of Assert.
 * @warning On assert from the SoftDevice, the system can only recover on reset.
 *
 * @param[in] line_num     Line number of the failing ASSERT call.
 * @param[in] p_file_name  File name of the failing ASSERT call.
 */
void assert_nrf_callback(uint16_t line_num, const uint8_t * p_file_name)
{
    app_error_handler(0xDEADBEEF, line_num, p_file_name);
}


/**@brief Function for the LEDs initialization.
 *
 * @details Initializes all LEDs used by the application.
 */
static void leds_init(void)
{
    led_init(CENTRAL_SCANNING_LED);
    led_off(CENTRAL_SCANNING_LED);
}


/**
 * @brief Parses advertisement data, providing length and location of the field in case
 *        matching data is found.
 *
 * @param[in]  type       Type of data to be looked for in advertisement data.
 * @param[in]  p_advdata  Advertisement report length and pointer to report.
 * @param[out] p_typedata If data type requested is found in the data report, type data length and
 *                        pointer to data will be populated here.
 *
 * @retval NRF_SUCCESS if the data type is found in the report.
 * @retval NRF_ERROR_NOT_FOUND if the data type could not be found.
 */
static uint32_t adv_report_parse(uint8_t type, data_t * p_advdata, data_t * p_typedata)
{
    uint32_t  index = 0;
    uint8_t * p_data;

    p_data = p_advdata->p_data;

    while (index < p_advdata->data_len)
    {
        uint8_t field_length = p_data[index];
        uint8_t field_type   = p_data[index+1];

        if (field_type == type)
        {
            p_typedata->p_data   = &p_data[index+2];
            p_typedata->data_len = field_length-1;
            return NRF_SUCCESS;
        }
        index += field_length + 1;
    }
    return NRF_ERROR_NOT_FOUND;
}

/**@brief Function to stop scanning.
 */
static inline void scan_stop(void)
{
    ret_code_t err_code;

    err_code = sd_ble_gap_scan_stop();
    // It is okay to ignore this error since we are stopping the scan anyway.
    if (err_code != NRF_ERROR_INVALID_STATE)
    {
        APP_ERROR_CHECK(err_code);
    }

    led_off(CENTRAL_SCANNING_LED);
}

/**@brief Function to start scanning.
 */
static void scan_start(void)
{
    ret_code_t err_code;

    scan_stop();

    err_code = sd_ble_gap_scan_start(&m_scan_param);
    APP_ERROR_CHECK(err_code);

    //led_off(CENTRAL_CONNECTED_LED);
    led_on(CENTRAL_SCANNING_LED);
}


///**@brief Handles events coming from the LED Button central module.
// */
//static void lbs_c_evt_handler(ble_lbs_c_t * p_lbs_c, ble_lbs_c_evt_t * p_lbs_c_evt)
//{
//    switch (p_lbs_c_evt->evt_type)
//    {
//        case BLE_LBS_C_EVT_DISCOVERY_COMPLETE:
//        {
//            ret_code_t err_code;
//
//            err_code = ble_lbs_c_handles_assign(&m_ble_lbs_c,
//                                                p_lbs_c_evt->conn_handle,
//                                                &p_lbs_c_evt->params.peer_db);
//            NRF_LOG_PRINTF("LED Button service discovered on conn_handle 0x%x\r\n", p_lbs_c_evt->conn_handle);
//
//            err_code = app_button_enable();
//            APP_ERROR_CHECK(err_code);
//
//            // LED Button service discovered. Enable notification of Button.
//            err_code = ble_lbs_c_button_notif_enable(p_lbs_c);
//            APP_ERROR_CHECK(err_code);
//        } break; // BLE_LBS_C_EVT_DISCOVERY_COMPLETE
//
//        case BLE_LBS_C_EVT_BUTTON_NOTIFICATION:
//        {
//            NRF_LOG_PRINTF("Button state changed on peer to 0x%x\r\n", p_lbs_c_evt->params.button.button_state);
//            if (p_lbs_c_evt->params.button.button_state)
//            {
//                LEDS_ON(LEDBUTTON_LED);
//            }
//            else
//            {
//                LEDS_OFF(LEDBUTTON_LED);
//            }
//        } break; // BLE_LBS_C_EVT_BUTTON_NOTIFICATION
//
//        default:
//            // No implementation needed.
//            break;
//    }
//}

/**@brief Function for handling the advertising report BLE event.
 *
 * @param[in] p_ble_evt  Bluetooth stack event.
 */
static void on_adv_report(const ble_evt_t * const p_ble_evt)
{
    uint32_t err_code;
    data_t   adv_data;
    bool     do_connect = false;
    data_t   dev_name;

    // For readibility.
    const ble_gap_evt_t * const  p_gap_evt  = &p_ble_evt->evt.gap_evt;
    const ble_gap_addr_t * const peer_addr  = &p_gap_evt->params.adv_report.peer_addr;
    {
        // Initialize advertisement report for parsing
        adv_data.p_data     = (uint8_t *)p_gap_evt->params.adv_report.data;
        adv_data.data_len   = p_gap_evt->params.adv_report.dlen;

        printf("Raw Advertisement: ");
        for (int i = 0; i < adv_data.data_len; i++) {
          printf("%02x", adv_data.p_data[i]);
        }
        printf("\n");

        //search for advertising names
        bool found_name = false;
        err_code = adv_report_parse(BLE_GAP_AD_TYPE_COMPLETE_LOCAL_NAME,
                                    &adv_data,
                                    &dev_name);
        if (err_code != NRF_SUCCESS)
        {
            // Look for the short local name if it was not found as complete
            err_code = adv_report_parse(BLE_GAP_AD_TYPE_SHORT_LOCAL_NAME,
                                        &adv_data,
                                        &dev_name);
            if (err_code != NRF_SUCCESS)
            {
                // If we can't parse the data, then exit
                return;
            }
            else
            {
                found_name = true;
            }
        }
        else
        {
            found_name = true;
        }
        if (found_name)
        {
            //if (strlen(m_target_periph_name) != 0)
            //{
                //if(memcmp(m_target_periph_name, dev_name.p_data, dev_name.data_len )== 0)
                //{
                //    do_connect = true;
                //}
            //}
            //if (scan_name_list_len < SCAN_LIST_MAX_LEN) {
              char name[32];
              memcpy(dev_name.p_data, name, dev_name.data_len);
              printf("Found device: ");
              for (int i = 0; i < dev_name.data_len; i++) {
                printf("%x", dev_name.p_data[i]);
              }
              printf("\n");
              //scan_name_list[scan_name_list_len] = malloc(dev_name.data_len);
              //memcpy(dev_name.p_data, scan_name_list[scan_name_list_len++], dev_name.data_len);
            //}
        }
    }

    //if (do_connect)
    //{
    //    // Initiate connection.
    //    err_code = sd_ble_gap_connect(peer_addr, &m_scan_param, &m_connection_param);
    //    APP_ERROR_CHECK(err_code);
    //}
}

/**@brief   Function for handling UART interrupts.
 *
 * @details
 *
 *
 */

static void uart_evt_callback(app_uart_evt_t * uart_evt) {
  uint32_t err_code;
  static uint8_t index;
  static uint8_t data[64];

  switch(uart_evt->evt_type) {
    case (APP_UART_COMMUNICATION_ERROR):
      APP_ERROR_HANDLER(uart_evt->data.error_communication);
      break;
    case (APP_UART_FIFO_ERROR):
      APP_ERROR_HANDLER(uart_evt->data.error_code);
      break;
    case (APP_UART_DATA_READY):
      err_code = app_uart_get(&data[index++]);
      app_uart_put(data[index - 1]);
      if (err_code != NRF_ERROR_INVALID_STATE) {
        APP_ERROR_CHECK(err_code);
      }
      if (data[index-1] == '\n' || index >= 64) {
        printf("Received: %s", data);
        if (memcmp(data, "SCAN", 4) == 0) {
          printf("SCAN START!\n");
          scan_start();
        }
        memset(data, 0, 64);
        index = 0;
      }


      break;
    case (APP_UART_TX_EMPTY):
      break;
    default: break;
  }

}

/**@brief Function for handling BLE Stack events concerning central applications.
 *
 * @details This function keeps the connection handles of central applications up-to-date. It
 * parses scanning reports, initiating a connection attempt to peripherals when a target UUID
 * is found, and manages connection parameter update requests. Additionally, it updates the status
 * of LEDs used to report central applications activity.
 *
 * @note Since this function updates connection handles, @ref BLE_GAP_EVT_DISCONNECTED events
 *       should be dispatched to the target application before invoking this function.
 *
 * @param[in] p_ble_evt Bluetooth stack event.
 */
static void on_ble_evt(const ble_evt_t * const p_ble_evt)
{
    // For readability.
    const ble_gap_evt_t * const p_gap_evt = &p_ble_evt->evt.gap_evt;

    switch (p_ble_evt->header.evt_id)
    {
        // Upon connection, check which peripheral has connected (HR or RSC), initiate DB
        // discovery, perform characteristic write and resume scanning if necessary. */
        case BLE_GAP_EVT_CONNECTED:
        {
            uint32_t err_code;

            //err_code = ble_lbs_c_handles_assign(&m_ble_lbs_c, p_gap_evt->conn_handle, NULL);
            //APP_ERROR_CHECK(err_code);

            err_code = ble_db_discovery_start(&m_ble_db_discovery, p_gap_evt->conn_handle);
            APP_ERROR_CHECK(err_code);

            // Update LEDs status, and check if we should be looking for more
            // peripherals to connect to.
            //led_on(CENTRAL_CONNECTED_LED);
            led_off(CENTRAL_SCANNING_LED);
        } break; // BLE_GAP_EVT_CONNECTED

        // Upon disconnection, reset the connection handle of the peer which disconnected, update
        // the LEDs status and start scanning again.
        case BLE_GAP_EVT_DISCONNECTED:
        {
            //scan_start();
        } break; // BLE_GAP_EVT_DISCONNECTED

        case BLE_GAP_EVT_ADV_REPORT:
            on_adv_report(p_ble_evt);
            break;

        case BLE_GAP_EVT_TIMEOUT:
        {
            // We have not specified a timeout for scanning, so only connection attemps can timeout.
            //if (p_gap_evt->params.timeout.src == BLE_GAP_TIMEOUT_SRC_CONN)
            //{
            //    //NRF_LOG_PRINTF("[APP]: Connection Request timed out.\r\n");
            //}
            if (p_gap_evt->params.timeout.src == BLE_GAP_TIMEOUT_SRC_SCAN)
            {
              // stop scan, send list of found device names
              scan_stop();
              printf("%u\n", scan_name_list_len);
              for (size_t i = 0; i < scan_name_list_len; i++) {
                printf("|%s", scan_name_list[i]);
                free(scan_name_list[i]);
                scan_name_list[i] = 0;
              }
              printf("\r\n");
              scan_name_list_len = 0;
            }

        } break; // BLE_GAP_EVT_TIMEOUT

        case BLE_GAP_EVT_CONN_PARAM_UPDATE_REQUEST:
        {
            // Accept parameters requested by peer.
            ret_code_t err_code;
            err_code = sd_ble_gap_conn_param_update(p_gap_evt->conn_handle,
                                        &p_gap_evt->params.conn_param_update_request.conn_params);
            APP_ERROR_CHECK(err_code);
        } break; // BLE_GAP_EVT_CONN_PARAM_UPDATE_REQUEST

        default:
            // No implementation needed.
            break;
    }
}


/**@brief Function for dispatching a BLE stack event to all modules with a BLE stack event handler.
 *
 * @details This function is called from the scheduler in the main loop after a BLE stack event has
 * been received.
 *
 * @param[in] p_ble_evt Bluetooth stack event.
 */
static void ble_evt_dispatch(ble_evt_t * p_ble_evt)
{
    on_ble_evt(p_ble_evt);
    ble_db_discovery_on_ble_evt(&m_ble_db_discovery, p_ble_evt);
    //ble_lbs_c_on_ble_evt(&m_ble_lbs_c, p_ble_evt);

}


/**@brief LED Button client initialization.
 */
//static void lbs_c_init(void)
//{
//    uint32_t         err_code;
//    ble_lbs_c_init_t lbs_c_init_obj;
//
//    lbs_c_init_obj.evt_handler = lbs_c_evt_handler;
//
//    //err_code = ble_lbs_c_init(&m_ble_lbs_c, &lbs_c_init_obj);
//    //APP_ERROR_CHECK(err_code);
//}
//

/**@brief Function for initializing the BLE stack.
 *
 * @details Initializes the SoftDevice and the BLE event interrupts.
 */
static void ble_stack_init(void)
{
    ret_code_t err_code;

    nrf_clock_lf_cfg_t clock_lf_cfg = {
        .source        = NRF_CLOCK_LF_SRC_RC,
        .rc_ctiv       = 16, // bradjc: I mostly made these up based on docs. May be not great.
        .rc_temp_ctiv  = 2,
        .xtal_accuracy = NRF_CLOCK_LF_XTAL_ACCURACY_250_PPM};

    // Initialize the SoftDevice handler module.
    SOFTDEVICE_HANDLER_INIT(&clock_lf_cfg, NULL);

    ble_enable_params_t ble_enable_params;
    err_code = softdevice_enable_get_default_config(CENTRAL_LINK_COUNT,
                                                    PERIPHERAL_LINK_COUNT,
                                                    &ble_enable_params);
    APP_ERROR_CHECK(err_code);

    //Check the ram settings against the used number of links
    CHECK_RAM_START_ADDR(CENTRAL_LINK_COUNT,PERIPHERAL_LINK_COUNT);

    // Enable BLE stack.
    err_code = softdevice_enable(&ble_enable_params);
    APP_ERROR_CHECK(err_code);

    // Register with the SoftDevice handler module for BLE events.
    err_code = softdevice_ble_evt_handler_set(ble_evt_dispatch);
    APP_ERROR_CHECK(err_code);
}


/**@brief Function for handling events from the button handler module.
 *
 * @param[in] pin_no        The pin that the event applies to.
 * @param[in] button_action The button action (press/release).
 */
//static void button_event_handler(uint8_t pin_no, uint8_t button_action)
//{
//    uint32_t err_code;
//
//    switch (pin_no)
//    {
//        case LEDBUTTON_BUTTON_PIN:
//            err_code = ble_lbs_led_status_send(&m_ble_lbs_c, button_action);
//            if (err_code != NRF_SUCCESS &&
//                err_code != BLE_ERROR_INVALID_CONN_HANDLE &&
//                err_code != NRF_ERROR_INVALID_STATE)
//            {
//                APP_ERROR_CHECK(err_code);
//            }
//            if (err_code == NRF_SUCCESS)
//            {
//                NRF_LOG_PRINTF("LBS write LED state %d\r\n", button_action);
//            }
//            break;
//
//        default:
//            APP_ERROR_HANDLER(pin_no);
//            break;
//    }
//}


///**@brief Function for initializing the button handler module.
// */
//static void buttons_init(void)
//{
//    uint32_t err_code;
//
//    //The array must be static because a pointer to it will be saved in the button handler module.
//    static app_button_cfg_t buttons[] =
//    {
//        {LEDBUTTON_BUTTON_PIN, false, BUTTON_PULL, button_event_handler}
//    };
//
//    err_code = app_button_init(buttons, sizeof(buttons) / sizeof(buttons[0]),
//                               BUTTON_DETECTION_DELAY);
//    APP_ERROR_CHECK(err_code);
//}
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
int main(void)
{
    ret_code_t err_code;

    leds_init();

    // UART
    const app_uart_comm_params_t comm_params =
      {
          17,
          16,
          0,
          0,
          APP_UART_FLOW_CONTROL_DISABLED,
          false,
          UART_BAUDRATE_BAUDRATE_Baud9600
      };

    APP_UART_FIFO_INIT(&comm_params,
                         UART_RX_BUF_SIZE,
                         UART_TX_BUF_SIZE,
                         uart_evt_callback,
                         APP_IRQ_PRIORITY_LOW,
                         err_code);

    APP_ERROR_CHECK(err_code);

    APP_TIMER_INIT(APP_TIMER_PRESCALER, APP_TIMER_OP_QUEUE_SIZE, NULL);
    ble_stack_init();

    db_discovery_init();

    // Start scanning for peripherals and initiate connection to devices which
    // advertise.
    //scan_start();
    printf("\n\rSETUP COMPLETE!\n\r");
    led_on(CENTRAL_SCANNING_LED);
    nrf_delay_ms(500);
    led_off(CENTRAL_SCANNING_LED);


    for (;;)
    {
        // Wait for BLE events.
        power_manage();
    }
}

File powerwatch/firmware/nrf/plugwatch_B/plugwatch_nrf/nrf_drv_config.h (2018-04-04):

/* Copyright (c) 2015 Nordic Semiconductor. All Rights Reserved.
 *
 * The information contained herein is property of Nordic Semiconductor ASA.
 * Terms and conditions of usage are described in detail in NORDIC
 * SEMICONDUCTOR STANDARD SOFTWARE LICENSE AGREEMENT.
 *
 * Licensees are granted free, non-transferable use of the information. NO
 * WARRANTY of ANY KIND is provided. This heading must NOT be removed from
 * the file.
 *
 */

#ifndef NRF_DRV_CONFIG_H
#define NRF_DRV_CONFIG_H

/**
 * Provide a non-zero value here in applications that need to use several
 * peripherals with the same ID that are sharing certain resources
 * (for example, SPI0 and TWI0). Obviously, such peripherals cannot be used
 * simultaneously. Therefore, this definition allows to initialize the driver
 * for another peripheral from a given group only after the previously used one
 * is uninitialized. Normally, this is not possible, because interrupt handlers
 * are implemented in individual drivers.
 * This functionality requires a more complicated interrupt handling and driver
 * initialization, hence it is not always desirable to use it.
 */
#define PERIPHERAL_RESOURCE_SHARING_ENABLED  0

/* CLOCK */
#define CLOCK_ENABLED 0

#if (CLOCK_ENABLED == 1)
#define CLOCK_CONFIG_XTAL_FREQ          NRF_CLOCK_XTALFREQ_Default
#define CLOCK_CONFIG_LF_SRC             NRF_CLOCK_LF_SRC_Xtal
#define CLOCK_CONFIG_IRQ_PRIORITY       APP_IRQ_PRIORITY_LOW
#endif

/* GPIOTE */
#define GPIOTE_ENABLED 0

#if (GPIOTE_ENABLED == 1)
#define GPIOTE_CONFIG_USE_SWI_EGU false
#define GPIOTE_CONFIG_IRQ_PRIORITY APP_IRQ_PRIORITY_LOW
#define GPIOTE_CONFIG_NUM_OF_LOW_POWER_EVENTS 1
#endif

/* TIMER */
#define TIMER0_ENABLED 0

#if (TIMER0_ENABLED == 1)
#define TIMER0_CONFIG_FREQUENCY    NRF_TIMER_FREQ_16MHz
#define TIMER0_CONFIG_MODE         TIMER_MODE_MODE_Timer
#define TIMER0_CONFIG_BIT_WIDTH    TIMER_BITMODE_BITMODE_32Bit
#define TIMER0_CONFIG_IRQ_PRIORITY APP_IRQ_PRIORITY_LOW

#define TIMER0_INSTANCE_INDEX      0
#endif

#define TIMER1_ENABLED 0

#if (TIMER1_ENABLED == 1)
#define TIMER1_CONFIG_FREQUENCY    NRF_TIMER_FREQ_16MHz
#define TIMER1_CONFIG_MODE         TIMER_MODE_MODE_Timer
#define TIMER1_CONFIG_BIT_WIDTH    TIMER_BITMODE_BITMODE_16Bit
#define TIMER1_CONFIG_IRQ_PRIORITY APP_IRQ_PRIORITY_LOW

#define TIMER1_INSTANCE_INDEX      (TIMER0_ENABLED)
#endif

#define TIMER2_ENABLED 0

#if (TIMER2_ENABLED == 1)
#define TIMER2_CONFIG_FREQUENCY    NRF_TIMER_FREQ_16MHz
#define TIMER2_CONFIG_MODE         TIMER_MODE_MODE_Timer
#define TIMER2_CONFIG_BIT_WIDTH    TIMER_BITMODE_BITMODE_16Bit
#define TIMER2_CONFIG_IRQ_PRIORITY APP_IRQ_PRIORITY_LOW

#define TIMER2_INSTANCE_INDEX      (TIMER1_ENABLED+TIMER0_ENABLED)
#endif

#define TIMER3_ENABLED 0

#if (TIMER3_ENABLED == 1)
#define TIMER3_CONFIG_FREQUENCY    NRF_TIMER_FREQ_16MHz
#define TIMER3_CONFIG_MODE         TIMER_MODE_MODE_Timer
#define TIMER3_CONFIG_BIT_WIDTH    TIMER_BITMODE_BITMODE_16Bit
#define TIMER3_CONFIG_IRQ_PRIORITY APP_IRQ_PRIORITY_LOW

#define TIMER3_INSTANCE_INDEX      (TIMER2_ENABLED+TIMER1_ENABLED+TIMER0_ENABLED)
#endif

#define TIMER4_ENABLED 0

#if (TIMER4_ENABLED == 1)
#define TIMER4_CONFIG_FREQUENCY    NRF_TIMER_FREQ_16MHz
#define TIMER4_CONFIG_MODE         TIMER_MODE_MODE_Timer
#define TIMER4_CONFIG_BIT_WIDTH    TIMER_BITMODE_BITMODE_16Bit
#define TIMER4_CONFIG_IRQ_PRIORITY APP_IRQ_PRIORITY_LOW

#define TIMER4_INSTANCE_INDEX      (TIMER3_ENABLED+TIMER2_ENABLED+TIMER1_ENABLED+TIMER0_ENABLED)
#endif


#define TIMER_COUNT (TIMER0_ENABLED + TIMER1_ENABLED + TIMER2_ENABLED + TIMER3_ENABLED + TIMER4_ENABLED)

/* RTC */
#define RTC0_ENABLED 0

#if (RTC0_ENABLED == 1)
#define RTC0_CONFIG_FREQUENCY    32678
#define RTC0_CONFIG_IRQ_PRIORITY APP_IRQ_PRIORITY_LOW
#define RTC0_CONFIG_RELIABLE     false

#define RTC0_INSTANCE_INDEX      0
#endif

#define RTC1_ENABLED 0

#if (RTC1_ENABLED == 1)
#define RTC1_CONFIG_FREQUENCY    32768
#define RTC1_CONFIG_IRQ_PRIORITY APP_IRQ_PRIORITY_LOW
#define RTC1_CONFIG_RELIABLE     false

#define RTC1_INSTANCE_INDEX      (RTC0_ENABLED)
#endif

#define RTC_COUNT                (RTC0_ENABLED+RTC1_ENABLED)

#define NRF_MAXIMUM_LATENCY_US 2000

/* RNG */
#define RNG_ENABLED 0

#if (RNG_ENABLED == 1)
#define RNG_CONFIG_ERROR_CORRECTION true
#define RNG_CONFIG_POOL_SIZE        8
#define RNG_CONFIG_IRQ_PRIORITY     APP_IRQ_PRIORITY_LOW
#endif

/* PWM */

#define PWM0_ENABLED 0

#if (PWM0_ENABLED == 1)
#define PWM0_CONFIG_OUT0_PIN        2
#define PWM0_CONFIG_OUT1_PIN        3
#define PWM0_CONFIG_OUT2_PIN        4
#define PWM0_CONFIG_OUT3_PIN        5
#define PWM0_CONFIG_IRQ_PRIORITY    APP_IRQ_PRIORITY_LOW
#define PWM0_CONFIG_BASE_CLOCK      NRF_PWM_CLK_1MHz
#define PWM0_CONFIG_COUNT_MODE      NRF_PWM_MODE_UP
#define PWM0_CONFIG_TOP_VALUE       1000
#define PWM0_CONFIG_LOAD_MODE       NRF_PWM_LOAD_COMMON
#define PWM0_CONFIG_STEP_MODE       NRF_PWM_STEP_AUTO

#define PWM0_INSTANCE_INDEX 0
#endif

#define PWM1_ENABLED 0
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

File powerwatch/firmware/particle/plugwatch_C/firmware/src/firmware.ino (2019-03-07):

/*
 * Project sensor_board_v2
 * Description: For Q2 2018 Deployment in Ghana
 * Author: Noah Klugman; Pat Pannuto
 */

// Native
#include <Particle.h>

// Third party libraries
#include <APNHelperRK.h>
#include <CellularHelper.h>
#include <google-maps-device-locator.h>
#include <OneWire.h>

// Our code
#include "CellStatus.h"
#include "ChargeState.h"
#include "Cloud.h"
#include "ESP8266.h"
#include "FileLog.h"
#include "Gps.h"
#include "Imu.h"
#include "Light.h"
#include "NrfWit.h"
#include "SDCard.h"
#include "Subsystem.h"
#include "Timesync.h"
#include "uCommand.h"
#include "Wifi.h"
#include "firmware.h"
#include "BatteryCheck.h"
#include "product_id.h"

//***********************************
//* TODO's
//***********************************

//  control the debug light
// Default Heartbeat Packet
//  WiT MAC
// Heartbeat Stretch goals
//  SMS Heartbeat
//Tests
//  Device comes back from dead battery

//***********************************
//* Critical System Config
//***********************************

#ifdef PRODUCT
int product_id = PRODUCT;
PRODUCT_ID(PRODUCT);
#else
int product_id = 7009;
PRODUCT_ID(7009);
#endif

int version_int = 28; 
PRODUCT_VERSION(28);

SYSTEM_THREAD(ENABLED);
STARTUP(System.enableFeature(FEATURE_RESET_INFO));
STARTUP(System.enableFeature(FEATURE_RETAINED_MEMORY));
SYSTEM_MODE(MANUAL);
bool handshake_flag = false;
OneWire ds(B0);
String id(void);
String shield_id = "";

//**********************************
//* Pin Configuration
//**********************************
int reset_btn = A0;

//***********************************
//* Watchdogs
//***********************************
const int HARDWARE_WATCHDOG_TIMEOUT_MS = 1000 * 60;
ApplicationWatchdog wd(HARDWARE_WATCHDOG_TIMEOUT_MS, soft_watchdog_reset);
unsigned long system_cnt = 0;
retained unsigned long reboot_cnt = 0;
retained unsigned long sd_cnt = 0;

//***********************************
//* SD Card
//***********************************
SDCard SD;

//***********************************
//* ESP8266 WIFI Module
//***********************************
auto esp8266 = ESP8266();

//***********************************
//* Timesync
//***********************************
auto timeSyncSubsystem = Timesync();

//***********************************
//* CellStatus
//***********************************
auto cellStatus = CellStatus();

//***********************************
//* Charge state
//***********************************
auto chargeStateSubsystem = ChargeState();

//***********************************
//* IMU
//***********************************
retained int IMU_MOTION_THRESHOLD = Imu::DEFAULT_MOTION_THRESHOLD;
auto imuSubsystem = Imu(&IMU_MOTION_THRESHOLD);

//***********************************
//* LIGHT
//***********************************
auto lightSubsystem = Light();

//***********************************
//* NrfWit
//***********************************
auto nrfWitSubsystem = NrfWit();

//***********************************
//* uCommand
//***********************************
uCommand uCmd;

//***********************************
//* WIFI
//***********************************
auto wifiSubsystem = Wifi(esp8266);

//***********************************
//* GPS
//***********************************
auto gpsSubsystem = Gps();

//***********************************
//* System Events
//***********************************
retained char event_log_name[50];
auto EventLog = FileLog(SD, "event_log.txt", event_log_name);
std::queue<String> EventQueue;
std::queue<String> CloudQueue;
std::deque<String> DataDeque;

//***********************************
//* Battery check
//***********************************
BatteryCheck batteryCheck(5, 60);
unsigned long last_cloud_event = 0;

//***********************************
//* System Data
//***********************************
retained char data_log_name[50];
auto DataLog = FileLog(SD, "data_log.txt", data_log_name);
unsigned long last_logging_event  = 0;

//***********************************
//* UDP
//***********************************
//UDP udp;


// String SYSTEM_EVENT = "s";
retained int system_event_count = 0;
retained String last_system_event_time = "";
retained int last_system_event_type = -999;
retained int num_reboots = 0;
retained int num_manual_reboots = 0;

volatile int network_state = 0;
volatile int cloud_state = 0;

void handle_all_system_events(system_event_t event, int param) {
  system_event_count++;
  // cast as per BDub post here: https://community.particle.io/t/system-events-param-problem/32071/14
  if((uint32_t)event == 64) {
    cloud_state = param;
  }

  if((uint32_t)event == 32) {
    network_state = param;
  }

  Serial.printlnf("got event H: %lu event L: %lu with value %d", (uint32_t)(event>>32), (uint32_t)event, param);
  String system_event_str = String((int)event) + "|" + String(param);
  String time_str = String(Time.format(Time.now(), TIME_FORMAT_ISO8601_FULL));
  last_system_event_time = time_str;
  last_system_event_type = param;

  //Push this system event onto the queue to be logged in the error logging state
  if(EventQueue.size() < 200) {
    EventQueue.push(time_str + ": " + system_event_str);
  }
}
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

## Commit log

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2016-12-03 random gridwatch samples. tighter intergration with firebase. firebase init in app so each service can have it. watchdog services no longer crash (error was due to mistake in casting). Watchdog servi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
2017-10-13 adding in rev1 board
    [electron_mpu9250_analog_mic.brd, electron_mpu9250_analog_mic.sch]
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2017-10-17 fixed grid issue in schematic. added sd card. added incomplete gas sensors
    [electron_mpu9250_analog_mic.brd, electron_mpu9250_analog_mic.sch]
2017-10-17 added in that good looking Cal logo... woooooo... also did a bit more wiring for the gas sensors
    [electron_mpu9250_analog_mic.brd, electron_mpu9250_analog_mic.sch]
2017-10-17 generic gas sensors hooked up... haven't set up fancy CO relay thing yet. Don't know if it's worth it. Also last commit had gas sensors wired incorrectly
    [electron_mpu9250_analog_mic.brd, electron_mpu9250_analog_mic.sch]
2017-10-17 gas sensors powered from battery now
    [electron_mpu9250_analog_mic.brd, electron_mpu9250_analog_mic.sch]
2017-10-17 fixed stupid error with solder jumper...
    [electron_mpu9250_analog_mic.brd, electron_mpu9250_analog_mic.sch]
2017-10-17 seperate solder jumpers for gas sensors
    [electron_mpu9250_analog_mic.brd, electron_mpu9250_analog_mic.sch]
2017-10-17 mainly cosmetic changes to schematic. changed label types
    [electron_mpu9250_analog_mic.brd, electron_mpu9250_analog_mic.sch]
2017-10-17 ugh. stupid error in solder jumpers
    [electron_mpu9250_analog_mic.brd]
2017-10-20 before ripping everything up and removing the timer
    [electron_mpu9250_analog_mic.brd, electron_mpu9250_analog_mic.sch]
2017-10-21 reroute with a single gas sensor
    [electron_mpu9250_analog_mic.brd, electron_mpu9250_analog_mic.sch]
2017-10-21 ugh, rewire w out gas sensor. need to add fet for power cycling the sd card and then will ship
    [electron_mpu9250_analog_mic.brd, electron_mpu9250_analog_mic.sch]
2017-10-21 reroute w out gas sensor. almost ready to ship
    [electron_mpu9250_analog_mic.brd, electron_mpu9250_analog_mic.sch]
2017-10-23 adding in cost spreadsheet.
    [costs.xlsx, electron_mpu9250_analog_mic.brd]
2017-10-23 adding in order documentation
    [costs.xlsx, digikey.csv, electron_mpu9250_analog_mic.csv]
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2018-01-15 Cleanup for revision 2 work
    [costs.xlsx, digikey.csv, electron_mpu9250_analog_mic.brd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]
2018-01-15 Little bit of cleanup
    [asset-tracker-v008.sch, costs.xlsx, digikey.csv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]
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2018-01-17 Working through rev2 schematic
    [noah_electron_layout_2.brd, noah_electron_layout_2.sch, plugwatch.brd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]
2018-01-17 Added part numbers and notes
    [plugwatch.brd, plugwatch.sch]
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2018-01-20 added board outline and annotations
    [plugwatch.brd]
2018-01-21 added wires and USB cable, cleaned up holes, added electrical parts
    [S-series-2X-Top(2-2)-1.SLDPRT, antenna.SLDPRT, case_assembly.SLDASM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]
2018-01-21 firmware: fix charge_state cloud
    [FileLog.cpp, PowerCheck.cpp, firmware.ino]
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2018-01-21 locked key parts on board, added LED
    [plugwatch.brd, plugwatch.sch]
2018-01-21 moved part on sensor board
    [case_assembly.SLDASM, sensor_board.SLDPRT]
2018-01-21 moved battery to better location
    [case_assembly.SLDASM]
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2018-01-22 added other case drawing
    [s-series-02-12(12).SLDDRW]
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2018-01-22 firmware: handler ISR's correctly for logs
    [FileLog.cpp]
2018-01-22 Nothing to do!
    Still need to review DRC, clean up signals, and add testpoints.
    [plugwatch.brd, plugwatch.sch]
2018-01-22 Reroute, move signals on Electron
    Add names/dates/revision
    [plugwatch.brd, plugwatch.sch]
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2018-01-23 Fixed a schematic boo boo
    [plugwatch.brd, plugwatch.sch]
2018-01-23 Fix BLE VCC, testpoints, labels, relabel parts
    [plugwatch.brd, plugwatch.sch]
2018-01-23 Fix BOM issues
    [plugwatch.brd, plugwatch.sch, plugwatch_bom.xlsx]
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2018-01-23 add the fixed power switch
    [plugwatch.brd, plugwatch.sch]
2018-01-23 fix up silkscreen
    [plugwatch.brd, plugwatch.sch]
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2018-01-24 remove old assembler files and old design
    [noah_electron_layout_2.brd, noah_electron_layout_2.sch]
2018-01-24 fixed up silk, renumber chips
    [plugwatch.brd, plugwatch.sch]
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2018-02-10 Revert "Attempt to reduce extraneous processing"
    This reverts commit 577a7881a3a2050c27aec10ca732c21b16744c69.
    [FileLog.cpp]
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2018-02-17 Start to rev C
    [plugwatch.brd, plugwatch.sch]
2018-02-17 Tried to address a lot of #2
    Still need prefilter audio output
    Need a check over 60hz antenna stuff
    [plugwatch.brd, plugwatch.sch]
2018-02-21 add plugwatch last fixes
    [plugwatch.brd, plugwatch.sch]
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2018-03-30 added in dip switch, 1-wire serial number, removed rc filter
    [plugwatch.brd, plugwatch.sch]
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2018-03-30 moved programmer and reset for NRF
    [plugwatch.brd]
2018-03-30 fixed library parts and added pulldowns
    specifically
    - made sure origins were at the center of the part
    - fixed ds2401p+ lan pattern to match maxim spec
    - changed text ratios to 12
    - changed attribute fields to match rest of BOM
    [plugwatch.brd, plugwatch.sch]
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2018-04-03 add updated CAM files
    [plugwatch_bom.csv, plugwatch_bom.xlsx]
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2018-04-04 nrf: actually get uart correct
    [main.c]
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2018-04-15 added in reset button, gps, more information in heartbeat, modified publish queue library (added priorities), fixed SD card write errors, changed softwarewatchdog, added new keepalive periodic call
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2018-05-11 fixing dumbness w onewire
    [firmware.ino]
2018-05-13 fixed function names in chargestate
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2018-05-13 fixed up classes in frimware, also removed unneeded declaration params
    [firmware.ino]
2018-05-13 split off the timesync class
    Having it in the firmware file was causing a really strange compilation
    error in firmware.cpp (which of course does not exist)
    [firmware.ino]
2018-05-14 fix headers
    I promise this isn't just a neurosis, particularly the 3rd party vs us
    split makes it some much nicer when trying to track down code
    [firmware.ino]
2018-05-14 I'm sorry, I literally couldn't read it
    I kept confusing how the nested cases were executing. I didn't even
    know you could put breaks outside of the case blocks.
    [firmware.ino]
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2018-05-15 fix sd card power cycling, add sd card detect
    SD card detect seems to be hardware broken on my board
    [firmware.ino]
2018-05-15 add cloud error logging and state hang logging
    [FileLog.cpp, firmware.ino]
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2018-05-15 added wit to code
    This means it's not working
    [NrfWit.cpp, firmware.ino]
2018-05-16 fix data length error
    [firmware.ino]
2018-05-16 slow down upload, fix error transition and catching
    [firmware.ino]
2018-05-16 fix state init and unsigned long bug
    [firmware.ino]
2018-05-16 check states after reset
    [firmware.ino]
2018-05-16 This seems to actual fix teh retained state problem
    [firmware.ino]
2018-05-16 this commit fixes wifi error codes and imu on reset
    The wifi was not returning an error when it couldn't read, it was just
    hanging. The IMU would always report motion on reset. This commit fixes
    those problems
    [ESP8266.cpp, Imu.cpp, firmware.ino]
2018-05-17 version 12 removes safe mode reset
    [firmware.ino]
2018-05-17 add enable charging call and fix build
    [PowerCheck.cpp, firmware.ino]
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2018-05-19 fix NRF serial parsing to net error so often
    [NrfWit.cpp]
2018-05-20 this seems to fix the charging problem
    [PowerCheck.cpp, firmware.ino]
2018-05-20 fix advertisement parsing/checking
    The decimal point shift is wrong in the wit docs
    [main.c]
2018-05-20 added file size, periodic reset, more reporing
    specifically reporting:
    loop count
    system ID
    sd write count
    sd file size
    [FileLog.cpp, firmware.ino]
2018-05-20 power off wifi, add battery check, fix packet logging
    [ESP8266.cpp, firmware.ino]
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2018-05-21 guard against not having a cloud connection. Fix event logging
    [firmware.ino]
2018-05-21 record time at sensing, fix cell status, add data queueing
    [firmware.ino]
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2018-05-22 fix battery check to look at the powercheck signal
2018-05-22 fix millis
2018-05-27 fix connection and manual handshake forcing
    [predeploy_firmware.ino]
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2018-05-31 fix port filter
2018-06-02 add time filter and corrector
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2018-06-03 Starting changes for rev 4
    - Default off for all peripherals
    - Remove 60Hz detector (to be updated)
    - Remove APN switch
    [plugwatch.brd, plugwatch.sch]
2018-06-03 added power supervisory circuit
    [plugwatch.brd, plugwatch.sch]
2018-06-03 change voltage input to also have WDI
    [plugwatch.brd, plugwatch.sch]
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2018-06-29 add new power supply with updated board shape
    [plugwatch.brd, plugwatch.sch]
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2018-07-04 added AC voltage sense and perturb/observe cap sensing
    [plugwatch.brd, plugwatch.sch]
2018-07-04 add rtc and descriptions, remove BLE
    [plugwatch.brd, plugwatch.sch]
2018-07-04 add mic, remove many old things, connect RTC, new Accel
    [plugwatch.brd, plugwatch.sch]
2018-07-04 started rough section layout
    [plugwatch.brd]
2018-07-04 switch the gnd float mosfet?
    [plugwatch.brd, plugwatch.sch]
2018-07-04 a new mosfet configuration
    [plugwatch.brd, plugwatch.sch]
2018-07-04 remove mosfets - I don't think they are necessary
    [plugwatch.brd, plugwatch.sch]
2018-07-04 add inverter to watchdog reset line
    [plugwatch.brd, plugwatch.sch]
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2018-07-06 almost finished routing - still need to do debug signals
    [plugwatch.brd, plugwatch.sch]
2018-07-06 layed out debug header, most of the way done routing
    [plugwatch.brd, plugwatch.sch]
2018-07-06 only 4 more airwires
    [plugwatch.brd]
2018-07-06 fixed based on case, rerouted, some of the silk
    [plugwatch.brd, plugwatch.sch]
2018-07-06 fixed some layout
    [plugwatch.brd]
2018-07-06 fix library, add labels to board
    [plugwatch.brd, plugwatch.sch]
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2018-07-07 fixed up BOM and attributes
    [plugwatch.brd, plugwatch.csv, plugwatch.sch]
2018-07-08 adding case files so I dont' lose them again
    [antenna.SLDPRT, bottom_case.SLDPRT, case_assembly.SLDASM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]
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2018-07-10 two testpoints were on the wrong side
    [plugwatch.brd]
2018-07-10 regenerated gerbers after layer fix
2018-08-03 remove RST line that no longer exists
    [ESP8266.cpp]
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2018-08-06 particle needs to fix their shitty web compiler
    [Imu.cpp, firmware.ino]
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2018-09-15 checking off github issues
    [plugwatch.brd, plugwatch.sch]
2018-10-25 refactor organization of this repo - it was out of hand
    [S-series-2X-Top(2-2)-1.SLDDRW, S-series-2X-Top(2-2)-1.SLDPRT, antenna.SLDPRT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]
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2018-10-31 fix AB1815 library, update timesync to use it, can't power off SD while
    using RTC
    [AB1815.cpp, firmware.ino]
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2018-11-01 fix RTC battery backup circuit, rename mislabeled SCL
    [plugwatch.brd, plugwatch.sch]
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2018-11-01 board order ready, BOM updated with purchasable parts
    [plugwatch.brd, plugwatch.csv, plugwatch.sch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]
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2018-11-29 fix the build so that the product IDs are actually in the hex
    [firmware.ino]
2018-11-30 add nigeria apn and fix deploy firmware tool
    [firmware.ino]
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2019-02-17 add plugwatch_F predeploy
    This stops the sensors from resetting on plug in
    [predeploy_firmware.ino]
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2019-02-23 added extra info about device errors, fixed errors from cleaning script
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2019-03-07 fix frame name
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

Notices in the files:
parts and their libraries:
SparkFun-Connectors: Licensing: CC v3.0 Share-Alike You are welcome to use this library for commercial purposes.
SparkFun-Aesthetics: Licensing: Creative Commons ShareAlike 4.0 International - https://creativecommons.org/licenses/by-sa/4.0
